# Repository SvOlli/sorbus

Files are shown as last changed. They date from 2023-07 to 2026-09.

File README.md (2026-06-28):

The Sorbus Computer
===================

The attempt to build a very simple 65C02 based computer by utilizing a
Raspberry Pi Pico clone for the rest of the functionality. More
documentation is available at
[https://sorbus.xayax.net/](https://sorbus.xayax.net/).

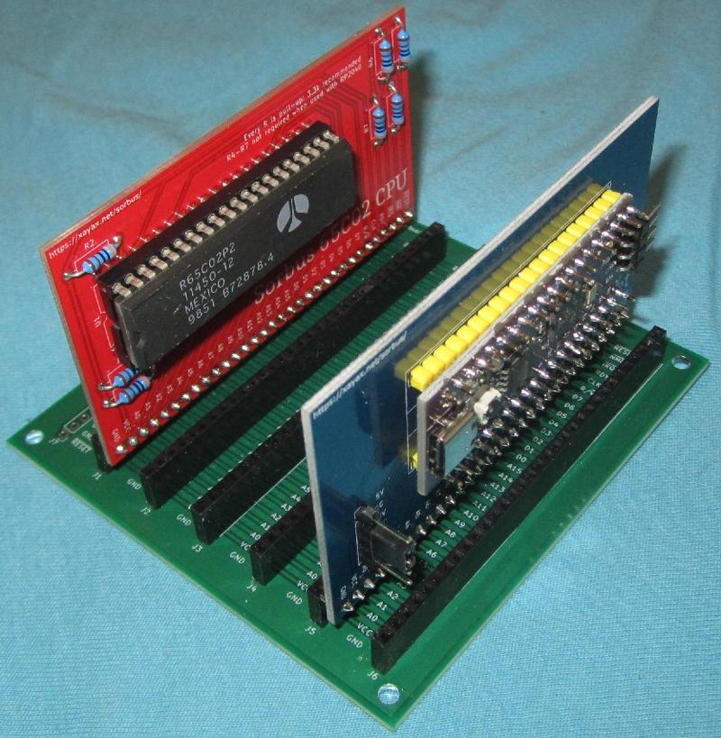
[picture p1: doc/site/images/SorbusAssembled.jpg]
Sorbus assembled

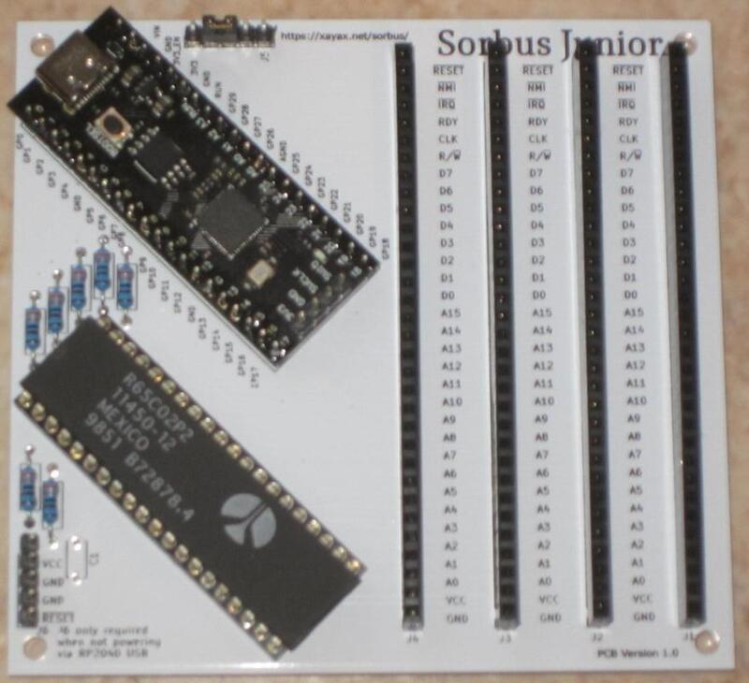
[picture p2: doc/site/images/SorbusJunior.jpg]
Sorbus Junior


The Project is capabile to run as an [Apple Computer 1](doc/site/apple1.md)
as well as an own monitor command prompt (mcp) to learn about the 65C02
processor and it siblings. However now the main focus is now on creating
a custom computer, using a code called "JAM" (Just Another Machine).

The project is fully open source, licensend under GPL v3:
  - the PCB design is in the folder pcb/
    - the Raspberry Pi Pico clone is found under the term "Purple PR2040"
      on AliExpress and other sites
    - the clone is used because all GPIOs of the RP2040 are required
  - the 65C02 source code to run on the target is at src/65c02/
    - compiling requires the [cc65](https://cc65.github.io/), which
      needs to be preinstalled.
  - the source code for the Raspberry Pi Pico clone is at `src/rp2040/`
    - compiling requires the
      [Pico-SDK](https://github.com/raspberrypi/pico-sdk) from the
      Raspberry Pi Foundation, which will be downloaded if not previously
      configured. However it's dependencies must also be preinstalled.
  - for generating the CP/M-65 filesystem
    [cpmtools](https://github.com/lipro-cpm4l/cpmtools) is also required

[An addtional page](https://xayax.net/sorbus/) has been setup to explain more
about the ideas of the system, as well as some usecases.

Also there is now an
[independent review](http://retro.hansotten.nl/the-sorbus-computer/)
available at the wonderful
[Retro Computing pages](http://retro.hansotten.nl/) of Hans Otten.

As part of creating a full featured computer, there are also two expansion
boards developed here: a sound card, called "Sorbus Sound" and a graphics
card, called "Sorbus VGA".

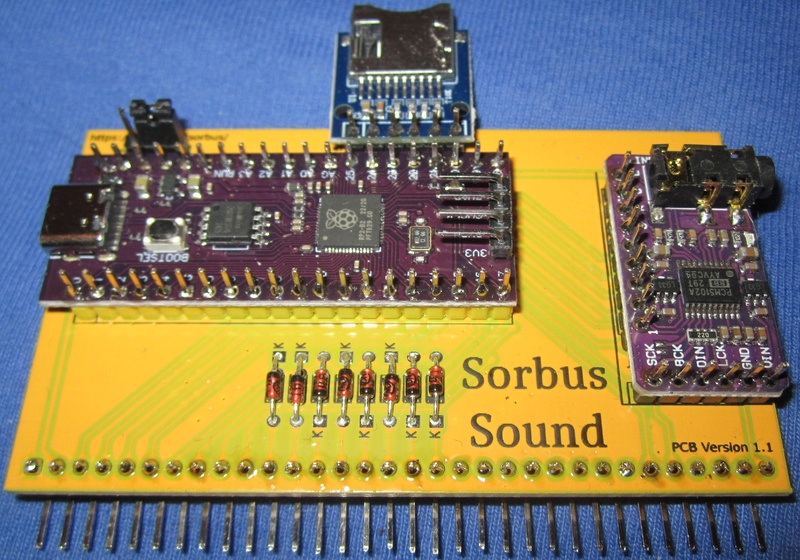
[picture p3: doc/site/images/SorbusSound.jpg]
Sorbus Sound

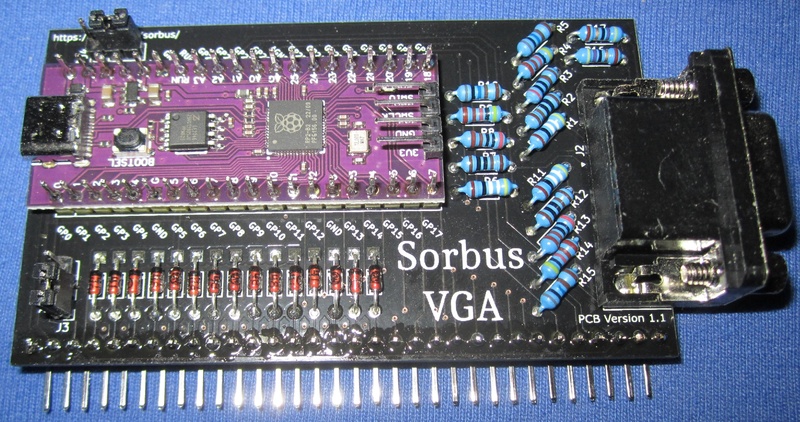
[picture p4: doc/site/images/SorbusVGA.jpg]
Sorbus VGA


To access the RP2040 without super user rights, make sure that your user is
in the groups "plugdev" and "dialout". You also need to add a udev rule. This
is available as part of picotool in the `udev` folder.

Build Targets
-------------

The toplevel `Makefile` is added as a convenience layer to build things more
easily. It wraps the call of `cmake` and `make` to configure the Raspberry Pi
Pico project, as well as some other useful things. The following make targets
are available:

  - make all
    - checks for availablilty of the Pico SDK and downloads it, if required
    - creates a new build directory
    - wraps the call to `cmake` and `make` to build the project
  - make log
    - almost same as "all"
    - more verbose compilation, e.g. compiler calls with parameters
    - creates a file `make.log`
  - make clean
    - runs a `make clean` on build directory
  - make distclean
    - removes build directory entirely to force restart from scratch
  - make setup-apt-build-only
    - installs packages on Debian required to build the project
    - used by git actions to prepare building of a release
  - make setup-apt-dev
    - runs "setup-apt-build-only", as well as doing modifications to
      make sure that terminal and all host dev packages are installed,
      so picotool is compiled with support for transferring software
  - make picotool
    - checks out and builds picotool
    - however there this has been superseded by
      src/tools/local-picotool.sh (and src/tools/local-nstow.sh)
  - make setup-external
    - sets up tools required to build external code, like
      - [CP/M 65](https://github.com/davidgiven/cpm65) (requires
        [llvm-mos-sdk](https://github.com/llvm-mos/llvm-mos-sdk))
      - [TaliForth2](https://github.com/SamCoVT/TaliForth2)
        (requires [64tass](https://tass64.sourceforge.net/))
  - make release
    - used by git action to build a release

There are also some build scripts available for special cases:

  - src/tools/upload.sh
    - script used to build and transfer software using picotool
      (needs rewrite)
    - defaults to uploading the JAM core
  - src/tools/external-taliforth2.sh
    - script to checkout, build and install the TaliForth2
      binary ready for building the filesystem image
    - only required for native core
  - src/tools/external-cpm65.sh
    - script to checkout, build and install the files required
      to include CP/M 65 into the filesystem image
    - only required for native core

It is also possible to build C programs using cc65 for this computer. This
is rather a proof of concept that a full featured implementation, but it
does work rather stable. More details are in it's own
[README](cc65-sdk/README.md).

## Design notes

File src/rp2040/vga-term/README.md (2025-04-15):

https://github.com/RC2014Z80/picoterm.git

todo
====

- remove pio_fatfs
- change uart -> $01

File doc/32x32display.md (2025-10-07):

Sorbus 32x32 LED Display
========================

The panels built so far use this order of LEDs.

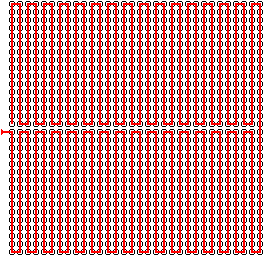
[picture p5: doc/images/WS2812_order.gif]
LED order


I/O Registers
-------------

I/O utilizes the page $D3xx. All registers are write only, as the hardware
only sniffes the bus and never actively drives it.

- $D300: DMA into framebuffer and flush (strobe register)
- $D301: DMA into framebuffer without flush (strobe register)
- $D302/3: start address of RAM source
- $D304/5: startpixel of framebuffer target (10 bit, absolute address)
- $D306/7: startpixel of framebuffer X/Y format (5 bit each)
- $D308: width of DMA in pixels-1 (5 bit, $00=one pixel, $1f sets a full line)
- $D309: height of DMA in pixels-1 (5 bit, $00=one line, $1f sets full height)
- $D30A: linestep of source in pixels-1 (8 bit)
- $D30B: transparency color
- $D30C: colormap
- $D30D: custom colormap id register (valid value: 1-3)

- $D310: red color for custom colormap
- $D311: green color for custom colormap
- $D312: blue color for custom colormap

(defaults are starting at $d302: $00,$cc,$00,$00,$00,$00,$1f,$1f,$1f,$00,$00)

If not all bits of a register are required, those will be masked out/ignored.

Value written do $D300/1 indicades mode (can be or'ed together):
- $00: plain copy
- $01: transparency: no copy when source color = transparent
- $02: transparency: no copy when destination color = transparent
- $04: transparency: only copy when destination color = transparent
- $06: do nothing

Color palettes:
- $00: Insane's RGBI2222
- $01: Custom 1
- $02: Custom 2
- $03: Custom 3
- $04: C64 like
- $05: C16 like
- $06: Atari 8-bit like
- $07: Atari 8-bit like, ordered differently
- $08: Veto's custom curated
- $09: Coder colors

Custom defined color palettes are always specified in RGB444. Writing
to $D30D resets internal index of $D310-$D312 to $00, when a colorvalue
is written, lower 4 bits will be taken as value for this index, and the
index will be incremented. Once $100 color values has been written,
that color slot does not take new color values. Adding $80 to the index
value will fill the palette in reverse order starting with $ff going
down. If a value other than $01-$03 and $81-$83 is written to $D30D,
then $D310-$D312 will not accept any data.

Also selecting the colormap by writing to $D30C copies the palette to the
"current palette", so only then the data is updated not during writing to
$D310-$D312.

Since the board just sniffes the bus, DMA from internal drive or swap
pages is not detected.

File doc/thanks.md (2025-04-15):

Thanks
======

This project is standing on the shoulder of giants. While it was started from
scratch, a lot of other code got integrated.

A lot of code was contributed from other sources, sometimes even without
the knowledge of the author(s).

This project uses software that was developed under non-free licenses.

65(C)02 Based Code
------------------

All of this code has been modified to some degree to fit this project, the
Sorbus Computer. The focus is always on make things work good on the hardware
and not on keeping code as original as possible.

### MOS TIM

* [src/65c02/jam/rom/tim.s](../src/65c02/jam/rom/tim.s)

This is the Terminal Interface Monitor (TIM) of the MOS 6530-004.
```
Copyright 1976 MOS Technology
```
License terms: unknown

### WozMon

* [src/65c02/jam/rom/woz.s](../src/65c02/jam/rom/woz.s)

This is WozMon of the Apple 1 Computer
```
Written by Steve Wozniak
Copyright 1976 Apple Computer Company
```
License terms: unknown

### Apple direct assembler/disassembler

* [src/65c02/jam/mon/assembler.s](../src/65c02/jam/mon/assembler.s)
* [src/65c02/jam/mon/disassembler.s](../src/65c02/jam/mon/disassembler.s)
* [src/65c02/jam/mon/table6502.s](../src/65c02/jam/mon/table6502.s)
* [src/65c02/jam/mon/table65sc02.s](../src/65c02/jam/mon/table65sc02.s)

```
Apple //c & Apple II
Monitor ROM Source

Copyright 1977-1983 by Apple Computer, Inc.
All Rights Reserved

S. Wozniak         1977
A. Baum            1977
John A         NOV 1978
R. Auricchio   SEP 1982
E. Beernink        1983
```
License terms: unknown

### Microsoft BASIC 1.0

* [src/65c02/jam/rom/osi_basic.s](../src/65c02/jam/rom/osi_basic.s)

```
This is OSI BASIC V1.0 REV 3.2
Written by Richard W. Weiland
Copyright 1977 Microsoft Co.
```
It has been used with computers manufactured by
[Ohio Scientific Inc.](https://en.wikipedia.org/wiki/Ohio_Scientific)

Reverse engineering was started by Michael Steil
Source code is based on version by Grant Searle for his simple 6502 computer.

License terms: unknown

### Instant Assembler

* [src/65c02/jam/sx4/inst-ass.s](../src/65c02/jam/sx4/inst-ass.s)

This is Instant 6502 Assembler for KIM-1
```
Written by Alan Cashin
```
License terms: released as public domain

RP2040 Code
-----------

### Dhara - NAND flash management layer

* [src/rp2040/3rdparty/dhara](../src/rp2040/3rdparty/dhara)

```
Dhara - NAND flash management layer
Copyright (C) 2013 Daniel Beer <dlbeer@gmail.com>
```
License terms: BSD-2-Clause

### Mod Player

* [src/rp2040/3rdparty/c-flod](../src/rp2040/3rdparty/c-flod)

```
Christian Corti
Neoart Costa Rica
```
License terms: Creative Commons Attribution-Noncommercial-Share Alike 3.0

### SID Emulation

* [src/rp2040/3rdparty/reSID16](../src/rp2040/3rdparty/reSID16)

```
Dag Lem: Designed and programmed complete emulation engine.
```
License terms: GPL 2.0

### FAT Filesystem

* [src/rp2040/3rdparty/fatfs](../src/rp2040/3rdparty/fatfs)

```
Copyright (c) 2020-2021, Elehobica
```
License terms: BSD-2-Clause

### PicoTerm

[src/rp2040/vga-term](../src/rp2040/vga-term)

```
Copyright 2023 by S.Dixon & D.Meurisse
```
License terms: BSD-3-Clause

### Raspberry Pi Pico Examples

On several occasions things were taken from Raspberry Pi Pico examples:
```
Copyright (c) 2020 Raspberry Pi (Trading) Ltd.
```
License terms: BSD-3-Clause

Special Thanks
--------------

- Benson of Tristar & Red Sector inc. for a lot of contributions
- David Given, author of CP/M for the 6502
  - provided an operating system for the Sorbus
  - helped on implementing the dhara wear leveling for the flash
- [Life with David](https://www.youtube.com/@LifewithDavid1)
  - Especially [PIO examples](https://github.com/LifeWithDavid/Raspberry-Pi-Pico-PIO)
- Hans Otten
  - [http://retro.hansotten.nl](http://retro.hansotten.nl) is one of the best
    resources on SBCs from the 1970s and 1980s.

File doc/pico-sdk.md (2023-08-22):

Linklist of most frequently visited Pico-SDK documentation pages
----------------------------------------------------------------

* [gpio](https://www.raspberrypi.com/documentation/pico-sdk/gpio_8h.html)
* [queue](https://www.raspberrypi.com/documentation/pico-sdk/queue_8h.html)
* [runtime](https://www.raspberrypi.com/documentation/pico-sdk/runtime.html)
* [cyw43 (wifi)](https://www.raspberrypi.com/documentation/pico-sdk/cyw43_8h.html)

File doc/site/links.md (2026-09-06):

# Links

## Beyond The Scope Of This Documentation

* [GitHub Repository](https://github.com/SvOlli/sorbus)
* [Self-Hosted Backup Repository](https://git.h8u.de/Sorbus/github)
* [Original Homepage](https://xayax.net/sorbus/)

## Videos

* [37C3 Lightning Talk (2023)](https://xayax.net/sorbus/lightning1.php)
* [Revision Seminar (2025)](https://youtu.be/5KmBh-jR7Vs)
* [1k LEDs Is No Limit (2025)](https://xayax.net/1k_leds_is_no_limit/),
  a demo running on the Sorbus Computer with a Sound Board and 32x32 WS2812
  LEDs expansion.

## Other People

* [Hans Otten's Series Of Pages](http://retro.hansotten.nl/the-sorbus-computer/)

## Helpful Sites

* [Compiler Explorer](https://godbolt.org/), select ARM GCC 12.2.1
  -mcpu=cortex-m0plus -mthumb -mfloat-abi=softfp -g -O3 -DNDEBUG
  -Wunused-variable -ffunction-sections -fdata-sections

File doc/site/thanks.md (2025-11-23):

# Thanks

This project is standing on the shoulder of giants. While it was started from
scratch, a lot of other code got integrated during the development.

A lot of code was contributed from other sources, sometimes even without
the knowledge of the author(s).

This project uses software that was developed under non-free licenses.

## 65(C)02 Based Code

All of this code has been modified to some degree to fit this project, the
Sorbus Computer. The focus is always on make things work good on the hardware
and not on keeping code as original as possible.

### MOS TIM

This is the Terminal Interface Monitor (TIM) of the MOS 6530-004.
```txt
Copyright 1976 MOS Technology
```
License terms: unknown

* src/65c02/jam/rom/tim.s

### WozMon

This is WozMon of the Apple 1 Computer
```txt
Written by Steve Wozniak
Copyright 1976 Apple Computer Company
```
License terms: unknown

* src/65c02/jam/rom/woz.s

### Apple Direct Assembler/Disassembler And Monitor

```txt
Apple //c & Apple II
Monitor ROM Source

Copyright 1977-1983 by Apple Computer, Inc.
All Rights Reserved

S. Wozniak         1977
A. Baum            1977
John A         NOV 1978
R. Auricchio   SEP 1982
E. Beernink        1983
```
License terms: unknown

* src/65c02/jam/mon/assembler.s
* src/65c02/jam/mon/disassembler.s
* src/65c02/jam/mon/table6502.s
* src/65c02/jam/mon/table65sc02.s
* src/65c02/jam/sx4/wozmon2c.s

### Microsoft BASIC 1.0

```txt
This is OSI BASIC V1.0 REV 3.2
Written by Richard W. Weiland
Copyright 1977 Microsoft Co.
```
It has been used with computers manufactured by
[Ohio Scientific Inc.](https://en.wikipedia.org/wiki/Ohio_Scientific)

Reverse engineering was started by Michael Steil
Source code is based on version by Grant Searle for his simple 6502 computer.

License terms: MIT (version 1.1 which also includes OSI)

* src/65c02/jam/rom/osi_basic.s

### Instant Assembler

This is Instant 6502 Assembler for KIM-1
```txt
Written by Alan Cashin
```
License terms: released as public domain

* src/65c02/jam/sx4/inst-ass.s

## RP2040 Code

### Dhara - NAND flash management layer

```txt
Dhara - NAND flash management layer
Copyright (C) 2013 Daniel Beer <dlbeer@gmail.com>
```
License terms: BSD-2-Clause

* src/rp2040/3rdparty/dhara

### mcurses lib

```txt
Copyright (c) 2011-2015 Frank Meyer - frank(at)uclock.de
```
License terms: GPL v2 or later

* src/rp2040/common/mcurses.c
* src/rp2040/common/mcurses.h
* src/rp2040/common/mcurses_hexedit.c

### XModem

```txt
Copyright 2006 Arastra, Inc.
Copyright 2001, 2002 Georges Menie (www.menie.org)
```
License terms: LGPL v2 or later

* src/rp2040/3rdparty/xmodem/xmodem.c
* src/rp2040/3rdparty/xmodem/xmodem.h
* src/rp2040/common/xmodem.c

### Mod Player

```txt
Christian Corti
Neoart Costa Rica
```
License terms: Creative Commons Attribution-Noncommercial-Share Alike 3.0

* src/rp2040/3rdparty/c-flod

### SID Emulation

```txt
Dag Lem: Designed and programmed complete emulation engine.
```
License terms: GPL 2.0

* src/rp2040/3rdparty/reSID16

### FAT Filesystem

```txt
Copyright (c) 2020-2021, Elehobica
```
License terms: BSD-2-Clause

* src/rp2040/3rdparty/fatfs

### PicoTerm

```txt
Copyright 2023 by S.Dixon & D.Meurisse
```
License terms: BSD-3-Clause

* src/rp2040/vga-term

### Raspberry Pi Pico Examples

On several occasions things were taken from Raspberry Pi Pico examples:
```txt
Copyright (c) 2020 Raspberry Pi (Trading) Ltd.
```
License terms: BSD-3-Clause

## Special Thanks

- Benson of [Tristar & Red Sector inc.](https://trsi.org/) for a lot of
  contributions
- David Given, author of [CP/M for the 6502](https://github.com/davidgiven/cpm65)
    - provided an operating system for the Sorbus
    - helped on implementing the dhara wear leveling for the flash
- [Life with David](https://www.youtube.com/@LifewithDavid1)
    - especially for his [PIO examples](https://github.com/LifeWithDavid/Raspberry-Pi-Pico-PIO)
- Hans Otten
    - [http://retro.hansotten.nl](http://retro.hansotten.nl) is one of the best
      resources on SBCs from the 1970s and 1980s.

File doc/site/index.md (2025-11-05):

# The Sorbus Computer

The Sorbus Computer is a small, cheap, and expandable computer based upon
the [6502](https://en.wikipedia.org/wiki/MOS_Technology_6502) or rather
the [65C02](https://en.wikipedia.org/wiki/WDC_65C02) CPU and an
[RP2040](https://en.wikipedia.org/wiki/RP2040) microcontroller from
Raspberry Pi. It is fully open source, the [source code is available
at GitHub](https://github.com/SvOlli/sorbus).

The means that even the hardware is for the most part software written
in C. The kernel for the 65C02 is written using the ca65 assembler from
the [cc65](https://github.com/cc65/cc65) cross-compiler suite.

While the original implementation of the machine was distributed among
three PCBs, the current iteration (called the Junior) has merged those
three boards into a single one.

Sorbus Junior

## What can it be used for?

It's good for a couple of things. Even more than I expected, when I
first built this machine. Here are a few suggestions:

### Understanding The 6502 Processor Family

There is a [course devided into a couple of sessions](mcp/lessons.md)
that takes a dive into understanding how the CPU works by looking at
what happens on the bus during each clock cycle. For this a tailored
firmware (core) called [MCP](mcp/index.md) has been written.

### Running The Replica Of An Apple 1 Computer

Ever wanted to know, how you would have worked with an Apple 1? Here
is how you can [try this out](apple1.md). It's more cumbersome that
you'd probably think.

### Implement Your Own Design Of An 8-Bit Computer

A lot of example code is already available. And this is more fun, than
you'd probably think. I know, because I did this

### Running The Sorbus JAM Core To Have A Capable 8-Bit Computer

The Sorbus JAM is the core designed especially for this hardware. It
includes a 4MB mass storage device utilizing the flash of the RP2040
board. Ir's capable of running
[CP/M 65](https://github.com/davidgiven/cpm65),
[TaliForth2](https://github.com/SamCoVT/TaliForth2),
[Microsoft BASIC 1.0](https://github.com/mist64/msbasic), several
machine language monitors, and a couple of other things.

It can also run [demos](https://en.wikipedia.org/wiki/Demoscene) as you
can see here: [1k LEDs Is No Limit](https://xayax.net/1k_leds_is_no_limit/).

## Why The Name "Sorbus"?

I liked following the tradition to name it after a fruit. Think about it:
it uses a Raspberry (Pi) and can run like an Apple (1). However most
fruits were already "taken". So, then I remembered the German
"Vogelbeeren" that were around in my childhood. My mother always told me:
"Do not eat those, they are poisonous!" She was a bit exaggerating there,
as the "only" make you sick in the stomach, and don't cause and serious
health issue you. However, I still played with them, throwing them around
and other things that kids do.

So, this is a very fitting name for this computer: it's something you play
with, but not for the "primary use" of a computer, like word processing.
I looked up for a good translation and found
[Sorbus](https://en.wikipedia.org/wiki/Sorbus). Also, here is an [image
provided by Sir Garbagetruck](images/SorbusPlant.jpg).

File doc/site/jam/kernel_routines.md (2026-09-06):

# Kernel Routines

(TODO before release: clean up here and add labels from jam_bios.inc)

## Jumptable

### CHRIN ($FF00): read char

```txt
; $FF00: read a character from UART in A, returns C=1 when queue is empty
CHRIN    := $FF00
```
Read a character from the UART.

returns:

- carry: clear = A contains valid data, set = no data available
- A: read char

### CHROUT ($FF03): write char

```txt
; $FF03: write a character from A to UART
CHROUT   := $FF03
```

Write the content of A to the UART.

returns:

- nothing

### PRINT ($FF06): print

```txt
; $FF06: print a string
; usage:
; jsr PRINT
; .byte "text", 0
; this routine saves all CPU registers, including P, so it can be used for
; debugging messages
PRINT    := $FF06
; PRIMM is a common used synonym for PRINT here
PRIMM    := PRINT
```

Writes a string followed by the JSR, terminated with a $00 byte to the
terminal. Usage is like this (code for ca65):

```asm65c02
   jsr $FF06
   .byte "hello world",10
   .byte 0
   ; continue code here
```

The best part about this routine is that _everything_ gets saved. Even
the processor status. This means that this routine can be used for
debugging prints.

## Software Interrupts

All interrupts are named, names defined in `src/65c02/jam/jam_bios.inc`.
This include also contains a wrapper `INT` which should be used instead
of the `BRK` opcode for kernel interrupts. Possible arguments are:

### MONITOR ($00)

#### jump to System Monitor

```txt
; jump into system monitor
; this is also configured as the default for INTUSER
.define MONITOR   $00
```

This stops the current program and jumps into the
[system monitor](sysmon.md)
The program can then be continued by entering the "G" command.

### CHRINUC ($01)

#### wait for key and return it uppercase

```txt
; wait for input from CHKIN and convert it to uppercase
; in:
; -
; out:
; A: character read
.define CHRINUC   $01
```

This is a convenience function intended for menus and alike. It will
wait for a key press, converts it to uppercase and returns it as A.

### CHRCFG ($02)

#### set UART configuration parameters

```txt
; configure CHRIN/CHROUT behaviour
; in:
; A: bits to set
; X: bits to clear (done first)
; out:
; A: previous state of config
.define CHRCFG    $02
```

### PRHEX8 ($03)
#### output accumulator as 2 digit hex value

```txt
; print out an 8 bit hex value
; in:
; A: value
; out:
; -
.define PRHEX8    $03
```

### PRHEX16 ($04)
#### output X and accumulator as 4 digit hex value

```txt
; print out an 8 bit hex value
; in:
; X: value hibyte
; A: value lobyte
; out:
; -
.define PRHEX16   $04
```

### CPMNAME ($05)
#### CP/M-fs set filename: convert filename (pointer in X/A), Y=userid

```txt
; used by CPM filesystem routines
.define CPM_FNAME $0300
.define CPM_SADDR CPM_FNAME+$0c
.define CPM_EADDR CPM_FNAME+$0e
; full memory block starts at $0300-$035a
; (more if a file is loaded that is larger than 64k)
; during save, the memory $0200-$02ff is used for available blocks map

; convert a filename from "NAME.EXT" to format required for load/save/delete
; in:
; A: pointer to filename lo
; X: pointer to filename hi
; Y: user partition ($00-$0f)
; out:
; -
; $0300-$030b: filename in format: St F0 F1 F2 F3 F4 F5 F6 F7 E0 E1 E2
.define CPMNAME   $05
```

Like on the commodore, the file handling is separated into a few routines.
This routine sets the file name. This is required for load save and delete.

### CPMLOAD ($06)
#### CP/M-fs load: load file to address in ($030c/d)

```txt
; load a file from internal drive CP/M filesystem
; in:
; -
; $0300-$030b: filename as prepared by CPMNAME
; $030c: load address lo
; $030d: load address hi
; out:
; C=1 on error
; NOTE: can only load full sectors (128 bytes)
.define CPMLOAD   $06
```

The load and save are done using DMA transfers. Those can only copy a
full sector of 128 bytes per DMA. So, if the last sector of a save is
only partially used, still the whole 128 bytes are written to storage,
even though the directory entry contains the correct size of the file.
The load routine does the same: it loads a full 128 bytes sector
overwriting memory with an usused part of the file. The end address of
the file in address ($030e/f) does state the correct end, but up to 127
bytes after that address might be corrupted!

### CPMSAVE ($07)
#### CP/M-fs save: save file from address in ($030c/d) to ($030e/f)

```txt
; save a file to internal drive CP/M filesystem
; in:
; -
; $0300-$030b: filename as prepared by CPMNAME
; $030c: start address lo
; $030d: start address hi
; $030e: end address + 1 lo
; $030f: end address + 1 hi
; out:
; C=1 on error
; NOTE: can only save full sectors (128 bytes)
.define CPMSAVE   $07
```

This works similar the CPMLOAD, except that the file is saved and not
loaded.

### CPMERASE ($08)
#### CP/M-fs erase: delete file

```txt
; erase a file on internal drive CP/M filesystem
; in:
; -
; $0300-$030b: filename as prepared by CPMNAME
.define CPMERASE  $08
```

This works similar the CPMLOAD, except that the file is erased and not
loaded.

### CPMDIR ($09)
#### CP/M-fs directory: load directory to address in ($030c/d) or console ($030d=$00)

```txt
; load or display internal drive CP/M filesystem directory
; in:
; Y: user partition ($00-$0f)
; $030c: load address lo
; $030d: load address hi
; if load address hi = $00 display on screen using CHROUT
.define CPMDIR    $09
```

The following rountine will print out the directory on the screen:

```asm65c02
   ldy #$0a    ; user number
   stz $030d
   brk #$09
```

When loading to memory data records are 16 bytes of size:

- $00: user number
- $01-$08: filename, padded with spaces
- $09-$0B: extension, padded with spaces
- $0c: $00
- $0d: number of bytes in final sector ($00 = full sector)
- $0e/$0f: number of sectors (lo/hi)

### VT100 ($0A)
#### VT100: several screen functions: Y=specify function (see below)

```txt
; render VT100 escape sequences
; Y: sequence id (see below)
.define VT100     $0A

.define VT100_CPOS_SET $00 ; set cursor pos (in: X=col, A=row, 1 based)
.define VT100_CPOS_GET $03 ; get cursor pos (out: X=col, A=row, 1 based)
.define VT100_CPOS_SAV $09 ; save cursor pos
.define VT100_CPOS_RST $0A ; restore cursor pos

.define VT100_SCRL_LIN $01 ; set scroll area in lines (in A=start, X=end)
.define VT100_SCRL_RES $06 ; reset scroll area
.define VT100_SCRL_DWN $07 ; scroll down
.define VT100_SCRL_UP  $08 ; scroll up

.define VT100_COLORS   $02 ; set text attributes (colors)
                           ; (30..37 bgcol, 40..47 fgcol, DECIMAL)
.define VT100_SCRN_CLR $04 ; clear screen
.define VT100_EOLN_CLR $05 ; clear to end of line

.define VT100_CPOS_SOL $FE ; combined functions CPOS_*: goto start of line
.define VT100_SCRN_SIZ $FF ; combined functions CPOS_*: get size of screen
.define VT100_SCRN_CL0 $FD ; combined functions SCRN_CLR: and going to top left
```

VT100 calls are identified by the function number passed via the Y
register. Some functions require / return parameters handed over via the
A and X registers.

- $00: set cursor pos (in: X=col, A=row, 1 based)
- $01: set scroll area (in: A=start, X=end)
- $02: set text attributes (colors) (30..37 bgcol, 40..47 fgcol, DECIMAL)
- $03: get cursor pos (out: X=col, A=row, 1 based)
- $04: clear screen
- $05: clear to end of line
- $06: reset scroll area
- $07: scroll down
- $08: scroll up
- $09: save cursor pos
- $0A: restore cursor pos
- $FD: combined functions: clear screen and go to top left
- $FE: combined functions: go to start of current line
- $FF: combined functions: get size of screen

### COPYBIOS ($0B)
#### copy BIOS ($FF00-$FFFF) from ROM to RAM

```txt
; copy the BIOS ($FF00-$FFFF) from ROM to RAM, so $E000-$FFFF can be banked
; to RAM without losing the functionality of the kernel
; also switches to RAM bank on return
.define COPYBIOS  $0B
```

### LINEINPUT ($0C)
#### input a text line from console (pointer in X/A, Y: size of input ($00-$7F), add $80 for only upper case)

```txt
; input text using a line
; A/X: vector to buffer, if first byte is not $00, edit the content
; Y bit 7=0: bits 0-6: maximum length of input
; Y bit 7=1: bits 0-6 get shifted to 1-7 and are ZP address of config block
; (config block not implemented yet)
; returns:
; Z=0: Ctrl-C, CRSR-up/down, etc.
; Z=1: Return
; Y: input length
; unused end of buffer will be padded with $00 bytes
.define LINEINPUT $0C
```

### GENSINE ($0D)
#### fill a page of RAM with sine data

```txt
; generate a sine table
; A=bits 0-4: size ($01-$10)
;   bit    5: write decimal parts to following page
;   bits 6-7: variant (offset in 90 degrees)
; X=page for table
.define GENSINE   $0D
```

input data:

- A: bits 7,6 offset, 5 fractions, 4-0 amplitude ($01-$10)
- X: page

Example:

```asm65c02
   lda #$10
   ldx #$cf
   int GENSINE
```

After that run the system monitor an examine the $CFxx page:

```txt
>mcf00 d000
 :CF00  FF FF FF FF FF FF FE FE  FD FD FC FB FB FA F9 F8  ................
 :CF10  F7 F6 F5 F4 F2 F1 F0 EE  ED EB EA E8 E6 E4 E2 E0  ................
 :CF20  DE DC DA D8 D6 D4 D1 CF  CC CA C7 C4 C2 BF BC B9  ................
 :CF30  B6 B3 B0 AD A9 A6 A3 9F  9C 98 95 91 8D 89 85 81  ................
 :CF40  7E 7A 76 72 6E 6A 67 63  60 5C 59 56 52 4F 4C 49  ~zvrnjgc`\YVROLI
 :CF50  46 43 40 3D 3B 38 35 33  30 2E 2B 29 27 25 23 21  FC@=;8530.+)'%#!
 :CF60  1F 1D 1B 19 17 15 14 12  11 0F 0E 0D 0B 0A 09 08  ................
 :CF70  07 06 05 04 04 03 02 02  01 01 00 00 00 00 00 00  ................
 :CF80  00 00 00 00 00 00 01 01  02 02 03 04 04 05 06 07  ................
 :CF90  08 09 0A 0B 0D 0E 0F 11  12 14 15 17 19 1B 1D 1F  ................
 :CFA0  21 23 25 27 29 2B 2E 30  33 35 38 3B 3D 40 43 46  !#%')+.0358;=@CF
 :CFB0  49 4C 4F 52 56 59 5C 60  63 67 6A 6E 72 76 7A 7E  ILORVY\`cgjnrvz~
 :CFC0  81 85 89 8D 91 95 98 9C  9F A3 A6 A9 AD B0 B3 B6  ................
 :CFD0  B9 BC BF C2 C4 C7 CA CC  CF D1 D4 D6 D8 DA DC DE  ................
 :CFE0  E0 E2 E4 E6 E8 EA EB ED  EE F0 F1 F2 F4 F5 F6 F7  ................
 :CFF0  F8 F9 FA FB FB FC FD FD  FE FE FF FF FF FF FF FF  ................
```

See, there now is a nice cosine. The offset moves it by $40 bytes. The
amplitude can be made smaller, so the value spectrum is not $00-$FF
anymore.

### ASCEND256 ($0E)
#### fill page with an ascending order of bytes

```txt
; fill a page with an ascending number of 256 values
; in:
; X=page for table
; out:
; -
.define ASCEND256 $0E
```

so low byte matches data byte (X: page)

This allows for some interesting tricks:

```asm65c02
   ldx #$cf
   int ASCEND256
   ; ... some more code ...
   and $cf00,x ; this now performs an AND with the value of the X register
```
Of course, this can be done with all other operations like add, or, eor,
etc. It makes the CPU a bit more versatile, and just costs a page of RAM
and 4(!) bytes of code.

### FB32X32 ($0F)
#### setup FB32x32 LED Matrix (framebuffer start: X/A. Y=$01 clear)

```txt
; set 32x32 pixels framebuffer registers
; Y=$00 reset LED registers to framebuffer @ X/A
; Y=$01 as $00, but also clear framebuffer with $00
.define FB32X32   $0F
```

### SWEET16 ($10)
#### enter SWEET16 interpreter

```txt
; execute SWEET16 code following the BRK
; registers are stored at $E0-$FF
; no parameters modified
.define SWEET16   $10
```

Typically [SWEET16](sweet16.md) is entered using a `JSR`. Here it's
interrupt $10 = 16, so `BRK #16`.

### PRDEC8 ($11)
#### output accumulator as 3 digit decimal value with leading zeros

```txt
; print out an 8 bit decimal value with leading 0s
; in:
; A: value
; out:
; -
.define PRDEC8    $11
```

This behaves roughly like PRHEX8 ($03), except that the value is now
printed as a decimal number. However, it will be always printed as three
digits with leading zeros, so a "7" will always be a "007".

### PRDEC16 ($12)
#### output X and accumulator as 5 digit decimal value with leading zeros

```txt
; print out a 16 bit decimal value with leading 0s
; in:
; X: value hibyte
; A: value lobyte
; out:
; -
.define PRDEC16   $12
```

This behaves roughly like PRHEX16 ($04), except that the value is now
printed as a decimal number. However, it will be always printed as five
digits with leading zeros, so a "7" will always be a "00007".

### USER-INT ($80)
#### jmp ($DF78)

```txt
; will jump using vector UVBRK ($DF78/$DF79)
; will also be triggered by any undefined BRK
; (for own extensions, interrupts >=$80 are reserved)
; default configuration is system monitor
; in/out: depends on user implementation
.define INTUSER   $80
```

For an own interrupt handler invoked via $DF78/9, it is recommended to
use interrupt arguments starting with $80, as those won't be used by the
kernel. Still, _every_ interrupt not handled by the kernel will be
passed on.

Also note that registers are not stored on the stack, but in memory.
So, running an interrupt within an interrupt will corrupt registers.
(It might work with saving $DF2C-$DF2F, but this was not tested yet.)

The default setup for the $DF78 vector is entering the system monitor.

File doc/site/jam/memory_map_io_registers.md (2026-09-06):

# Memory map & I/O Registers

(TODO before release: clean up here and add labels from jam.inc)

## Memory map

- $0000-$0001: graphics port (not implemented yet)
- $0002-$0003: reserved for later use
- $0004-$0007: zeropage RAM reserved for kernel
    - $04/5: temporary vector used for PRINT and CP/M fs
    - $06: save processor status for PRINT
    - $07: save accumulator for PRINT
- $0008-$00FF: zeropage RAM for generic use
    - $0008-$000F: zeropage RAM used by WozMon
    - $00E3-$00FF: zeropage RAM used by TIM
    - $00F6-$00FF: zeropage RAM used by System Monitor
- $0100-$01FF: processor stack
- $0200-$03FF: RAM reserved for kernel (e.g. CP/M fs, VT100)
- $0400-$CFFF: RAM for generic use
- $D000-$DDFF: I/O which can be provided by external boards
- $D000-$D3FF: scratch RAM that can by exchanged with $0000-$03FF
    by writing to $DF03 (not accessable directly from 65C02)
- $DE00-$DEFF: I/O space reserved for future use provided by main RP2040 board
- $DF00-$DFFF: I/O provided by main RP2040 board
- $E000-$FFFF: bank 0 (RAM, used to load CP/M 65)
- $E000-$FFFF: bank 1 (ROM, kernal, custom firmware)
- $E000-$FFFF: bank 2 (ROM, tools e.g. filebrowser)
- $E000-$FFFF: bank 3 (ROM, OSI BASIC)
- $FF00-$FFFF: bankswitching code, BRK handler, I/O routines (BIOS)
    - same on all ROM banks
    - can be copied to RAM using code at $0100 after loading a bootblock
    - is copied to RAM before running SX4 file
    - can also copied to RAM by using BRK #$0B (see below)

## I/O Registers

### Overview

- $0000-$0001: VGA
- $0002-$0003: (reserved)
- $D000-$D2FF: (undefined)
- $D300-$D3FF: 32x32 LED Framebuffer (suggested)
- $D400-$D4FF: Sound: SID clone(s), mod player (suggested)
- $D500-$DDFF: (undefined)
- $DE00-$DEFF: (reserved)
- $DF00-$DF7F: (internal: see below)
- $DF80-$DFFF: (scratch RAM for internal drive access)

### Miscellaneous ($DF00-$DF0F)

- $DF00: (R/W) bank select register for $E000-$FFFF ROM starts at
   bank 1 (default), bank 0 is RAM; more banks can be added, if
   bank set > max_bank, bank is set to default
- $DF01: (R) Sorbus JAM ID -> contains version information, read
   until $00 starts with ASCII id "SBC23", followed by a $01 and a
   revision
- $DF01: (S) trap: stop CPU and jump into debugging console
- $DF02: (R) random value
- $DF03: (W) swap out pages $00-$03: lower four bits contain banks,
    bits 4,5 define mode:
    - $10 --> store
    - $20 --> read
    - $30 --> swap
    bit 7 (R): action ongoing
- $DF04: (R) CPU capabilities using bit set indicate CPU features:
    - $01: NMOS
    - $02: CMOS
    - $04: BIT (RE)SET
    - $08: Z reg
    - $10: 16 bit
    - This means for known CPUs:
    - $01: 6502
    - $06: 65C02
    - $12: 65816
    - $0e: 65CE02
    - $02: 65SC02
- $DF05-$DF0A: reserved for future use
- $DF0B: UART config:
    - bit 0: enable crlf conversion
    - bit 1: enable flow control (removed due to rework)
    - bit 2-3: select auto UTF-8 conversion
        - 00: off
        - 01: standard Sorbus conversion (not fully defined yet)
        - 10: reserved
        - 11: reserved
    - bit 6: overflow in output uart fifo occurred (will be cleared on read)
    - bit 7: overflow in input uart fifo occurred (will be cleared on read)
- $DF0C: (R) UART in queue read
- $DF0D: (R) serial in queue size (up to 250, 255: error)
- $DF0E: (W) serial out queue write
- $DF0F: (R) serial out queue size (up to 127, >127: error)

### Timers ($DF10-$DF1F)

- 8 different 16 bit timers are available allowing for an own timer for
  every combination, see table below
- writing to lowbyte also stops timer
- writing to highbyte also starts timer
- reading from either low- or highbyte shows if timer triggered interrupt
  ($80) and also acknoledges interrupt

| Address | Repeating | Interrupt | Time Source |
| --- | --- | --- | --- |
| $DF10/1 | repeat | IRQ | cycles |
| $DF12/3 | oneshot | IRQ | cycles |
| $DF14/5 | repeat | NMI | cycles |
| $DF16/7 | oneshot | NMI | cycles |
| $DF18/9 | repeat | IRQ | 10ths of ms |
| $DF1A/B | oneshot | IRQ | 10ths of ms |
| $DF1C/D | repeat | NMI | 10ths of ms |
| $DF1E/F | oneshot | NMI | 10ths of ms |

Note: when entering [meta mode](meta_mode.md), the ms based timers will
be cancelled. The will be restarted from their initial value when meta
mode is exited.

### Watchdog ($DF20-$DF23)

Watchdog will be triggered after the specified number of cycles.
However, there is no easy way to reset the watchdog counter. It needs
to be set again to full value for next "loop".

- counter is 24 bit
- base address: $DF20
- write to base address + 0: turn off
- write to base address + 1: set low counter
- write to base address + 2: set mid counter
- write to base address + 3: set high counter, starts watchdog
- read on $DF20 shows watchdog active (bit7: watchdog running)
- read on $DF20-$DF23 also re-arms the watchdog
- triggered watchdog is handled similar to trap ($DF01)

### Cyclecount ($DF24-$DF27)

- read only 32 bit register
- writing to any address of the range copies the cycle counter to RAM
- intended to be used for measuring speed of code
- address still subject to change

### Variables Used By Kernel ($DF2C-$DF2F)

- $DF2C: bank
- $DF2D: accumulator
- $DF2E: X index register
- $DF2F: Y index register
- $DF76: Z index register (65CE02 userland only, this might change)

This are just variables used during handling an interrupt service call.

### Variables Used By System Monitor ($DF30-$DF3F)

This area of I/O is just used as conventional RAM to store data away from
the area used by conventional programs.

- $DF30: saved PC lo
- $DF31: saved PC hi
- $DF32: bank
- $DF33: accumulator
- $DF34: X index register
- $DF35: Y index register
- $DF36: stack pointer
- $DF37: processor status

### Internal Drive ($DF70-$DF77)

System provides 36864 blocks of 128 bytes = 4.5MB Data stored in flash @
0x10400000 (12MB, ~<6MB payload with wear leveling)

- base address: $DF70
- base address + $0: LBA low
- base address + $1: LBA high
- base address + $2: DMA memory address low
- base address + $3: DMA memory address high
- base address + $4: (S) read sector (strobe, adjusts DMA memory and LBA)
- base address + $5: (S) write sector (strobe, also adjusts)
- base address + $6: (unused, see variables used by kernel)
- base address + $7: (S) flash discard

Valid values are:

- DMA memory start address:
    - $0004-$CF80
    - $DF80-$FF80 (will always use RAM under ROM)
- LBA:
    - $0000-$7FFF (used by CP/M-fs)
    - $8000-$8FFF (reserved for future use, e.g. ROM-able Forth)

Each transfer stops CPU until transfer is completed. Reading from strobe
registers return result of last access. (Bit 7 set indicates error.)
Memory address will be increased by $0080, LBA by $0001 after successful
read or write to prepare for next sector transfer.

### RAM Vectors ($DF78-$DF7F)

These vectors are RAM to support installing own handlers for interrupts

- $DF78/$DF79 user BRK routine (if BRK operand is $00 or out of scope)
- $DF7A/$DF7B NMI ($FFFA/B point to jmp ($DF7A))
- $DF7C/$DF7D user IRQ routine (for handling non-BRK)
- $DF7E/$DF7F IRQ ($FFFE/F point to jmp ($DF7E))

Note: TIM overwrites vectors for own debugging purposes, WozMon doesn't.

#### Interrupt Handling

- $FFFE/F is triggered by IRQ-line or BRK
- jmp ($DF7E) -> default setup to handler in $FF00 area
- handler checks if trigger was IRQ or BRK
- if IRQ -> jmp ($DF7C)
- if BRK get operand after BRK
- if operand is known, perform kernel action
- if operand is out of scope -> jmp ($DF78) (default: System Monitor)

Note: as this handling is rather complex it takes about 100 cycles to
run a software interrupt to call a function. This is the trade-in for
convenience. Also, all registers get saved/restored during a software
interrupt.

### Scratchpad RAM ($DF80-$DFFF)

128 bytes of RAM intended to be used to store a sector from internal
drive, e.g. directory data.

Unused addresses in $DF00-$DF7F behave like RAM, except that they can't
be used with internal drive DMA.

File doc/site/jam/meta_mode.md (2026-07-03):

# Meta-Mode

Pressing `Ctrl+]` (or the backtick `` ` ``) will get you in a "meta-mode"
where the CPU stops. This mode can also be invoked by writing to address
`$DF01` or programming the watchdog timer (see
[Memory Map & I/O Registers](memory_map_io_registers.md#watchdog-df20-df23)
addresses `$DF20-$DF23`). In any case the same meta menu is shown which
provides some information mostly intended for developers. A few entries
there also relate to "monitor commands".

Using terminal escape sequences, the current screen is requested to be
stored and restored when leaving the meta-mode. However, this is relying
on a terminal feature, so if your terminal does not support it, the
output will not be restored.

(Also take note that the firmware is in active developement, so the
screenshots used here might not outdated as compared to the code.)

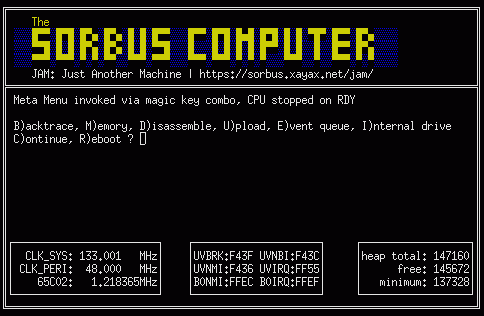
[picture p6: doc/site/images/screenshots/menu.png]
menu


The bottom boxes show some information about the system:

* left: clock frequencies and also the CPU variant detected
* middle: interrupt vectors, "B0" referencing bank 0, which is RAM
* right: memory usage of the RP2040 code

Some information (mostly intended for system developers) is shown as
pop-ups.

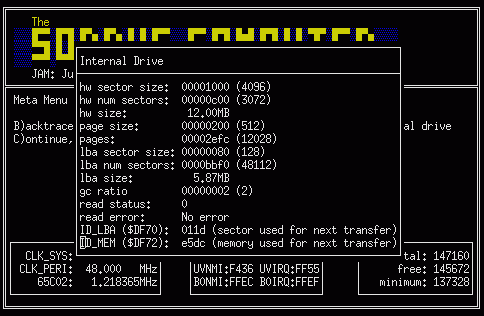
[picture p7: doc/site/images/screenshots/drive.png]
drive


---

## Backtrace

Pressing `B` will show the last 1024 accesses to the bus (aka
CPU cycles). This option will also provide some disassembly. However,
not every line is valid, as an instruction takes several cycles to
execute (up to 8), and the hardware indicating an instruction fetch
(the SYNC pin) could not be utilized. To compensate, a heuristic is
implemented which tries to accomplish the same by analysing the
recorded trace. Still, this is not always 100% accurate.

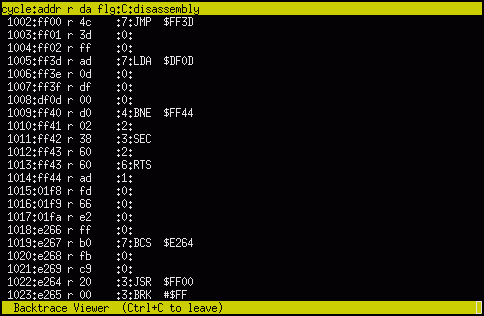
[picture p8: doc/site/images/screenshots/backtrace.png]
backtrace


### Backtrace Columns

| Name | Function |
| --- | --- |
| cycle | artifical number of cpu cycle (aka "linenumber") |
| addr | address being accessed |
| r | indicate if access was read (`r`) or write (`w`) |
| da | data byte being read or written |
| flg | indicate if reset (`R`), IRQ (`I`), NMI (`N`) lines are pulled low  |
| C | confidence of algorithm, that the current line is an instruction |
| disassembly | disassmbled address, if algorithm is confident enough |

### Backtrace Keys

| Key | Function |
| --- | --- |
| UP | move cursor one line up |
| DOWN | move cursor one line down |
| PAGE UP | move cursor one page up |
| PAGE DOWN | move cursor one page down |
| HOME | go to start backtrace |
| END | go to end backtrace |
| S | disassemble from top screen line to buffer end |
| SHIFT+S | disassemble single top screen line |
| Ctrl+L | redraw everything |
| Ctrl+C | leave disassembler |

---

## Disassembler

Pressing `D` will enter the disassembler. This does not show the code
by analysing the last clockcycles executed, but by looking at the memory,
like the disassembler implemented on the 65C02 itself. You can scroll
back and forth through memory. Scrolling back might produce incorrect
output, since the is no 100% bullet proof way to implement this.

Press `Ctrl+C` or `Q` to quit and return to meta menu.

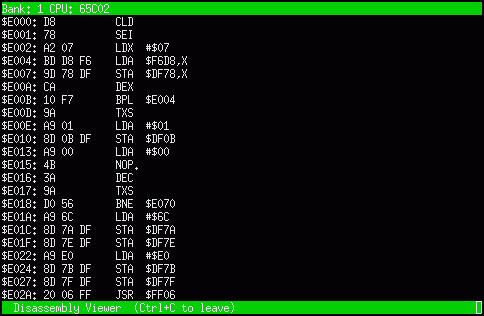
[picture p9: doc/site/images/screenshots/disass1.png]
disass1


Pressing `V`, the disassembler can be switched into a mode where every
byte is shown on it's own line, also adding an ASCII representation. It's
intended to make things easier deciding if you're looking at code or data.
especially when looking at inline text after `JSR $FF06`.

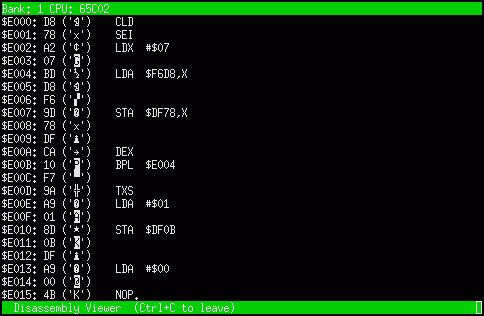
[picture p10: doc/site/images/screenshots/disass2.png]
disass2


When switched to 65816, the keys `M` and `X` switch the different word
sizes of accumulator and index registers, like shown below for the index
registers. (It doesn't make sense in the case of the example code,
though...)

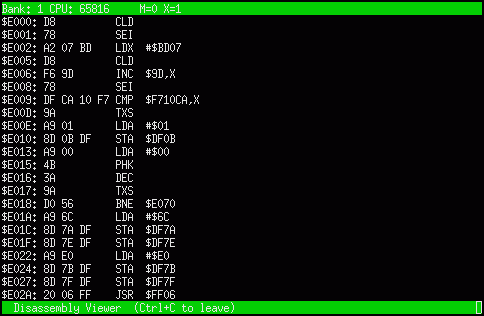
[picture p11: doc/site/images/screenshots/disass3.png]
disass3


### Disassembler Keys

| Key | Function |
| --- | --- |
| UP | move cursor one line up |
| DOWN | move cursor one line down |
| PAGE UP | move cursor one page up |
| PAGE DOWN | move cursor one page down |
| M | switch 65816 "M" flag for disassembly |
| X | switch 65816 "X" flag for disassembly |
| (Ctrl+)P  | switch processor for disassembly |
| (Ctrl+)B  | switch to next bank |
| (Ctrl+)V  | switch view (one byte / instruction per line) |
| (Ctrl+)G  | go to specified address |
| Ctrl+L | redraw everything |
| Ctrl+C | leave disassembler |

---

## Memory Editor

Pressing `M` will enter the memory hex editor. You can move around
freely and change anything you like. Keep in mind that the areas
$0000-$0003 and $D000-$DEFF are I/O address space and cannot be
accessed by the 65C02 directly. The area of $DF00-$DFFF are internal
I/O which uses the underlying memory as cache. Changing values there
will not trigger the I/O functionality, but only chang the cache.

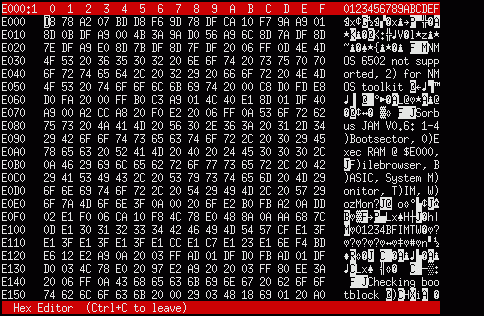
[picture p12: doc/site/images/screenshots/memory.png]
memory


### Memory Editor Keys

| Key | Function |
| --- | --- |
| UP | move cursor one line up |
| DOWN | move cursor one line down |
| PAGE UP | move cursor one page (=256 bytes) up |
| PAGE DOWN | move cursor one page (=256 bytes) down |
| LEFT | move cursor one character / hex value left |
| RIGHT | move cursor one character / hex value right |
| HOME | go to start of line |
| END | go to end of line |
| TAB | switch between hex and ASCII |
| Ctrl+B | switch to next bank |
| Ctrl+G | go to specified address |
| Ctrl+C | leave memory editor |

---

## Upload

Pressing `U` allows to upload a file to memory using the
[XModem](https://en.wikipedia.org/wiki/XMODEM) protocol, after entering
the memory address the contents should be uploaded to.

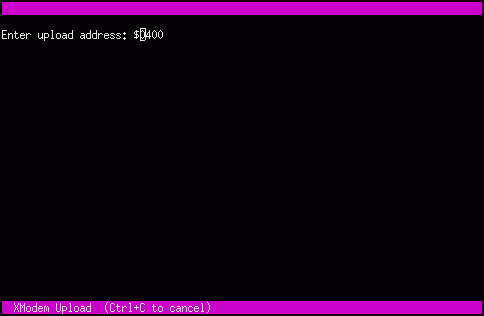
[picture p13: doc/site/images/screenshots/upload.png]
upload


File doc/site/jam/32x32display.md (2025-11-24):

# Sorbus 32x32 LED Display

The panels built so far use this order of LEDs.

## Hardware Setup

The LED hardware is a single string of 1024 WS2812 LEDs created by
concatinating four 16x16 WS2812 panels, which are available on AliExpress
or eBay. The order in the hardcoded translation matrix within the software
looks like this:

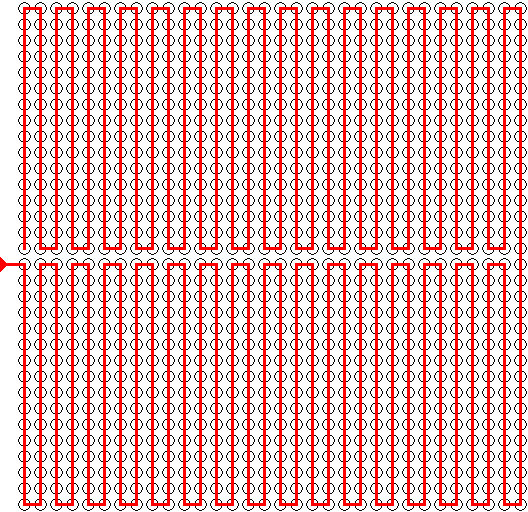
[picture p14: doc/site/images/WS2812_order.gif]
LED order


Note the first LED is roughly at the middle on the left side. If the order
of the LEDs is different in your setup, you need to create a new translation
matrix. An example on how to create one is available as part of the source
code: `src/tools/translation_matrix.c`.

## I/O Registers

I/O utilizes the page $D3xx. All registers are write only, as the hardware
only sniffes the bus and never actively drives it.

- $D300: DMA into framebuffer and flush (strobe register)
- $D301: DMA into framebuffer without flush (strobe register)
- $D302/3: start address of RAM source
- $D304/5: startpixel of framebuffer target (10 bit, absolute address)
- $D306/7: startpixel of framebuffer X/Y format (5 bit each)
- $D308: width of DMA in pixels-1 (5 bit, $00=one pixel, $1f sets a full line)
- $D309: height of DMA in pixels-1 (5 bit, $00=one line, $1f sets full height)
- $D30A: linestep of source in pixels-1 (8 bit)
- $D30B: transparency color
- $D30C: colormap
- $D30D: custom colormap id register (valid value: 1-3)

- $D310: red color for custom colormap
- $D311: green color for custom colormap
- $D312: blue color for custom colormap

(defaults are starting at $d302: $00,$cc,$00,$00,$00,$00,$1f,$1f,$1f,$00,$00)

If not all bits of a register are required, those will be masked out/ignored.

All addresses have been named nicely in `fb32x32_regs.inc`. For convenience,
you can just `.include 'fb32x32.inc'` which will include everything useful
for writing effects: BIOS call, I/O addresses and `fb32x32_regs.inc`.

## Copy Mode

Value written do $D300/1 indicades mode (can be or'ed together):

- $00: plain copy
- $01: transparency: no copy when source color = transparent
- $02: transparency: no copy when destination color = transparent
- $04: transparency: only copy when destination color = transparent
- $06: do nothing

## Color Palettes

| Color | Description | Example |
| :---: | :--- | :--- |
|  $00  | Insane's RGBI2222 | example |
|  $01  | Custom 1 | |
|  $02  | Custom 2 | |
|  $03  | Custom 3 | |
|  $04  | C64 like | example |
|  $05  | C16 like | example |
|  $06  | Atari 8-bit like | example |
|  $07  | Atari 8-bit like, ordered differently | example |
|  $08  | Veto's custom curated | example |
|  $09  | Coder colors (C128 VDC like) | example |

Note that the example colormaps do not reflect the correct brightness of
the colorvalues. Those are just the same values converted to RGB.

Custom defined color palettes are always specified in RGB444. Writing
to $D30D resets internal index of $D310-$D312 to $00, when a colorvalue
is written, lower 4 bits will be taken as value for this index, and the
index will be incremented. Once $100 color values has been written,
that color slot does not take new color values. Adding $80 to the index
value will fill the palette in reverse order starting with $ff going
down. If a value other than $01-$03 and $81-$83 is written to $D30D,
then $D310-$D312 will not accept any data.

Also selecting the colormap by writing to $D30C copies the palette to the
"current palette", so only then the data is updated not during writing to
$D310-$D312.

Since the board just sniffes the bus, DMA from internal drive or swap
pages is not detected.

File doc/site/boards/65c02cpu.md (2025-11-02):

# Sorbus 65C02 CPU

The 65C02 CPU board is just an adapter of the 30 most important pins
of the 65C02 CPU to the Sorbus Backplane bus. Plus a few pull-up
resistors to make sure the CPU doesn't get disturbed by floating
signals.

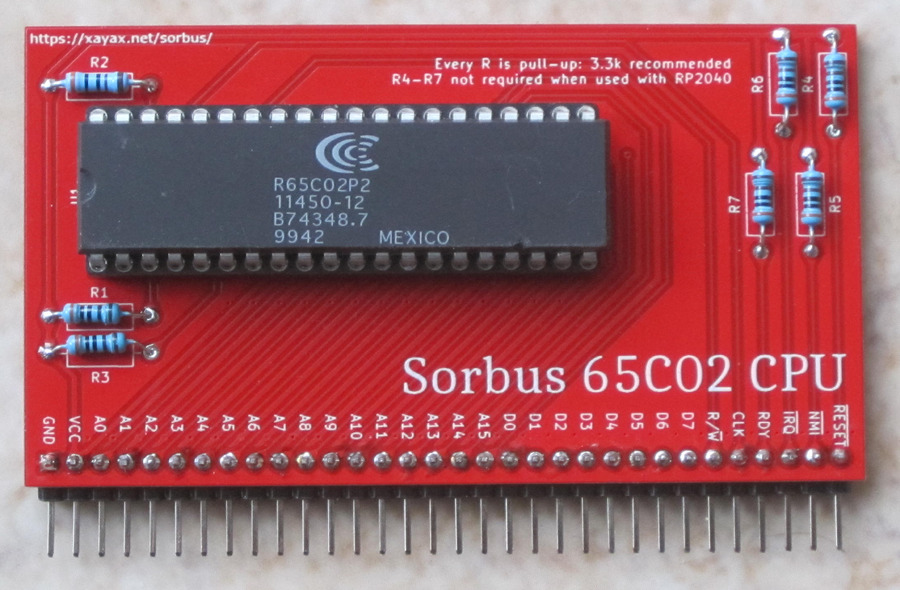
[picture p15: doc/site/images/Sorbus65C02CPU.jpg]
65C02 CPU


- [circuit diagram](Sorbus-65C02.pdf)

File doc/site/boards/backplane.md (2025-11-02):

# Sorbus Backplane

The backplane is the board where everything is plugged in. Just
connecting all pin 1 with each other, same with pin 2 and so on.
Nothing much to it.

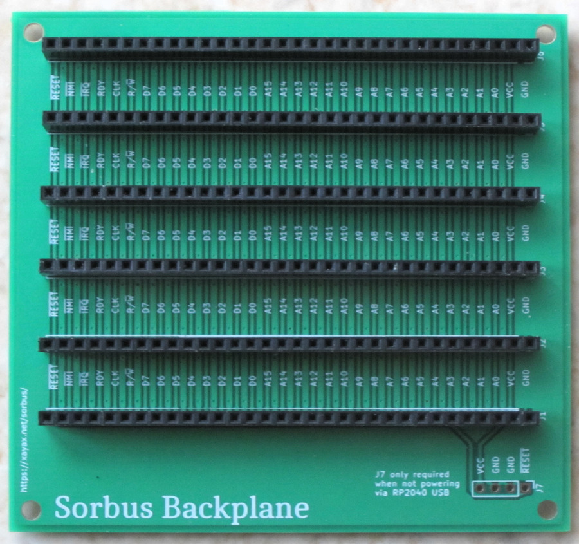
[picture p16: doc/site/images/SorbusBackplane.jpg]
Backplane


- [circuit diagram](Sorbus-backplane.pdf)

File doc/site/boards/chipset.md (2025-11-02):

# Sorbus Chipset

The Chipset CPU board is just an adapter for all 30 GPIO of the "RP2040
Purple Board" to be connected to all pins on the bus, so it can drive
the 65C02 on the [65C02 CPU](65c02cpu.md) board.

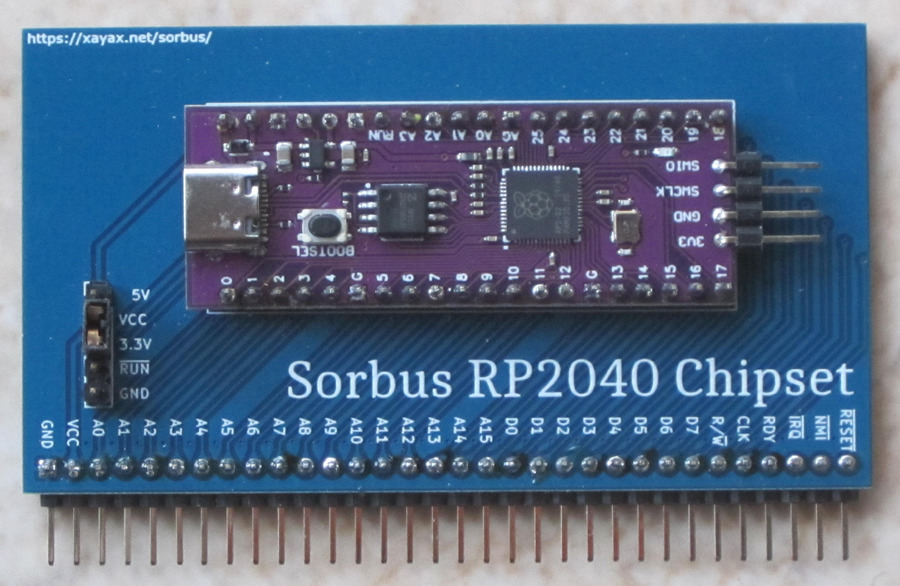
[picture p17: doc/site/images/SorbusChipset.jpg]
Chipset


The Chipset board can also to be hacked to be used as a controller for
a [32x32 WS2812 LED Matrix](../jam/32x32display.md) display. The demo
[1k LEDs Is No Limit](https://xayax.net/1k_leds_is_no_limit/) has been
implemented this way.

- [circuit diagram](Sorbus-Chipset-PurplePico.pdf)

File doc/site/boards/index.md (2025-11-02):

# The Sorbus Computer Boards

All boards are designed using [KiCAD](https://www.kicad.org/). Both the
generated data like schematics, gerber files and the projects themselves
are checked in as part of the source code, so you can fully recreate and
modify the project to your liking.

[Backplane](backplane.md), [65C02 CPU](65c02cpu.md) and
[Chipset](chipset.md) form a complete system, as can be seen below.

The Sorbus Computer

The [Junior](junior.md) is those three boards rolled into one, reducing
cost and solder work to create a base system.

[Sound](sound.md) and [VGA](vga.md) are optional cards to provide audio
and video capabilities. The [Chipset](chipset.md) has also been repurposed
to drive a [32x32 WS2812 LED Matrix](../jam/32x32display.md).

All Sorbus boards created so far:

- [Backplane](backplane.md)
- [65C02 CPU](65c02cpu.md)
- [Chipset](chipset.md)
- [Junior](junior.md)
- [Sound](sound.md)
- [VGA](vga.md)

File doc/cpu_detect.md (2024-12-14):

CPU Detection Routine
=====================

The Sorbus Computer can run any kind of 6502 variant that shares the
same pinout. The small test and learn environment "Monitor Command
Prompt" or MCP for short
([pun](https://en.wikipedia.org/wiki/List_of_Tron_characters#Master_Control_Program)
very intended) can be used to learn all the details about each CPU up
to a certain degree. (Not all pins are connected due to a limited amount
of 30 GPIO pins on the RP2040.)

However, it is interesting to know which CPU the system is running on.
The "JAM Core" is the one with the most features, but does use
opcodes and features that are not available or buggy on an (old) NMOS
6502. This means that a 65C02 or any other CMOS variant is required.
So, it should be a good idea to detect the NMOS 6502 and print an error
message that the system won't work, when running on an NMOS 6502,
instead of randomly crashing. (It even drops you to WozMon after
acknowledging the error message, so that some very basic things can be
done.)

Also, there is another point where a CPU detection is very handy. If you
search for cheap 65C02 processors, you typically find offerings on ebay
or AliExpress for WDC W65C02S processors. However, none of those are
original ones, but all of those are pulled out of machines, and then get
relabeled. (At least the ones I've seen so far.) For this project using
those would not be that bad, if they would not throw in NMOS 6502s in the
mix as well. Those, as explained above, don't fit the requirements.

Finally, there is also another reason to try this: for the challenge.
After all, this is something where there isn't a solution available on
the internet in several variants.

And the solution presented here is also not one without side effects, as
it relys on special features of the runtime environment. This exact code
would only work partially on an Apple II series machine for example.

Partial Detection
-----------------

A very easy way to tell apart an NMOS 6502 CPU from it's CMOS
successors it done like this in the Sorbus JAM kernel.

```
;  65C02       ; NMOS 6502
   LDA   #$00  ; LDA   #$00
   DEC         ; .byte $3a  ; "illegal" NOP
   BNE   CMOS  ; BNE   CMOS ; NMOS will not take the branch
```

In the above case `DEC` will be assembled to $3A which is an undocumented
(also called "illegal") `NOP` opcode. So, while the `LDA #$00` sets the
zero-flag, it will be cleared by the `DEC` opcode, but not by the "illegal"
`NOP` opcode. This also works the same with the `INC` ($1A) Opcode as well.
So, this is a short and efficiant way to tell NMOS and CMOS variants apart,
as all CMOS variants share the same INC/DEC instructions. This is the
detection the "JAM Core" kernel uses for locking out the NMOS 6502.

On the internet, I found a solution on how to detect the three major CPUs:
NMOS 6502, CMOS 65C02 and the 65816, the variant with 16 bit extensions.
This was most probably used to tell apart an Apple IIgs (using a 65816)
from an Apple IIc/IIe enhanced (using a 65C02) and the original Apple
II/II+/IIe (using an NMOS 6502).

```
;  65816       ; 65C02            ; 6502
   LDA   #$01  ; LDA   #$01       ; LDA   #$01
   XBA         ; .byte $EB ; NOP  ; .byte $EB, $EA ; "illegal" SBC #$EA
   NOP         ; NOP              ;
   LDA   #$EA  ; LDA   #$EA       ; LDA   #$EA
   XBA         ; .byte $EB ; NOP  ; .byte $EB, $EA ; "illegal" SBC #$EA
   NOP         ; NOP              ;
;  A=$01       ; A=$EA            ; A=$00

;  ALL
   BEQ   is6502   ; needs to be first
   BPL   is65816
   BMI   is65c02  ; is obsolete if 65c02 specific code continues here
```

As you can see, just detecting three CPUs make things significantly more
complex. Still, this routine is also quite clever with utilizing the CPU
flags for easy branching to the CPU specific routines.

However, the opcode $EB on a 65CE02 is totally incompatible as it is
a read-modify-write opcode that even operates on two bytes (`ROW`).
This renders this routine useless when a 65CE02 is encountered.

Now there are two ways. Either to check for the 65CE02 in advance or
start from scratch.

The Goal
--------

The goal is to could tell 6502 variants apart by their instruction
sets. There are five different instruction sets have been seen in chips
with a pin layout similar to the original NMOS 6502 and the CMOS 65C02:

- NMOS 6502 (Rev.D)
  - however, there is the NMOS 6502 Rev.A, the first 6502 that was still
    missing the ROR opcodes
- 65C02, the base CMOS variant, as compared to the NMOS version,
  a couple of bugs were fixed, and new instructions were introduced
- 65SC02, a 65C02 with the bit-related opcodes removed ($x7 and $xF are
  just 1 byte, 1 cycle NOPs), STP and WAI are missing as well
- 65816, a 16 bit capable variant of the 65SC02, with all 256 opcodes
  defined now
- 65CE02, a CMOS reimplementation of the 65C02 by Commodore with also
  256 opcodes defined, but totally different compared to the 65816

The pin layout is not 100% the same on all chips, but still enough to
run all CPUs with the Sorbus Computer, while omitting some of their
features provided by pins on the chip. Variants like the
[HuC6280](https://en.wikipedia.org/wiki/Hudson_Soft_HuC6280) are not part
of conciderations, as those chips have totally different pin layouts.

Side note: the NMOS 6502 has 3510 transistors, the Rev.A should have a
few less. The 65C02 and 65SC02 are told to have around 4000 transistors.
The 65CE02 doubles that amount with about 8000, while the 65816 has
whopping 22000 transistors. (If you can, please provide more exact
numbers and also references.)

The Runtime Environment
-----------------------

To make things easier, a runtime environment was defined with the sole
purpose to detect the CPU. This is the advantage of this software
defined computer: you can use a special environment for detection and
then switch over to a generic one.

The "runtime environment" is - as all other runtime environments like
the previous mentioned MCP and JAM Cores - written in C. It provides
everything up to the memory and clock signal. The running code to detect
the CPU should write an identifier to the last byte of memory. If this
value changes from the default one, the processing will be stopped.

Since the code will be rather simple, the environment provided should
also be rather simple. Except from the "return value" no I/O is
required. Memory used can also be kept very low: 32 bytes have been
proven to be enough, if the memory is "wrapped around" by not fully
decoding the address. The code size is just 30 bytes, but the amount of
memory provided needs to be a power of 2, as implementing this
differently does not make sense.

The "result-byte" written to the end of memory will then be evaluated.
If it is in the defined range, the processor type id will be returned
by the runtime environment, otherwise a zero indicates a failure.

The "runtime environment" also comes with another feature. Since it's
well encapsulated, it can be used just as a subroutine in differenct
cores. As of now, it is used within the MCP and the JAM Core.

Every Byte Is Sacred
--------------------

One of the fun things about coding for a 6502 processor is trying to
reach a maximum of efficiency. This typically means: either to use a
minimum amount of CPU clock cycles or a minimum amount of bytes of code.
This code focuses on the latter.

The basic idea for supplying the return code is a slide of `INX`
opcodes, which then writes the result to the exit code address ($FF).
But for this to work, X has to be initialized to $00.

So the code would pratically look something like this:
```
   LDX   #$00 ; clear out X
   ; run test code
   ; [...]
   ; more return codes before those three
is65816:      ; exit for 16 bit 65816 (3)
   INX
is65C02:      ; exit for CMOS 65C02 (2)
   INX
is6502:       ; exit for NMOS 6502 (1)
   INX
   STX   $FF  ; stops runtime environment
```
This way, if a specific CPU was detected, jumping to the matching
label will then return the proper code.

The last six bytes in memory are vectors for NMI, reset and IRQ (in this
order). However, as we are not using neither the NMI nor the IRQ, those
memory addresses can be used for code as well. So our code starts at
the IRQ vector, and then wraps around as described above to address
$0020.

The Detection Routine
---------------------

Because reading the [sourcecode](../src/65c02/cpudetect.s) is very
hard, as you can't write code for different variants at the same time,
let's use a simple flow chart on how the detection is implemented.
Red bubbles show a successful detection of a CPU variant.

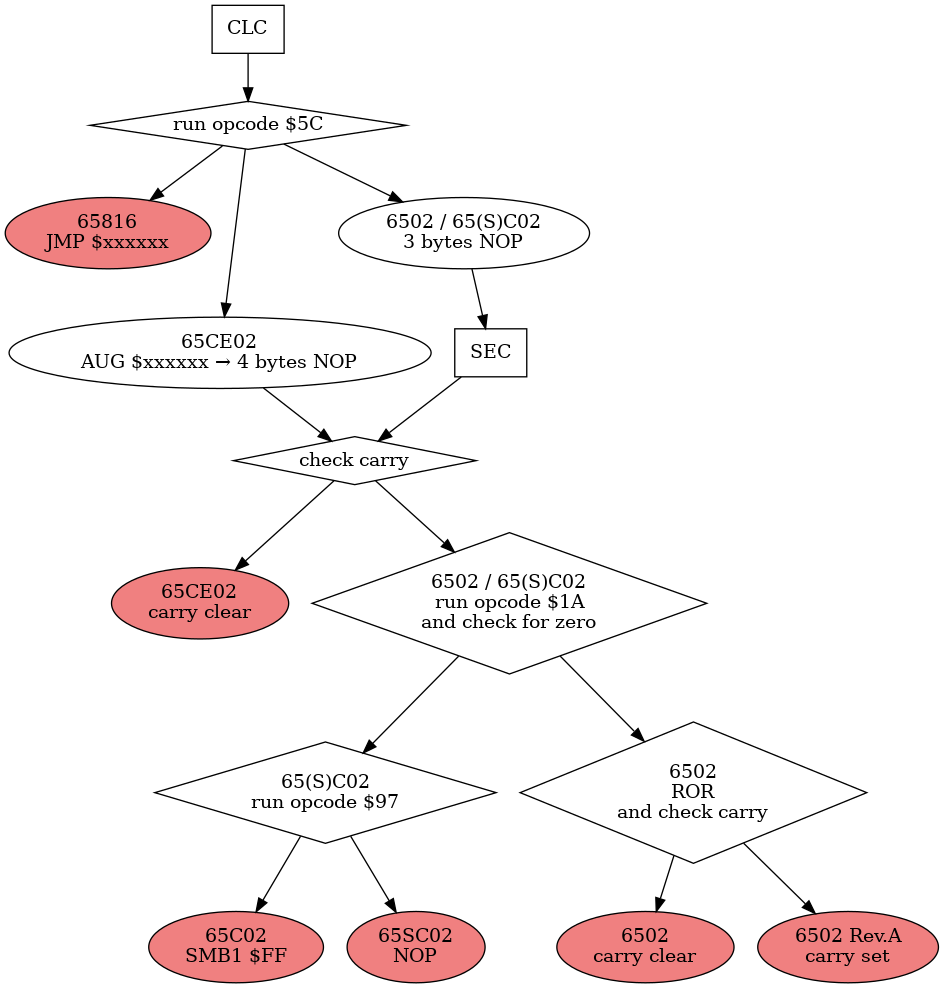
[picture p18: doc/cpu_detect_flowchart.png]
flowchart


Detection Routine As Processed By The Different CPUs
====================================================

Now, we can also take a look at the traces collected from running all
those CPUs.

Hexdump
-------

This is the initial memory configuration when starting the detection
environment.
```
0000: 18 5c 15 00 38 90 0d 8a 1a d0 05 6a b0 05 90 07  .\..8......j....
0010: 97 ff e8 e8 e8 e8 e8 e8 86 ff ea 4c 1e 00 a2 00  ...........L....
```

Let's start by taking a look at the last six bytes, the vectors described
above. The reset vector points to the last two bytes of memory ($001E),
which holds the first instruction. The two bytes before the NMI vector
($0018) hold the `STX $FF` instruction that will stop the runtime
environment.  Even though the bytes for the NMI vector ($001a) shouldn't
be processed, they contain same sane data, a NOP opcode and the opcode for
JMP, this way using the reset vector as an address, this way restarting
the code. This ensures that when something does go wrong, the system does
not drift into undefined behaviour.

Before we dive into the disassemblies, first let's explain the format
using the first executed instruction as our example.
```
 10:001e r a2    :LDX  #$00
```
The `10` is just a line number that starts when the interrupt register
is pulled high, so the CPU leaves reset state.

This is followed by an overview of the bus state at that time. `001e` is
the address bus, `r` shows that the CPU is reading, and `a2` is the data
bus, showing what was read (or written). If lines like Reset, NMI or IRQ
are triggered by pulling to GND, that would be also shown by a
corresponding letter.

`LDX  #$00` is the disassembly of the instruction starting at this
memory address. (In this case "LoaD the X register with the value of
$00".) A dot behind the opcode (like: `NOP.`) indicates that the opcode
is a reserved (CMOS) or undocumented (NMOS) one.

Every trace should end with a `00ff w XX`, which indicates the writing
of the CPU id at the "end of memory". This also stops the runtime
environment.

The disassemblies were created with the command `cold debug` of the MCP
core. They have been slightly modified for a better readability. (As of
writing this document, the disassembler can't always tell apart if the
byte read is an opcode or a parameter.)

Disassembly as seen on a 6502
-----------------------------
```
  1:8aff r 00    :
  2:0089 r d0    :
  3:d0ff r 00    :
  4:d0ff r 00    :
  5:0100 r 18    :
  6:01ff r 00    :
  7:01fe r a2    :
  8:fffc r 1e    :
  9:fffd r 00    :
 10:001e r a2    :LDX  #$00
 11:001f r 00    :
 12:0020 r 18    :CLC
 13:0021 r 5c    :
 14:0021 r 5c    :NOP. $0015,X
 15:0022 r 15    :
 16:0023 r 00    :
 17:0015 r e8    :
 18:0024 r 38    :SEC
 19:0025 r 90    :
 20:0025 r 90    :BCC  $0034
 21:0026 r 0d    :
 22:0027 r 8a    :TXA
 23:0028 r 1a    :
 24:0028 r 1a    :NOP.
 25:0029 r d0    :
 26:0029 r d0    :BNE  $0030
 27:002a r 05    :
 28:002b r 6a    :ROR
 29:002c r b0    :
 30:002c r b0    :BCS  $0033
 31:002d r 05    :
 32:002e r 90    :BCC  $0037
 33:002f r 07    :
 34:0030 r 97    :
 35:0037 r e8    :INX
 36:0038 r 86    :
 37:0038 r 86    :STX  $FF
 38:0039 r ff    :
 39:00ff w 01    :
```
This is the exact CPU variant used in most machines in the late 1970s
and early 1980s. The $5c used in line 14 to detect the 65816 and 65CE02
is skipped and the `INC`-test in line 24 for any CMOS variant does also
not succeed. The third and final test in line 28 for a working `ROR`
instruction does succeed, though.

Disassembly as seen on a 6502 Rev.A
-----------------------------------

This is just estimated, as such a processor is hard to find for a decent
price.
```
  1:8aff r 00    :
  2:0089 r d0    :
  3:d0ff r 00    :
  4:d0ff r 00    :
  5:0100 r 18    :
  6:01ff r 00    :
  7:01fe r a2    :
  8:fffc r 1e    :
  9:fffd r 00    :
 10:001e r a2    :LDX  #$00
 11:001f r 00    :
 12:0020 r 18    :CLC
 13:0021 r 5c    :
 14:0021 r 5c    :NOP. $0015,X
 15:0022 r 15    :
 16:0023 r 00    :
 17:0015 r e8    :
 18:0024 r 38    :SEC
 19:0025 r 90    :
 20:0025 r 90    :BCC  $0034
 21:0026 r 0d    :
 22:0027 r 8a    :TXA
 23:0028 r 1a    :
 24:0028 r 1a    :NOP.
 25:0029 r d0    :
 26:0029 r d0    :BNE  $0030
 27:002a r 05    :
 28:002b r 6a    :ROR
 29:002c r b0    :
 30:002c r b0    :BCS  $0033
 31:002d r 05    :
 32:002e r 90    :
 33:0033 r e8    :INX
 34:0034 r e8    :
 35:0034 r e8    :INX
 36:0035 r e8    :
 37:0035 r e8    :INX
 38:0036 r e8    :
 39:0036 r e8    :INX
 40:0037 r e8    :
 41:0037 r e8    :INX
 42:0038 r 86    :
 43:0038 r 86    :STX  $FF
 44:0039 r ff    :
 45:00ff w 05    :
```
This is almost the same as before (6502), except that the `ROR`
instruction in line 28 does not modify the carry flag, like it
was supposed to. So this has to be one of those early and rare
6502s with the `ROR`-instruction missing.

For more details on this topic, I recommend watching the video
["The 6502 Rotate Right Myth"](https://youtu.be/Uk_QC1eU0Fg) by
Eric Schlaepfer, who also built the
[MOnSter 6502](https://monster6502.com/).

Disassembly as seen on a 65C02
------------------------------
```
  1:0032 r e8    :
  2:0032 r e8    :
  3:ffff r 00    :
  4:0033 r e8    :
  5:01f7 r e8    :
  6:01f6 r e8    :
  7:01f5 r e8    :
  8:fffc r 1e    :
  9:fffd r 00    :
 10:001e r a2    :LDX  #$00
 11:001f r 00    :
 12:0020 r 18    :CLC
 13:0021 r 5c    :
 14:0021 r 5c    :NOP. #$0015
 15:0022 r 15    :
 16:0023 r 00    :
 17:ff15 r e8    :
 18:ffff r 00    :
 19:ffff r 00    :
 20:ffff r 00    :
 21:ffff r 00    :
 22:0024 r 38    :SEC
 23:0025 r 90    :
 24:0025 r 90    :BCC  $0034
 25:0026 r 0d    :
 26:0027 r 8a    :TXA
 27:0028 r 1a    :
 28:0028 r 1a    :INC
 29:0029 r d0    :
 30:0029 r d0    :BNE  $0030
 31:002a r 05    :
 32:002b r 6a    :
 33:0030 r 97    :SMB1 $FF
 34:0031 r ff    :
 35:00ff r 00    :
 36:00ff r 00    :
 37:00ff w 02    :
```
The way the $5c opcode at line 14 is processed here looks a bit strange.
For a couple of cycles (lines 17-21), the CPU seems to have stopped
working, like when an NMOS 6502 executes a `KIL` (illegal) opcode.
However at some point the CPU just continues working at line 22. So this
behaviour is very different from the way the NMOS 6502 processes this
opcode. The result is the same, though: a three-byte NOP.

But when testing for an implemented `INC` instruction at line 28, it
succeeds this time. Then one of the bit manipulation instructions in line
33, which is not present on the 65SC02, sets the bit 1 of the return
value, at line 37 making this the only time, the `INX`-slide is not used
for the return value.

Disassembly as seen on a 65SC02
-------------------------------
```
  1:0001 r 5c    :
  2:0001 r 5c    :
  3:0001 r 5c    :
  4:0100 w 00    :
  5:01ff w 01    :
  6:01fe w 62    :
  7:fffc r 1e    :
  8:fffd r 00    :
  9:001e r a2    :LDX  #$00
 10:001f r 00    :
 11:0020 r 18    :CLC
 12:0021 r 5c    :
 13:0021 r 5c    :NOP. #$0015
 14:0022 r 15    :
 15:0023 r 00    :
 16:ff15 r e8    :
 17:ffff r 00    :
 18:ffff r 00    :
 19:ffff r 00    :
 20:ffff r 00    :
 21:0024 r 38    :SEC
 22:0025 r 90    :
 23:0025 r 90    :BCC  $0034
 24:0026 r 0d    :
 25:0027 r 8a    :TXA
 26:0028 r 1a    :
 27:0028 r 1a    :INC
 28:0029 r d0    :
 29:0029 r d0    :BNE  $0030
 30:002a r 05    :
 31:002b r 6a    :
 32:0030 r 97    :NOP.
 33:0031 r ff    :NOP.
 34:0032 r e8    :INX
 35:0033 r e8    :
 36:0033 r e8    :INX
 37:0034 r e8    :
 38:0034 r e8    :INX
 39:0035 r e8    :
 40:0035 r e8    :INX
 41:0036 r e8    :
 42:0036 r e8    :INX
 43:0037 r e8    :
 44:0037 r e8    :INX
 45:0038 r 86    :
 46:0038 r 86    :STX  $FF
 47:0039 r ff    :
 48:00ff w 06    :
```
This the same as before (65C02), except that the bit set instruction is
interpreted as a reserved `NOP.` opcode in lines 32. It's the same with
the address of that instruction at line 33. So execution continues with
the `INX`-slide.

Disassembly as seen on a 65816
------------------------------
```
  1:001b r 4c    :
  2:001b r 4c    :
  3:001b r 4c    :
  4:01ee r 90    :
  5:01ed r 05    :
  6:01ec r b0    :
  7:fffc r 1e    :
  8:fffd r 00    :
  9:001e r a2    :LDX  #$00
 10:001f r 00    :
 11:0020 r 18    :CLC
 12:0021 r 5c    :
 13:0021 r 5c    :JMP  $380015
 14:0022 r 15    :
 15:0023 r 00    :
 16:0024 r 38    :
 17:0015 r e8    :INX
 18:0016 r e8    :
 19:0016 r e8    :INX
 20:0017 r e8    :
 21:0017 r e8    :INX
 22:0018 r 86    :
 23:0018 r 86    :STX  $FF
 24:0019 r ff    :
 25:00ff w 03    :
```
This is a straight forward one. The 65816 interprets the $5c opcode in
line 13 as a JMP to a 24 bit address. Since we're wrapping around most
of the address does not matter much, only the least significant byte is
required here.

Disassembly as seen on a 65CE02
-------------------------------
```
  1:01f8 r 86    :
  2:01f8 r 86    :
  3:01f8 r 86    :
  4:01f7 r e8    :
  5:01f6 r e8    :
  6:fffc r 1e    :
  7:fffd r 00    :
  8:001e r a2    :LDX  #$00
  9:001f r 00    :
 10:0020 r 18    :CLC
 11:0021 r 5c    :AUG  $380015
 12:0022 r 15    :
 13:0023 r 00    :
 14:0024 r 38    :
 15:0025 r 90    :BCC  $0034
 16:0026 r 0d    :
 17:0034 r e8    :INX
 18:0035 r e8    :INX
 19:0036 r e8    :INX
 20:0037 r e8    :INX
 21:0038 r 86    :STX  $FF
 22:0039 r ff    :
 23:00ff w 04    :
```
This CPU is very interesting. Notice how the `INX` opcodes in lines
17-20 are all processed within a single clock cycle. No other 6502
variant can do this, they all require two clock cycles.

The rest of the detection is rather plain. The $5c opcode in line 11 is
evaluated as a 4 bytes instruction. The only 4 byte opcode this CPU has.
Only the 65816 also has 4 byte opcodes.

This opcode however, even though it is called `AUG`, behaves like a
4 byte `NOP`. So, in this case the `SEC`, that's evaluated by all other
CPUs (except for the 65816), is skipped, and the `BCC`-branch is taken
by this CPU only. (The 4510 chip uses the $5c opcode, now called `MAP`
and shrunken down to 1 byte, to set up memory mapping. Also note that
branching requires only two clock cycles, not three like with all other
6502 variants.)

The Mysterious Problem
======================

Since the start of a CPU detection within the Sorbus Computer, sometimes
a CPU could not be detected, but when running the test a couple of
times, it then magically worked.

What has happend? Typically when processing the reset, the CPU does some
dummy reads from the stack. However, take a look at lines 4-6 from the
65SC02 disassembly. On some CPUs, these dummy reads are actually dummy
writes. This destroys three subsequent bytes in memory. The start must
be concidered random at start, as the stackpointer is not reset yet. But
after that the stackpointer seems to just stay where it was, moving by
three bytes each reset. So during the retries, the stackpointer gets
moved to a position, where the writes go to a part of memory that was
not used during the test.

Interestingly, this is described as an enhancement to the original NMOS
6502 CPU according to the
[CMD G65SC02 datasheet](https://www.alldatasheet.com/datasheet-pdf/view/57031/CALMIRCO/G65SC02.html).
However, even later CPUs do not have this "feature". It is also not
possible to cleanly "return" from a reset, since the program counter
might not be pointing to an instruction. This is not the case with
interrupts.

How was it fixed? The writes happen in a very early stage, even before
the reset vector is being read to determine where in memory to start
executing code. So, writes are now discared, if they were done before
reading the reset vector. Or one can say: before the reset vector is
read the memory is read-only. Problem solved with an elegant solution.

There Is Always Someone Better
==============================

After finishing the CPU detection from the Sorbus, I found this:
[getspu.s](https://github.com/cc65/cc65/blob/master/libsrc/common/getcpu.s)
of the [cc65](https://cc65.github.io/) compiler suite. It can tell
apart nine different 6502 based CPUs.

While there are more than the six CPUs being detected with the method
described here, it does not make sense to add any of those CPUs to this
routine for a simple reason: they don't fit in a 40 pins socket compatible
with the 65C02. The table has a slightly more detailed description:

| CPU | Description | Supported in Sorbus |
| --- | --- | --- |
| NMOS 6502 | original 6502 | yes |
| 65C02 | "current" 6502 still being sold | yes |
| 65816 | 16-bit variant still being sold | yes |
| 65SC02 | 65C02 without bit manipultion opcodes | yes |
| 65CE02 | Commodore CMOS, used in Amiga A2232 | yes |
| 4510 | 65CE02 based microcontroller with MMU | no, different package |
| 45GS65 | MEGA65, huge expansion of 4510 | no, FPGA |
| HuC6280 | PC Engine, CMOS, adds MMU and sound | no, different package |
| 2a03/2a07 | NES/Famicom, NMOS, adds sound, no BCD | no, different pinout  |

So, there is no other CPU to be detected.

However, getcpu.s does not support the 6502 without the ROR opcode.
As the output of the C compiler relies on this opcode, it does not make
sense to add this detection to a library function. The code will most
probably crash before running this function.

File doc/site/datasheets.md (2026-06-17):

# Datasheets

This an assorted list of links to datasheets. It's just a list of links.
This is intended to grow over time. There also is a script in the `src/tools`
directory that can be used to download these documents (PDFs only).

## 6502 Related Hardware Components

### CPUs / MCUs

* [WDC W65C02S CPU](https://www.westerndesigncenter.com/wdc/documentation/w65c02s.pdf)
* [WDC W65C816S CPU](https://www.westerndesigncenter.com/wdc/documentation/w65c816s.pdf)
* [WDC W65C134S MCU](https://www.westerndesigncenter.com/wdc/documentation/w65c134s.pdf)
* [WDC W65C265S MCU](https://www.westerndesigncenter.com/wdc/documentation/w65c265s.pdf)
* [R6501Q One Chip Microprozessor Rockwell datasheet](http://retro.hansotten.nl/uploads/rockwellforth/R6501Q%20One%20Chip%20Microprozessor%20Rockwell.pdf)
* [R6501 R6511 datasheet 1987](http://retro.hansotten.nl/uploads/rockwellforth/r6501%20R6511datasheet%201987.pdf)
* [R65F11 1987 datasheet](http://retro.hansotten.nl/uploads/rockwellforth/R65F11%201987%20datasheet%20.pdf)
* [MOS 6502 User's Manual](https://archive.org/download/6502um/6502UsersManual.pdf)
* [MOS 6500 Preliminary](http://www.6502.org/documents/datasheets/mos/mos_6500_mpu_preliminary_may_1976.pdf)
* [MOS 65CE02 Preliminary](http://www.6502.org/documents/datasheets/mos/mos_65ce02_mpu.pdf)
* [CSG 4510 of the C65 which uses a 65CE02 core](https://github.com/MEGA65/c65-specifications/blob/master/c65manualupdated.txt)
* [CMD G65SC02](https://www.datasheetcafe.com/wp-content/uploads/pdf/G65SC02.pdf)

### I/O Chips

* [WDC W65C21 PIA](https://www.westerndesigncenter.com/wdc/documentation/w65c21.pdf)
* [WDC W65C22 VIA](https://www.westerndesigncenter.com/wdc/documentation/w65c22.pdf)
* [MOS 6526 CIA](https://archive.org/download/mos_6526_cia_recreated/mos_6526_cia_recreated.pdf)
* [MOS 6530 RRIOT preliminary](http://www.6502.org/documents/datasheets/mos/mos_6530_rriot_preliminary_aug_1975.pdf)
* [MOS 6530 RRIOT](http://www.6502.org/documents/datasheets/mos/mos_6530_rriot.pdf)
* [MOS 6532 RIOT preliminary](http://www.6502.org/documents/datasheets/mos/mos_6532_riot_preliminary_feb_1977.pdf)
* [MOS 6532 RIOT](http://www.6502.org/documents/datasheets/mos/mos_6532_riot.pdf)
* [Rockwell R6532 RIOT](https://z3d9b7u8.stackpathcdn.com/pdf-down/R/6/5/R6532_Rockwell.pdf)
* [MOS 6530-004 RRIOT TIM](http://retro.hansotten.nl/uploads/6502files/mostim1976.pdf)
* [Rockwell R6551 ACIA](https://z3d9b7u8.stackpathcdn.com/pdf-down/R/6/5/R6551_Rockwell.pdf)
* [Rockwell R65C51 ACIA](https://z3d9b7u8.stackpathcdn.com/pdf-down/R/6/5/R65C51_ETC.pdf)
* [WDC W65C51N ACIA](https://www.westerndesigncenter.com/wdc/documentation/w65c51n.pdf)

### Machines / SBCs

* [Mensch Microcomputer](http://www.westerndesigncenter.com/wdc/documentation/W65C265QBX.pdf)
* [TIM MOS folder](http://retro.hansotten.nl/uploads/6502files/tim%20mos%20folder.pdf)
* [WDC W65C02SXB](http://www.westerndesigncenter.com/wdc/documentation/W65C02SXB.pdf)
* [WDC W65C816SXB](http://www.westerndesigncenter.com/wdc/documentation/W65C816SXB.pdf)
* [WDC W65C134SXB](http://www.westerndesigncenter.com/wdc/documentation/W65C134SXB.pdf)
* [WDC W65C265SXB](http://www.westerndesigncenter.com/wdc/documentation/W65C265SXB.pdf)
* [WDC W65C265QBX](http://www.westerndesigncenter.com/wdc/documentation/W65C265QBX.pdf)

## Glue Logic

* [Atmel ATF22V10](http://www.atmel.com/Images/doc0735.pdf)

## Firmware

* [W65C134 Monitor ROM Reference Manual](https://www.westerndesigncenter.com/wdc/documentation/134monrom.pdf)
* [W65C134 Monitor ROM Code Listing](https://www.westerndesigncenter.com/wdc/documentation/134iromlist.pdf)
* [W65C265 Monitor ROM Reference Manual](https://www.westerndesigncenter.com/wdc/documentation/265monrom.pdf)
* [W65C265 Monitor ROM Code Listing](https://www.westerndesigncenter.com/wdc/documentation/265iromlist.pdf)
* [OSI 8K BASIC Manual](https://osiweb.org/manuals/OSI_8K_Basic_in_ROM.pdf)
* [Book on OSI BASIC](https://osiweb.org/books/OSI_Basic_In_Rom.PDF)
* [Apple Disassembler in Dr Dobb's Journal](http://6502.org/documents/publications/dr_dobbs_journal/selected_articles/6502_disassembler_from_apple.pdf)
* [SWEET16: Byte Magazine Volume 02 Number 11 (1977)](https://archive.org/download/BYTE_Vol_02-11_1977-11_Sweet_16/BYTE_Vol_02-11_1977-11_Sweet_16.pdf)

## Host Based Hardware

* [C/C++ SDK](https://datasheets.raspberrypi.com/pico/raspberry-pi-pico-c-sdk.pdf)
* [Hardware design with RP2040](https://datasheets.raspberrypi.com/rp2040/hardware-design-with-rp2040.pdf)
* [Hardware design with RP2350](https://datasheets.raspberrypi.com/rp2350/hardware-design-with-rp2350.pdf)
* [PGA2350 pinout](https://cdn.shopify.com/s/files/1/0174/1800/files/pga2350_pinout_diagram.png)
* [Raspberry Pi RP2040 MCU](https://datasheets.raspberrypi.com/rp2040/rp2040-datasheet.pdf)
* [Raspberry Pi RP2350 MCU](https://datasheets.raspberrypi.com/rp2350/rp2350-datasheet.pdf)

## Documentation Of Old Hardware And Software

* [Apple 1 Basic](https://archive.org/download/apple1_basic_manual/apple1_basic_manual_text.pdf)
* [Apple 1 KRUSADER](https://raw.githubusercontent.com/st3fan/krusader/master/krusader13.pdf)
* [CF/IDE Interface on 8-Bit](https://www.waveguide.se/?article=8-bit-compact-flash-interface)
* [OSI 6502 8K BASIC Ver 1.0 Users Manual](https://archive.org/download/osi-6502-8-k-basic-ver-1.0-users-manual/OSI%206502%208K%20BASIC%20Ver%201.0%20Users%20Manual.pdf)
* [OSI 6502 8K BASIC Ver 1.0 Users Manual (Text Only)](https://archive.org/download/osi-6502-8-k-basic-ver-1.0-users-manual/OSI%206502%208K%20BASIC%20Ver%201.0%20Users%20Manual_text.pdf)

## Terminal Related Stuff

* [VonaUtils VT100](https://www2.ccs.neu.edu/research/gpc/VonaUtils/vona/terminal/vtansi.htm)
* [VT100-Examples](https://github.com/0x5c/VT100-Examples/raw/master/vt_seq.md)
* [ANSI Escape Sequences](https://gist.github.com/ConnerWill/d4b6c776b509add763e17f9f113fd25b)
* [German manual of MCURSES](https://www.mikrocontroller.net/articles/MCURSES)
* [Arduino implementation of MCURSES](https://github.com/ChrisMicro/mcurses)
* [Unicode Range 0000–007F: C0 Controls and Basic Latin](https://www.unicode.org/charts/PDF/U0000.pdf)
* [Unicode Range 0080–00FF: C1 Controls and Latin-1 Supplement](https://www.unicode.org/charts/PDF/U0080.pdf)
* [Unicode Range 0100–017F: Latin Extended-A](https://www.unicode.org/charts/PDF/U0100.pdf)
* [Unicode Range 0180–024F: Latin Extended-B](https://www.unicode.org/charts/PDF/U0180.pdf)
* [Unicode Range 2070–209F: Superscripts and Subscripts](https://www.unicode.org/charts/PDF/U2070.pdf)
* [Unicode Range 2100–214F: Letterlike Symbols](https://www.unicode.org/charts/PDF/U2100.pdf)
* [Unicode Range 2190–21FF: Arrows](https://www.unicode.org/charts/PDF/U2190.pdf)
* [Unicode Range 2500–257F: Box Drawing](https://www.unicode.org/charts/PDF/U2500.pdf)
* [Unicode Range 2580–259F: Block Elements](https://www.unicode.org/charts/PDF/U2580.pdf)
* [Unicode Range 25A0–25FF: Geometric Shapes](https://www.unicode.org/charts/PDF/U25A0.pdf)
* [Unicode Range 2600–26FF: Miscellaneous Symbols](https://www.unicode.org/charts/PDF/U2600.pdf)
* [Unicode Range 1FB00–1FBFF: Symbols for Legacy Computing](https://www.unicode.org/charts/PDF/U1FB00.pdf)

## Opcode Tables

* [Oxyron 6502 Opcode Table](https://www.oxyron.de/html/opcodes02.html)
* [Oxyron 65C02/65SC02 Opcode Table](https://www.oxyron.de/html/opcodesc02.html)
* [Oxyron 65CE02 Opcode Table](https://www.oxyron.de/html/opcodesce02.html)
* [Oxyron 65816 Opcode Table](https://www.oxyron.de/html/opcodes816.html)
* [Pastraiser's 65CE02](http://www.pastraiser.com/cpu/65CE02/65CE02_opcodes.html)

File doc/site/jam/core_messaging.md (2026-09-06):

Core Messaging
==============

(TODO before release: clean up here)

The Sorbus Computer with it's JAM core is intended to be an
implementation that a single person can understand with all it's
facettes.

However, the way the two micro controller cores in the RP2040 of the
mainboard communicate with each other has become a little complex. This
is due to a couple of reasons. One is performance: the communication has
to be efficient to provide a 6502 clock speed of more than 1MHz. Another
one is stabiliy of the clock. But to achive these goals, there have been
a couple of changes and rewrites of the code. To allow for an easier
entry into this code, this page was created.

This diagram looks like this:

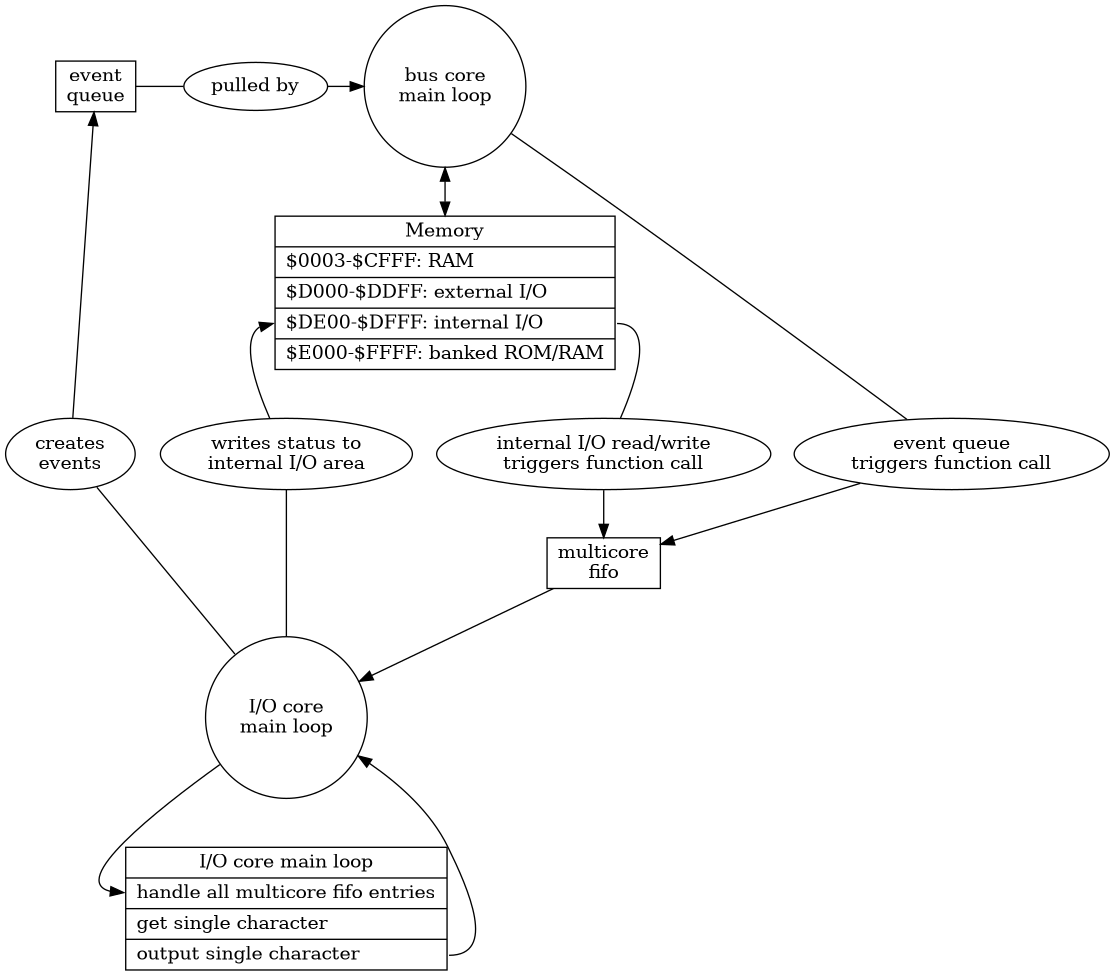
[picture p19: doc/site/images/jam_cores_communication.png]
cores_communication


Now, let's take a look at all the components shown here.

Memory
------

This part is an inside view of the core-to-core communication between the
`bus-core` and `io-core`.

Main source of communication is the memory. The internal I/O area is first
of all treated like normal memory. When it's written to, the data is kept
in the "I/O RAM". But even more, the data read from I/O space is read from
"I/O RAM". This mean that the I/O data needs to be prepared in advance.

Also, when an address is shared in a way that read and write have totally
different functions, then the write handler must ensure that the written
data will be replaced with the one required by the next read.

The Multicore Fifo
------------------

The `bus-core` send messages to the `io-core` on what needs further
attention. The message is packed into an `uint32`. This is unidirectional
and "fire and forget".

The format of the `uint32` is derived from the trace information and
looks like this `0xCCDDAAAA`, where the parts are:

- CC: command, so what to do
- Note: CC is the only significant part, the rest is defined by that
  command, what's noted here is just common practice
- DD: data, the data bus, also just an 8-bit argument
- AAAA: address, the address bus, also just an 16-bit argument

Here's an overview of the command byte:

| Value | Function | Note |
| ----- | --- | --- |
| 0x01  | Reset | handle reset line as well as reset of internal I/O |
| 0x02  | Notify about internal I/O write  | parameter are false, uint8 data, and uint16 address |
| 0x03  | Notify about internal I/O read | parameter are true and uint16 address |
| 0x04  | Meta | leave regular execution, stop system, enter meta mode |
| 0x05  | CPU frequency tester | every 1M clock cycles, the time spent is measured |
| 0x06  | Timer | used by cycle based timers |
| 0x07  | Flash | flush the dhara flash layer |

Others are undefined. Also the range supported internally only is 0x00-0x0F.

The I/O functions (0x02 and 0x03) are handled slightly differently.

### Message 0x02: Notify about internal I/O write

- DD: data bus of 6502
- AAAA: address bus of 6502
- also note that the lowest bit of the command matches the r/!w line
  (this is intended by design)

### Message 0x03: Notify about internal I/O read

- DD: data bus of 6502
- AAAA: address bus of 6502
- also note that the lowest bit of the command matches the r/!w line
  (this is intended by design)

User Input
----------

Things would be so much easier without the user input. However, the
`io-core` besides checking for messages from the multicore fifo also
needs to check for user input via and output by the program do be sent
over the USB UART.

The I/O core does each of these things in a loop: check for a fifo
message, check for user input and check for output. If an action is
required for one of these tasks.

For storing the data for input and output the queues from the Pico SDK
are used. No need to reimplement the wheel.

The Event Queue
---------------

For interrupts and other events that can happen, there is a tick based
event queue inplemented. You can also create an event that will happen
in, for example 20000 cycles, to flush the cache of the wear levelling
flash storage. If another write takes place in between, you can cancel
the previous event and set up a new one.

The way of communication here is that the `io-core` sets up an event,
and then the `bus-core` runs that loop to send the event back to the
`io-core`. The intention here is to have a tight coupling of both cores.

The CPU pins
------------

| Signal | 65C02 | bus-core | io-core |
| --- | ----- | --- | --- |
| A0-A15 | o | i | |
| D0-D7  | x | x | |
| R/!W | o | i | |
| CLK | i | o | |
| RDY | i | i | o |
| IRQ | i | | o |
| NMI | i | | o |
| RESET  | i | i | x |

- x: used for input and output
- i: input only
- o: output only

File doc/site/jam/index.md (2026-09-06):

# Sorbus JAM

The Sorbus JAM (short for Just Another Machine) is an implementation of a
complete system that does not resemble any already created computer. It
is intended to grow into a well defined platform capable of running
demos. (See
[Wikipedia's entry on the Demoscene](https://en.wikipedia.org/wiki/Demoscene).)

The flash of the RP2040 contains the Kernel ROM and the flash filesystem
image in RAW flash. Those can (and have to) be loaded independently from
the core in flash, using the following commands:

-  picotool load -o 0x103FA000 -t bin <kernel>
-  picotool load -o 0x10400000 -t bin <filesystem>

(This is a subject to change, because it's now possible to create a UF2
file with everything firmware, but this seems not to be fully supported.)

NOTE: This documentation describes the current state of development, which
currently takes place in development the branch `bios_65816_native`. It
will be merged when it is capable to run
[1k LEDs Is No Limit (2025)](https://xayax.net/1k_leds_is_no_limit/)
without any graphic glitches.

---

## Supported CPU Variants

While the hardware supports all pin compatible 6502 CPUs, the Sorbus JAM
has some limitations. Here there are in detail:

### 65C02 and 65SC02

These CPUs are the focus when something is implemented for the Sorbus JAM.
So everything should work as expected.

### 65CE02

This CPU, which was only available on the Amiga A2232 serial port card, is
fully supported, as long as the extra Z register is not used, and left to
the default value of $00.

Code modifing the Z register needs to store this, and clear it before using
the BRK interrupts to jump into the kernel. And of course restore it
afterwards.

This can be accompished using the `int` macro provided in
`src/65c02/jam/jam_bios.inc`, when the CPU is set to "4510", which is
a superset of the 65CE02. The only difference is that the 65CE02 lacks
the `MAP` opcode.

Also, the kernel is implemented under the assumption that the stack is
located at $0100-$01ff. So, when moving the stack using TYS and/or using
the CLE opcode for a 16-bit stack, make sure that the stack will be in
the area of $0100-$01ff when calling the kernel.

### 65816

Starting with kernel 0.7, this CPU is supported by the Sorbus JAM in both
legacy and native mode. Before kernel 0.7, only legacy mode was supported.
However, all vectors that are not available on a 6502 are set to a stub
implementation, just triggering [meta mode](meta_mode.md) before resetting.

These can be overloaded when switching bank $00 (RAM). Copying BIOS to RAM
before making these modification using interrupt $0B (COPYBIOS) is advised.
This works as the bank is only reset to kernel when a hardware reset (e.g.
from meta menu) is triggered. Note that for calling kernel routines via
JSR, the M and X flags need to be set to 8-bit mode. However, calling
kernel routines provided via BRK _should_ work, but has not been tested
very much. It will not work, if stack pointer is not pointing to page $01.

Also keep in mind that the support only has been expanded for the kernel
driving the 65C02/65816. The development the backtrace in meta mode only
has started with 0.7 and is expected to mature during the incremential
commits following.

Support can never be fully implemented, as some important pins of the
65816 are not connected to the RP2040 (e.g. VDA, VPA, VPB, E, MX and
ABORTB). Also, the muxing of the D0-D7 pins used for A16-A23 during the
"high" phase of the clockcycle are not intended to be implemented, so
addressing will be always mapped to the base 64k space.

Also, the kernel is implemented under the assumption that the stack is
located at $0100-$01ff. So, when switching to native mode make sure that
the stack will be in the area of $0100-$01ff when calling the kernel.

Furthermore, the backtrace for 65816 cannot read the MX signals from the
CPU. So, a heuristic has been implemented to trace the M, X, and E flags
from the sampled data. This might not work all of the time.

### NMOS 6502

This CPU is not supported by the Sorbus JAM. However, if such a CPU is
detected a message is printed out. After that, the only thing available
will be the [NMOS 6502 Toolkit](#nmos-6502-toolkit). See chapter
"[Using an NMOS 6502](#using-an-nmos-6502)" below.

---

## Available Boot Options

When you connect to the Sorbus Computer via USB UART, you typicall see
nothing, because the output of the reset message was faster than your
connect. Press space (or any other unused key) to get the message again.
It looks something like this:

```txt
Sorbus JAM V0.6: 1-4)Bootsector, 0)Exec RAM @ $E000,
F)ilebrowser, B)ASIC, System M)onitor, T)IM, W)ozMon?
```

### System Monitor

This is a native implementation of a monitor as known from the Commodore
machines. It has got its own documentation file [sysmon.md](sysmon.md).

### WozMon & TIM (MOS 6530-004)

Those are ports of the original software which for example make use of
the additional opcodes of the 65C02. Those are described more in detail
in [monitors.md](monitors.md).

### OSI BASIC V1.0 REV 3.2

This is a port of the Microsoft BASIC 1.0 as used on the [Ohio Scientific Model
600](https://www.oldcomputers.net/osi-600.html).
It has been heavily modified. For details see also [ms_basic.md](ms_basic.md).

### Filebrowser

This is a simple file loader. It loads files with the extension “.SX4”
and others (see "Executable Formats" below) from the user-partition 10
or others.

### CP/M 65

This can be loaded from bootblock 1. It is a reimplementation of the
original 8080 operating system for the 6502.

There are still three other bootblocks available for other use.
Bootblocks are always 8k in size, they will be loaded at $E000 at the
RAM bank 0 “under” the kernel area. The first three bytes should include
a JMP instruction followed by the sequence of the ASCII characters
"SBC23" (without the quotes). Upon startup, a routine will be installed
at $0100, that copies the last page of memory ($FF00-$FFFF) from kernel
to RAM. This will enable the loaded code to utilize the software
interrupt handler and other features of the kernel. This part is called
the BIOS.

The second bootblock will be loaded when an NMOS 6502 is detected.

### NMOS 6502 Toolkit

This is a stripped down version of the System Monitor and will be loaded
from bootblock 2. It is also loaded when an NMOS 6502 CPU is detected
during startup (see next section).

---

## Using an NMOS 6502

The kernel of this core does not support an NMOS 6502, and shows an
appropriate message upon startup. Then the kernel attempts to load
bootblock 2 (see above). If this fails it drops into WozMon. Both can be
used for some rudimentary work. However, the NMOS 6502 Toolkit should be
preferred, as it is way more capable than WozMon.

The NMOS 6502 toolkit is implemented without the `ROR` instruction, so it
will also run on a Rev.A variant of the 6502, making this on of the most
versatile systems to use with an NMOS 6502 Rev.A.

---

## CP/M 65 Usage

Upon startup, ``CCP.SYS``, the command interpreter, is loaded. It knows
the built-in commands ``DIR``, ``ERA``, ``REN``, ``TYPE``, ``USER`` and
``FREE``.

[Repository of CP/M 65](https://github.com/davidgiven/cpm65)

---

## OSI BASIC V1.0 REV 3.2 Usage

This port has some significant changes compared to the original OSI
BASIC.

- The zeropage starts at $10, not $00, so everything is moved there.
- USR() jumpcode is still at $0a
- NULL command removed, token replaced with SYS that behaves similar
  to Commodore BASIC
- $0d (13), $0e (14), $0f (15) are used as A,X,Y when calling SYS
- As the full code has been disassembled, modified and reassembled,
  all addresses of the ROM functions are not correct.
- The monitor has been replaced with routines for LOAD, SAVE, DIR and
  the BIOS. LOAD and SAVE take a filename for a parameter. “.BAS” is
  appended automatically. Those files utilize the user-partition 11.
  SAVE erases a previous file with the same name before writing.
- BASIC starts at $0400, as the area $0200-$03ff is used by the Sorbus
  kernel for accessing the internal drive. ($0200-$02ff is only used
  for saving, and also "swapped out", so data is restored after SAVE.)
- The LOAD and SAVE work totally different as stated in the manuals.
- LOAD"$" is added to display the directory on screen.
- No need to enter size of memory size (compiled in)
- terminal width and auto-newline has totally been removed and should
  be now handled by the terminal software used
- Token order is kept the same, so most original OSI BASIC code should
  work on the Sorbus variant as well
- code for RND(0) has been changed, so sequence will not be the same,
  actually being random

---

## Executeable Formats

Executeable file formats can be loaded using the file browser and are
only distinguished by their extension. The filebrowser does whatever is
required to set up the system to run those files.

### SX4

SX4 stands for Sorbus eXecutable at $0400, so it's just a binary blob
loaded to $0400 at memory and started at the load address, after the
bank has been switched to $00 (RAM at $E000) with the BIOS copied to RAM.
This is done by the File Browser. When an SX4 is loaded otherwise, e.g.
via UART the bank configuration will be left untouched.

### SX6

SX6 stands for Sorbus eXecutable at $0600, however it differs significantly
from SX4. SX6 is a file format intended to be running executeables
written for the runtime environment of 6502asm.com a now defunct online
"fantasy system", It was an assembler combined with a runtime environment
to run executeable at $0600 with a 32x32 pixels framebuffer located at
$0200, using a C64 color map.

This implementation is using the IRQ to update the framebuffer to the
FB32X32 hardware expansion. The IRQ and NMI were never implemented in
6502asm.com, so this is fitting. However there are some changes.

Compatibility issues:

-  no other start address than $0600 can be used
-  the framebuffer is updated with constant 20 frame per second
-  $FE (random number generator) is updated only once per IRQ. If more
   random numbers per frame are required, $FF needs to be changed to
   $DF02
-  $FF (key press) is also updated only once per IRQ, use of JSR $FF00
   for getting a key instead is suggested
-  RAM at $00-$03 cannot be used, since the Sorbus has this reserved
   for I/O
-  RAM at $04-$07 should not be used as it is reserved for kernel
   functions. However when no kernel functions are used, this can be
   used.
-  RAM can be only used up to $CFFF, as $D000-$FFFF contain I/O and ROM.
-  $FC/$FD contain a 16 bit frame counter, this is actually an
   improvement
-  SEI/CLI are now implemented, turn off/on screen updates
-  all other I/O registers from the Sorbus JAM are available

The frame counter can be utilized to calculate effects according to their
frame number. Also syncing with the next frame can be implemented rather
easy:

```asm6502
   lda   $fc
loop:
   cmp   $fc
   beq   loop
```

So, this is intended with the balance of rather easy porting existing
6502asm.com software as well having some nice features to write new short
demos for the Sorbus JAM.

---

## Notes On Implementation in RP2040

### Multicore Architecture

Core 0 runs the console and handles user interaction. Core 1 drives the
bus for the CPU implementing the system. To have a rather efficient
(fast as in ~1MHz) system, core 1 really has to come up with some
tricks. So, every “event” aspect, such as timers, watchdog and other
things will be run by an event queue. This means on every clock cycle
there is a check if something was scheduled for this specific clock
cycle. Again due to performance, only one event will happen during that
clock cycle. If two events are scheduled for the same clock cycle, the
second one scheduled will be delay by one clock cycle (and again until
there is a free slot). The size of the queue is 32 event. This should be
sufficiant, as there are not much things that could add to the event
queue, and in most cases, a new event from the same source replaces the
old one.

However: again due to performance the queue is not thread safe! So only
the core handling the bus is allowed to interact with it.

The core handling the console on the other hand is allowed to do two
things on the hardware side:

-  pull the RDY line low (to stop the CPU) and back high (to let the CPU
   continue)
-  pull the RESET line to low (but not back to high again), this may be
   only done if the RDY line is high, or immediately pulled high after
   the reset line was pulled low (immediately = in the next code line!)

If core running the bus should want to use the RDY line for some reason,
this should be implemented using “queue_uart_write” with characters > 0xFF.
For performance/latency reasons it also does pull RDY low itself as well.

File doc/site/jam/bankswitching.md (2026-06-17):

# Bankswitching

The sorbus computer only provides a ROM area of $E000-$FFFF, so
bankswitching is required to provide more than 8kB. OSI BASIC alone
requires >7.5kB. So bankswitching is required to access more than just
the 8kB of ROM banked into memory.

The bankswitching is implemented in the same fashion as on the first
bankswitching cartridges for the Atari 2600 VCS: the whole memory block
is switched (on the Sorbus by writing a value to a specific register,
see below).

## The BIOS Region

The last page of memory ($FF00-$FFFF) has a special function: this is
identical in every bank (or at least similar in specific cases like the
NMOS 6502 monitor). There also is a function (BRK based) provided to
copy the data from ROM to RAM, so kernel functionality can be executed
even from RAM.

## Bankswitching Register

Bankswitching is implemented using a simple register @ $DF00, with the
following values:

- $00: switch area to RAM (required for CP/M, helpful for other things)
- $01: main kernel bank with BRK handler, etc.
- every valid bank >$02: helper function, BASIC, etc.
- invalid banks will switch to bank $01

## Overview

| Method | From Bank | To Bank | Note |
| --- | --- | --- | --- |
| BRK | any + RAM | kernel($01) | RAM only works when BIOS is copied to RAM |
| bankstart | kernel($01) | any | starts payload at $E000, e.g. BASIC |
| bankjsr | kernel($01) | tools($02)  | very transparent design, expandable to other banks |
| bankjmp | any | any | very quirky in usage, cannot be used for $E000 |
| bootblock | kernel($01) | RAM | used for CP/M and other bootblocks |

So, every method has been taylored to a specific usecase. `bankjsr` and
`bankjmp` require a jumptable at the beginning of the destination bank,
because it's not possible to hand labels between kernel banks.

### Bankswitching Variant 1: BRK Software Interrupts

The kernel uses the software interrupt BRK with an operand to trigger
kernel functions. The code that handles that is non-trivial but allows
for more freedom within the development of the kernel, as things can
be moved around with less implications.

Using the function to wait for a keypress and return it converted to
uppercase runs like this:

```asm65c02
   brk   #$01           ; typically written as "int  CHRINUC" in source

   ; read IRQ vector jumping to
   jmp   (UVIRQ)        ; User Vector for IRQ ($DF78) normally to IRQCHECK

IRQCHECK:
   sta   BRK_SA         ; let's figure out the source of the IRQ
   pla                  ; get processor status from stack
   pha                  ; and put it back
   and   #$10           ; check for BRK bit
   bne   _isbrk
   lda   BRK_SA         ; restore saved accumulator
   jmp   (UVNBI)        ; user vector for non-BRK IRQ ($DF7C)
_isbrk:
   lda   BANK           ; get current bank
   sta   BRK_SB         ; save it
   stx   BRK_SX
   sty   BRK_SY
   tsx
   lda   $0103,x        ; offset of current stack pointer is 1+2
   sta   TMP16+1        ; at offset 0 is processor status (got called via BRK)
   lda   $0102,x        ; get the return address from stack
   sta   TMP16+0        ; and write it to temp vector

   bne   :+
   dec   TMP16+1
:
   dec   TMP16+0
   lda   (TMP16)        ; finally get BRK operand!
                        ; needs to be read without bank change
   sta   ASAVE          ; misuse asave to store BRK operand for user handler
   ldx   #$01           ; will be restored by brkjump
   stx   BANK           ; switch to first ROM bank
   jsr   brkjump        ; to call the subroutine selector

brkjump:
   cmp   #jumptablesize
   bcc   @okay          ; sanity check: if BRK operand out of scope
   lda   #$00           ; reset, user BRK can lda (TMP16) to get BRK operand
@okay:
   asl                  ; BRK >=$80 will always be =$00
   tax
   lda   @jumptable+1,x ; get address from jump table
   pha
   lda   @jumptable+0,x
   pha
   tsx
   lda   $0105,x        ; get processor state from stack
   pha                  ; and save it for rti below
   ldx   BRK_SX         ; get stored X
   lda   BRK_SA         ; get stored A
   rti                  ; jump to handling subroutine

   ; here's the routine to be called
chrinuc:
   ; wait for character from UART and make it uppercase
   jsr   CHRIN
   bcs   chrinuc
   jsr   uppercase
   sta   BRK_SA         ; when called via BRK, this is required
   rts

   ; now return from brkjump
   php
   ldy   BRK_SY         ; get stored Y
   pla
   sta   BRK_SY         ; use stored Y now for storing P
   ldx   BRK_SX         ; get stored X
   lda   BRK_SB         ; get stored BANK
   sta   BANK           ; restore saved bank
   pla                  ; drop old P from stack
   lda   BRK_SY         ; get P from store
   pha                  ; put it on the stack, so flags can be returned
   lda   BRK_SA         ; get stored accumulator
   rti                  ; return to calling code
```
As an interrupt is intended to be handled without changing the registers,
this is here the case as well (except for processor status). If an
interrupt want to "return" a value, this has be written specifically
into the memory addresses where those values are stored: BRK_SA, BRK_SX
and BRK_SY.

This also shows that BRKs cannot be nested. However they are used in
other banks than the kernel to call functions within the kernel bank.
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

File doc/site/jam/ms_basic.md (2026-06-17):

# Microsoft OSI BASIC 1.0 Rev 3.2

The BASIC provided is based upon Microsoft BASIC for the [OSI Computer
Ohio Scientific, Inc.](https://www.oldcomputers.net/osi-600.html).

The source code is based upon the single file version created by
[Grant Searle in 2013](https://land-boards.com/blwiki/index.php?title=SIMPLE-6502),
which in itself is based by the [source code reverse engineered by Michael
Steil](https://github.com/mist64/msbasic).

The original configuration is like this:

| Name | Release | MS Version  | ROM | 9digit | INPUTBUFFER | extensions | .define |
| --- | --- | --- | --- | --- | --- | --- | --- |
| OSI BASIC | 1977 | 1.0 REV 3.2 |  Y  | N | ZP | - | CONFIG_10A |

Also, the original source code of the slightly newer version 1.1 has been
officially released by [Microsoft on GitHub](https://github.com/microsoft/BASIC-M6502).
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

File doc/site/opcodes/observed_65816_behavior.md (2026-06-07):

# Observed 65816 Behavior

The 65816 can run in five different modes:

- Emulation
- Native: M=1, X=1
- Native: M=0, X=1
- Native: M=1, X=0
- Native: M=0, X=0

This can be a cause for a lot of cases of slightly different behavior.

Following are some random things that were observed.
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

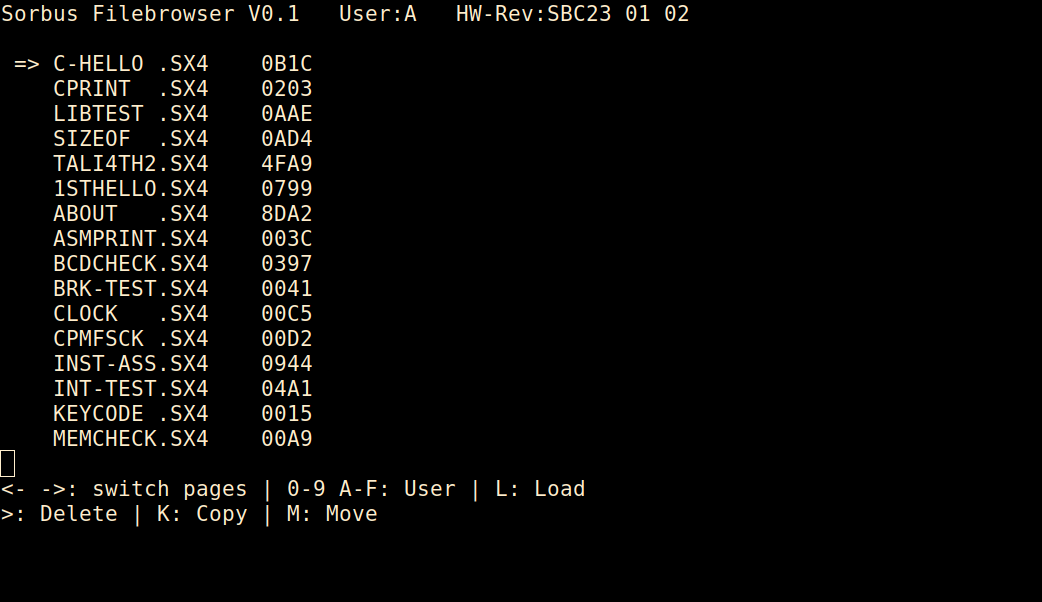
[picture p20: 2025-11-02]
doc/site/images/Filebrowser.png

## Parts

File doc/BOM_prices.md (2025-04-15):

BOM & Prices
============

At one point the prices when buying supplies got written down, indended to be
updated when buying the next batch.

All prices are in Euros.

A Note About Getting 65C02s
---------------------------

When the project was started in mid 2023, 65C02 or 65SC02 were easy to obtain
for ~2,50 Euro per chip when buying 10. However since end of 2024 these chips
are getting harder to get. The official price at Mouser is ~8.30/chip when
buying 10 or more. So, if prices of refurbished and new old stock rise even
more, it makes more sense to buy new chips.
[(WDC W65C02TPG-14 @ Mouser)](https://eu.mouser.com/ProductDetail/Western-Design-Center-WDC/W65C02S6TPG-14?qs=opBjA1TV903lvWo9AEKH5w%3D%3D)

Sorbus Junior
-------------

| Count | Part | Price Per Batch | When Buying | Supplier Used | Comment |
| ----: | --- | ---: | ---: | --- | --- |
| 1 | PCB | 1.00 | 10 | Elecrow | |
| 1 | RP2040 Purple Board 16MB | 2.50 | 10 | AliExpress | |
| 1 | 65C02 or 65SC02 | 2.50 - 10.21 | 10 | eBay, AliExpress | Complicated |
| 4 | 32 pin socket | 1.00 | 50 | eBay | |
| 7 | 3.3k pull up resistors | | | | only 3 required  |
| 1 | capacitor | | | | optional |
| 2 | 5 pin connector | | | | |
| 1 | jumper | | | eBay | |

Sorbus Sound
------------

| Count | Part | Price Per Batch | When Buying | Supplier Used | Comment |
| ----: | --- | ---: | ---: | --- | --- |
| 1 | PCB | 1.00 | 10 | Elecrow | |
| 1 | RP2040 Purple Board 16MB | 2.50 | 10 | AliExpress | |
| 1 | 32 pin connector, angled | | | AliExpress | 40 pin connector |
| 1 | PCM5102 I2S sound module | 2.00 | 10 | AliExpress | |
| 1 | uSD socket | 0.70 | 10 | AliExpress | |
| 8 | diode | | | Mouser | |
| 1 | 3 pin connector | | | | |
| 1 | jumper | | | eBay | |

Sorbus VGA
----------

| Count | Part | Price Per Batch | When Buying | Supplier Used | Comment |
| ----: | --- | ---: | ---: | --- | --- |
| 1 | PCB | 1.00 | 10 | Elecrow | |
| 1 | RP2040 Purple Board 16MB | 2.50 | 10 | AliExpress | |
| 1 | 32 pin connector, angled | 0.25 | 50 | eBay | 40 pin connector |
| 1 | VGA Socket | 1.40 | 10 | eBay | |
| 3 | resistor 499 | | | Mouser | |
| 3 | resistor 1K | | | Mouser | |
| 3 | resistor 2K | | | Mouser | |
| 3 | resistor 4.02K | | | Mouser | |
| 3 | resistor 8.02K | | | Mouser | |
| 2 | resistor (sync) 47 | | | Mouser | |
| 15 | diode | | | Mouser | |
| 2 | 3 pin connector | | | | |
| 2 | jumper | | | eBay | |

Chipset / GPIO
--------------

| Count | Part | Price Per Batch | When Buying | Supplier Used | Comment |
| ----: | --- | ---: | ---: | --- | --- |
| 1 | PCB | 1.00 | 10 | Elecrow | |
| 1 | RP2040 Purple Board 16MB | 2.50 | 10 | AliExpress | |
| 1 | 28 pin connector, angled | 0.25 | 50 | eBay | 40 pin connector |
| 1 | 4 pin connector | | | | |
| 2 | 5 pin connector | | | | |
| 1 | jumper | | | eBay | |

32x32 LED Matrix
----------------

| Count | Part | Price Per Batch | When Buying | Supplier Used | Comment |
| ----: | --- | ---: | ---: | --- | --- |
| 4 | 16x16 WS2812 panel | 28.00 | 4 | AliExpress | |
| 1 | PSU 5V 90W | 21.50 | 1 | Berrybase | |
| 1 | woodwork done by father  | priceless | | Daddy | |

Links
-----

- [W65C02S6TPG-14](https://www.mouser.de/ProductDetail/Western-Design-Center-WDC/W65C816S6PG-14?qs=opBjA1TV900oFHK2UUDZKA%3D%3D)
- [RP2040 Purple Board 16MB]()
- [32 pin socket]()
- [PCM5102 I2S sound module]()
- [uSD socket]()
- [16x16 WS2812 panel]()

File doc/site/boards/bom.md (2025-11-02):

# BOM & Prices

At one point the prices when buying supplies got written down, indended to be
updated when buying the next batch.

All prices are in Euros.

## A Note About Getting 65C02s

When the project was started in mid 2023, 65C02 or 65SC02 were easy to obtain
for ~2,50 Euro per chip when buying 10. However since end of 2024 these chips
are getting harder to get. This results in two things: for one prices rise,
but more importantly there are more fakes around. Two out of three tries to
obtain reasonable priced refurbished 65C02s leads to discovering them being
fakes. This is one of the reasons why the Sorbus is good at detecting the
variant of the 6502 at hand.

The official price at Mouser is ~8.30/chip when buying 10 or more. So, if
prices of refurbished and new old stock rise even more, it makes more
sense to buy new chips.
[(WDC W65C02TPG-14 @ Mouser)](https://eu.mouser.com/ProductDetail/Western-Design-Center-WDC/W65C02S6TPG-14?qs=opBjA1TV903lvWo9AEKH5w%3D%3D)

## Sorbus Junior

| Count | Part | Price Per Batch | When Buying | Supplier Used | Comment |
| ----: | --- | ---: | ---: | --- | --- |
| 1 | PCB | 1.00 | 10 | Elecrow | |
| 1 | RP2040 Purple Board 16MB | 2.50 | 10 | AliExpress | |
| 1 | 65C02 or 65SC02 | 2.50 - 10.21 | 10 | eBay, AliExpress | Complicated |
| 4 | 32 pin socket | 1.00 | 50 | eBay | |
| 7 | 3.3k pull up resistors | | | | only 3 required  |
| 1 | capacitor | | | | optional |
| 2 | 5 pin connector | | | | |
| 1 | jumper | | | eBay | |

## Sorbus Sound

| Count | Part | Price Per Batch | When Buying | Supplier Used | Comment |
| ----: | --- | ---: | ---: | --- | --- |
| 1 | PCB | 1.00 | 10 | Elecrow | |
| 1 | RP2040 Purple Board 16MB | 2.50 | 10 | AliExpress | |
| 1 | 32 pin connector, angled | | | eBay | 40 pin connector |
| 1 | PCM5102 I2S sound module | 2.00 | 10 | AliExpress | |
| 1 | uSD socket | 0.70 | 10 | AliExpress | |
| 8 | diode | | | Mouser | |
| 1 | 3 pin connector | | | | |
| 1 | jumper | | | eBay | |

## Sorbus VGA

| Count | Part | Price Per Batch | When Buying | Supplier Used | Comment |
| ----: | --- | ---: | ---: | --- | --- |
| 1 | PCB | 1.00 | 10 | Elecrow | |
| 1 | RP2040 Purple Board 16MB | 2.50 | 10 | AliExpress | |
| 1 | 32 pin connector, angled | 0.25 | 50 | eBay | 40 pin connector |
| 1 | VGA Socket | 1.40 | 10 | eBay | |
| 3 | resistor 499 | | | Mouser | |
| 3 | resistor 1K | | | Mouser | |
| 3 | resistor 2K | | | Mouser | |
| 3 | resistor 4.02K | | | Mouser | |
| 3 | resistor 8.02K | | | Mouser | |
| 2 | resistor (sync) 47 | | | Mouser | |
| 15 | diode | | | Mouser | |
| 2 | 3 pin connector | | | | |
| 2 | jumper | | | eBay | |

## Chipset / GPIO

| Count | Part | Price Per Batch | When Buying | Supplier Used | Comment |
| ----: | --- | ---: | ---: | --- | --- |
| 1 | PCB | 1.00 | 10 | Elecrow | |
| 1 | RP2040 Purple Board 16MB | 2.50 | 10 | AliExpress | |
| 1 | 28 pin connector, angled | 0.25 | 50 | eBay | 40 pin connector |
| 1 | 4 pin connector | | | | |
| 2 | 5 pin connector | | | | |
| 1 | jumper | | | eBay | |

## 32x32 LED Matrix

| Count | Part | Price Per Batch | When Buying | Supplier Used | Comment |
| ----: | --- | ---: | ---: | --- | --- |
| 4 | 16x16 WS2812 panel | 28.00 | 4 | AliExpress | |
| 1 | PSU 5V 90W | 21.50 | 1 | Berrybase | |
| 1 | woodwork done by father  | priceless | | Daddy | |

## Links

Note that these links are just an example. It is very likely that you can save
more than 20% if you look for a similar item.

- [W65C02S6TPG-14](https://www.mouser.de/ProductDetail/Western-Design-Center-WDC/W65C816S6PG-14?qs=opBjA1TV900oFHK2UUDZKA%3D%3D)
- [RP2040 Purple Board 16MB](https://www.aliexpress.com/item/1005009735509158.html)
  (make sure that you get the 16MB variant, there also is a 4MB variant around which
  is not sufficiant)
- [32 pin socket](https://www.ebay.de/itm/334682289902)
- [PCM5102 I2S sound module](https://www.aliexpress.com/item/1005009800576806.html)
- [uSD socket](https://www.aliexpress.com/item/1005005591145849.html)
- [16x16 WS2812 panel](https://www.ebay.de/itm/315667763935) (You find them
  cheaper at AliExpress)

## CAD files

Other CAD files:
pcb/Sorbus-Sound/KiCad-RP-Pico-main/SketchUp Model/Pico.skp
pcb/Sorbus-VGA/KiCad-RP-Pico-main/SketchUp Model/Pico.skp

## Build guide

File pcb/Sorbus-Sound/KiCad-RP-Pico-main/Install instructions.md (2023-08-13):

# Install instructions

## 1. Copy the files locally

Copy the `RP-Pico Libraries` folder wherever you like on your computer.

## 2. Install the Raspberry Pi Pico board schema symbol

Use the `KiCad | Preferences | Manage Symbol Libraries...` command to manage the symbol library:



then select the global tab and click on the folder button:



navigate to the `RP-Pico Libraries` folder, select the `MCU_RaspberryPi_and_Boards.kicad_sym` file and open it:



et voilà, the first step is completed:



You can now close the symbol libraries manager window.

## 3. Install the Raspberry Pi Pico board footprint

You can use a similar approach to add the footprint to the footprint libraries manager, but I've found some issues that I've solved using the footprint editor, so here are the steps I suggest you to follow:

Open the footprint editor



wait for the footprints to load... then use the `File | Add Library` command:



confirm the `Global` choice:



and select the `MCU_RaspberriPi_and_Boards.pretty` folder (yes, the folder represent a footprint library on KiCad):



Now the library is installed on KiCad with the Raspberry Pi Pico footprint (double click on it to see it on the editor pane):



Don't close the windows as the next step start from here.

## 4. Install the Raspberry Pi Pico board footprint 3D visual

If not already open, open the the footprint editor

symbol library manager

double click on the `RPi_Pico_SMD_TH` footprint from the `MCU_RaspberriPi_and_Boards` library and then click on the `Footprint properties` icon:



In the footprint properties window, first select the `3D Settings` tab. Please note that the preview shows only the PCB board with the footprint added on step 3, without any 3D representation of the Raspberry Pi Pico board. Now click on the folder icon to add the 3D model:



Navigate to the `RP-Pico Libraries` folder, select the `Pico.wrl` file and wait until the model is shown in the right panel, then confirm with OK:



The model is already scaled and translated to match the footprint:



now close the `Footprint Properties` window, and the `Footprint Editor`, obviously saving the changes.

## Conclusion

Now that you've installed the schema and footprint and added the 3D model to the footprint, you can use the Raspberry Pi Pico board on your KiCad projects.

I've also added a test KiCad Project on the `Test` folder, that you can use to see an example of it.

Have fun!

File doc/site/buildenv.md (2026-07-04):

# Setting Up A Build Environment

## Installing The Bases

`make setup-apt-dev` will setup the development system with everything
required to build, transfer the firmware and run it.

This will run the following commands. Everything is prefixed with `sudo`.

```bash
apt update
apt install gdb-multiarch cmake gcc-arm-none-eabi libnewlib-arm-none-eabi \
    libstdc++-arm-none-eabi-newlib cc65 p7zip-full cpmtools build-essential \
    pkg-config libgd-dev mkdocs pkgconf libusb-1.0-0-dev microcom
gpasswd -a $USER dialout
gpasswd -a $USER plugdev
```

The $USER is added to the groups `dialout` and `plugdev`, so that it's
possible to use the terminal without sudo.

## Stow: An Elegant Way To Install Local Packages

Some software might not work very well in current versions, or it's not
available in apt based distros at all. For installing self-compile code
system-wide, there is a tool called stow. There are at least two
implementations available `gnu-stow` implemented in PERL, `nstow`
implemented in C. `gnu-stow` is available in Debian and Ubuntu. If you
want to use `nstow` instead, you can use the script provided.

To make easier use of this, there are a couple of shell scripts
implemented to help with setting this up.

Every script at start greets you with something like this (using
nstow-1.0 as an example):
```
This script downloads, compiles (when required) and installs
nstow-1.0

Download and compilation will be done in
/home/svolli/src/sorbus/local

Installation will be done into
/usr/local/stow/nstow-1.0
installation requires sudo

Links will be created in
/usr/local
need sudo to create links

Continue? 
```

It explains everything is going to. It names the package it's going to
install, which part of the filesystem it will use to download and compile,
where it will be installing the binaries, where it will be setting up
the links and for what steps it will be requiring sudo. And it will wait
for a confirmation there.

Also: please don't run those scripts as root, they will sudo when they
require to.

Uninstallation is easy (again using nstow-1.0 as an example):
```bash
cd /usr/local/stow
sudo stow -Dv nstow-1.0
sudo rm -rf nstow-1.0
```
That's it. You can use stow also to add your own packages. Instead of
installing to `/usr/local`, you install to
`/usr/local/stow/<your_package_name>`, and run
```bash
cd /usr/local/stow
sudo stow -v nstow-1.0
```

I've also seen a couple of tutorials on how to manage your ".dotfiles"
within git or alike and then have them symlinked to the correct places.

### src/tools/local-nstow.sh

This script downloads `nstow` from
[https://www.gnusto.com/](https://www.gnusto.com/), make small
adjustments, compiles it and installs it at `/usr/local/stow/nstow-1.0`.
From there it is then used to bootstrap itself.

Alternatively, you can use run `apt install stow` to install GNU stow,
which is written in perl. I perfer the C port, so that's why it's in
there. Also, to bootstrap, you'd need to run
`nstow-1.0/bin/stow nstow-1.0` since the executable is not in the $PATH.
The scripts takes care of this for you.

### src/tools/local-arm-none-eabi-toolchain.sh

Some change has been made to the toolchain so that code compiled on
Debian 13 (Trixie) runs significantly slower than the same code compiled
on Debian 12 (Bookworm). To compensate for that, the "best" precompiled
version is downloaded from the [ARM website](https://developer.arm.com/)
and installed.

### src/tools/local-picotool.sh

This gets a bit tough on the implementation. To figure out the version
number for displaying where to install to, it requires to check out the
picotool repository. So even before showing you the text what it's about
to do, it already downloads picotool via git.

And to build the picotool, it will also download the pico-sdk, unless
it's downloaded already. Also, for USB transfer, this requires the
usb-dev package to be installed, which is done by `make setup-apt-dev`.

### src/tools/local-exomizer.sh

exomizer is a tool for good 8-bit compression. The idea is to use the
powerful host machine for compression so that it can be decompressed good
on the target system.

However, distribution of this software package is a bit odd. Instead of
using the git repo of bitbucket, the source code is hosted as a zip
archive within a wiki set up using bitbucket.

The script tries to adjust for that as good as possible. Also this tool
is only needed if data needs to be compressed again due to changes. For
building the compressed data is checked in.

## Other Scripts Used For Development

There are also some other scripts I hacked together for making some
things a bit easier. Those I typically run from top level directory,
but they can be run from anywhere.

### src/tools/upload.sh

This it the script that I use to compile and upload. The default
configuration is to upload new firmware and the kernel ROM. To also
upload the internal drive image, you can use
`src/tools/upload.sh build/rp2040/jam_alpha_picotool.uf2`

### src/tools/mkdocs.sh

This is a wrapper for the [mkdocs](https://www.mkdocs.org/) suite that
is used to generate [this documentation](https://sorbus.xayax.net/). It
mostly makes sure that generated parts are not outdated and provides an
addition parameter for uploading.

### src/tools/testbuild.sh

This script checks out the current code into `../testbuild` and compiles
it there running `make all`, to make sure that what will be pushed is at
least buildable.

### src/tools/external-1kLEDsIsNoLimit.sh

This is a script that downloads my demo
[1k Is No Limit](https://xayax.net/1k_leds_is_no_limit/), assembles it,
and copies the binary file for deployment.

The binary is also checked in, so running this is usually not necessary.

### src/tools/external-cpm65.sh

This tries do download and compile the CP/M-65 operating system.

The binaries are also checked in, so running this is usually not necessary.

### src/tools/external-llvm-mos-sdk.sh

This tries to install the llvm-mos toolchain, required to build CP/M-65.
As CP/M-65 is also checked in, running this is usually not necessary.

### src/tools/external-taliforth2.sh

This downloads the latest version of
[TaliForth2](https://github.com/SamCoVT/TaliForth2). However this has
become a bit of a hit and miss, as some versions of Tali Forth 2 just
don't work on the Sorbus.

The binary is also checked in, so running this is usually not necessary.

## tl;dr

For setting up development on a new system, I typically run these
commands in the following order (no sudo required, as they run sudo
themselves):
```bash
make setup-apt-dev
src/tools/local-nstow.sh
src/tools/local-arm-none-eabi-toolchain.sh
src/tools/local-picotool.sh
```

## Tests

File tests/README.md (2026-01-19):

# Sorbus Testing Framework

A testing framework that runs the RP2040 chipset code using https://github.com/c1570/rp2040js/ and wires it up with a 65C02 CPU card emulation based on https://github.com/floooh/chips .

## Running

`run_tests.sh`

## Architecture

The framework consists of:

1. **CPU Card Emulation (C code)**: `cpu_card_wrapper.c` - Wraps the m65c02 emulator to provide a simple tick() interface
2. **FFI Bridge**: Node.js module using `koffi` library to call C functions from JavaScript
3. **Test Runner**: `test_runner.ts` - Main emulator that:
   - Loads RP2040 firmware
   - Initializes RP2040 via rp2040js
   - Connects RP2040 GPIO pins to the 65C02 CPU card
   - Runs the emulation loop

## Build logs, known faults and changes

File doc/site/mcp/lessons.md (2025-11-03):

# MCP Examples

Here are some examples how you can see what the CPU does during every
single clock cycle. Please note, that writing to that stack will happen
at different addresses within the $0100-$01ff area, as the stackpointer
is not initialized.

## Commands used:
- `s <cycles>`
    - let the CPU run for &lt;cycles&gt; cycles / steps
    - the parameter is decimal
- `f <start> <end> <value>`
    - fill the memory from &lt;start&gt; to &lt;end&gt; with the value
      &lt;value&gt;
    - all parameter are hexadecimal
- `reset <cycles>`
    - pull the reset line to low for &lt;cycles&gt; cycles
    - the parameter is decimal
- `: <start> <value> (<value> ...)`
    - write value(s) to memory beginning at start
    - &lt;start&gt; and the colon (`:`) may be swapped
    - all parameter are hexadecimal

Commands are case sensitive, hexadecimal numbers are not.

### Output:

Let's use a fictional example to explain the output:
```txt
100:fffc r 00 R  >
```

From left to right:

- `100:`
    - number of cycles left to run: if number > 999 then 999 will be displayed.
- `fffc`
    - current state of address-bus → address being accessed.
- `r`
    - data is being read. (Only other value here would be "w" for write.)
- `00`
    - current state of data-bus → value being read or written.
- `R`
    - other CPU lines being triggered by pulling low: R=reset (triggered in
    this case), others are (not triggered here): N=nmi, I=irq.
- `>`
    - the monitor command prompt, you can type while the CPU is running.

## Lesson 1: reset and NOP

This lesson will run on 6502, 65C02 and 65816.

### Commands to enter:

```txt
f 0000 ffff ea
reset 5
s 17
```

### Output:
```txt
 16:eaeb r ea R  >
 15:eaec r ea R  >
 14:eaec r ea R  >
 13:eaec r ea R  >
 12:eaec r ea R  >
 11:eaec r ea    >
 10:eaec r ea    >
  9:eaec r ea    >
  8:01f7 r ea    >
  7:01f6 r ea    >
  6:01f5 r ea    >
  5:fffc r ea    >
  4:fffd r ea    >
  3:eaea r ea    >
  2:eaeb r ea    >
  1:eaeb r ea    >
  0:eaec r ea    >
```

<div class='explain_wrap' markdown>
### Explanation:

(hover to show)
<div class='explain_main' markdown>
- During cycles 16-12 the CPU does nothing, since reset is triggered.
- During cycles 11-9 the CPU starts running internally.
- During cycles 8-6 stack access is happening, because reset is implemented
  similar to an interrupt. The behavour until here might differ from chip to chip!
- During cycles 5-4 the reset vector is read, low byte first.
- During cycles 3-2 a NOP OpCode are processed. Since the OpCode takes two
  cycles to execute, the CPU triggers a dummy read on the following address.
  Just in case, there is a parameter for an instruction to fetch.
- During cycles 1-0 the next NOP OpCode is processed.
</div></div>

## Lesson 2: another kind of NOP

This only run on 65C02 and 65SC02. The OpCode used has no equivalent on
6502, 65CE02 and 65816.

### Commands to enter:

```txt
f 0000 ffff 33
reset 5
s 17
```

### Output:
```txt
[...skipping unimportant lines...]
  5:fffc r 33    >
  4:fffd r 33    >
  3:3333 r 33    >
  2:3334 r 33    >
  1:3335 r 33    >
  0:3336 r 33    >
```

<div class='explain_wrap' markdown>
### Explanation:

(hover to show)
<div class='explain_main' markdown>
- During cycles 5-4 the reset vector is read, low byte first.
- During cycles 3-0 undocumented OpCodes are processed. This is handles
  differently on each variant:
    - (6502: the CPU executes two different instructions at once: ROL and AND.)
    - (65816: since each OpCode is defined, there is no example on how undefined
      OpCodes work.)
    - 65C02 and 65SC02: each undocumented OpCode is executing a "NOP", but the
      parameter can differ from OpCode to OpCode. This is a very interresting
      one: no dummy reads are executed, this instruction only requires a single
      clock cycle. This is not possible on the 6502 or 65816.
    - (65CE02 will execute a long range BMI; however, the NOP only takes a
      single cycle there)
</div></div>

## Lesson 3: a simple program

If you ran lessons 1 and/or 2, power cycle the Sorbus Computer. This ensures
that the program executed will be in memory. This lesson will run on 6502,
65C02 and 65816. Also take a good look at the output of the memory dump. Does
that look familiar to you?

### Commands to enter:

```txt
f 1000 1100 00
: fffc 00 04
reset 5
freq 1000
s 345
freq 5
m 1000
```

### Output:
```txt
[...skipping a lot of output...]
  5:0421 r b0    >
  4:0422 r fe    >
  3:0423 r e8    >
  2:0421 r b0    >
  1:0422 r fe    >
  0:0423 r e8    >m 1000
: 1000  00 01 01 02 03 05 08 0d  15 22 37 59 90 e9 00 00
  0:0423 r e8    >
```

<div class='explain_wrap' markdown>
### Explanation:

(hover to show)
<div class='explain_main' markdown>
The rest of the output show that the program running is in an endless loop
once calculation is done. The output is of course the start of the
[Fibonacci sequence](https://en.wikipedia.org/wiki/Fibonacci_sequence)
as far as it can be calculated in 8 bits. The code is stopping when the
add overflows.

Source code: (excluding first JMP instruction)
```asm6502
   clc
   cld
   ldx   #$01
   stx   BUFFER+1
   dex
   stx   BUFFER

@loop:
   lda   BUFFER,x
   inx
   adc   BUFFER,x
   bcs   *
   inx
   sta   BUFFER,x
   dex
   bne   @loop
```
</div></div>

## Lesson 4: subroutine

This runs on all CPUs: 65C02, 6502 and 65816. No need to powercycle.

### Commands to enter:

```txt
: fffc 03 04
reset 5
s 35
```

### Output:
```txt
 23:fffc r 03    >
 22:fffd r 04    >
 21:0403 r 4c    >
 20:0404 r 2a    >
 19:0405 r 04    >
 18:042a r 20    >
 17:042b r 57    >
 16:01dc r ea    >
 15:01dc w 04    >
 14:01db w 2c    >
 13:042c r 04    >
 12:0457 r ea    >
 11:0458 r ea    >
 10:0458 r ea    >
  9:0459 r 60    >
  8:0459 r 60    >
  7:045a r 00    >
  6:01da r ea    >
  5:01db r 2c    >
  4:01dc r 04    >
  3:042c r 04    >
  2:042d r 4c    >
  1:042e r 2d    >
  0:042f r 04    >
```

<div class='explain_wrap' markdown>
### Explanation:

(hover to show)
<div class='explain_main' markdown>
- After the reset, the first instruction is a JuMP, so I can easily modify
  the code without the need to change the start address.
- During the cycles 18-13 the CPU executes a Jump to SubRoutine:
    - 18: fetch the JSR OpCode
    - 17: fetch low byte of jump target address
    - 16: dummy read of stack
    - 15: write high byte of return address minus 1 to stack
    - 14: write low byte of return address minus 1 to stack
    - 13: fetch high byte of jump target address and perform jump
- The ReTurn from Subroutine starts at cycle 8 (cycle 9 is the dummy read
  from the NOP OpCode at 10):
    - 8: fetch the RTS OpCode
    - 7: dummy read non-existant parameter
    - 6: dummy read from stack
    - 5: fetch low byte of return address minus 1 from stack
    - 4: fetch high byte of return address minus 1 from stack
    - 3: dummy read from memory to adjust program counter to correct return
      address and jump back
    - 2-0: endless loop
- Interesting how the return address minus one gets written to stack and
  how it is compensated by the return call. This seems to be caused by the
  split of reading the low and high bytes of the target address.

Source code: (excluding first JMP instruction)
```asm6502
   jsr   jsrtest
   jmp   *

jsrtest:
   nop
   nop
   rts
   brk
```
</div></div>

## Lesson 5: data on stack

This runs on all CPUs: 65C02, 6502 and 65816. No need to powercycle.

### Commands to enter:

```txt
: FFFC 06 04
reset 5
s 30
```

### Output:
```txt
 18:fffc r 06    >
 17:fffd r 04    >
 16:0406 r 4c    >
 15:0407 r 30    >
 14:0408 r 04    >
 13:0430 r a9    >
 12:0431 r 42    >
 11:0432 r 48    >
 10:0433 r 68    >
  9:01f1 w 42    >
  8:0433 r 68    >
  7:0434 r 4c    >
  6:01f0 r ea    >
  5:01f1 r 42    >
  4:0434 r 4c    >
  3:0435 r 34    >
  2:0436 r 04    >
  1:0434 r 4c    >
  0:0435 r 34    >
```

<div class='explain_wrap' markdown>
### Explanation:

(hover to show)
<div class='explain_main' markdown>
- After the reset, the first instruction is a JuMP, so I can easily modify
  the code without the need to change the start address.
- Next the accumulator is loaded with a recognizable value ($42).
- Push the value on the stack
    - 11: fetch the PHA OpCode
    - 10: dummy argument read
    - 9: push value to the stack
- Pull the value from the stack
    - 8: fetch the PLA OpCode
    - 7: dummy argument read
    - 6: dummy read from stack to adjust stack pointer
    - 5: pull value from the stack
- End program
    - 4-0: endless loop

Source code: (excluding first JMP instruction)
```asm6502
   lda   #$42
   pha
   pla
   jmp   *
```
</div></div>

## Lesson 6: interrupt via IRQ line

This runs on all CPUs: 65C02, 6502 and 65816. No need to powercycle.

### Commands to enter:

```txt
: FFFC 09 04
reset 5
s 30
irq 8
s 36
```

### Output:
```txt
 13:0437 r a9    >
 12:0438 r 5d    >
 11:0439 r 8d    >
 10:043a r fe    >
  9:043b r ff    >
  8:fffe w 5d    >
  7:043c r a9    >
  6:043d r 04    >
  5:043e r 8d    >
  4:043f r ff    >
  3:0440 r ff    >
  2:ffff w 04    >
  1:0441 r ea    >
  0:0442 r ea    >irq 8
 35:0442 r ea   I>
 34:0443 r ea   I>
 33:0443 r ea   I>
 32:0444 r 58   I>
 31:0444 r 58   I>
 30:0445 r 4c   I>
 29:0445 r 4c   I>
 28:0446 r 45   I>
 27:0447 r 04    >
 26:0445 r 4c    >
 25:0445 r 4c    >
 24:01eb w 04    >
 23:01ea w 45    >
 22:01e9 w 21    >
 21:fffe r 5d    >
 20:ffff r 04    >
 19:045d r 48    >
 18:045e r ea    >
 17:01e8 w 04    >
 16:045e r ea    >
 15:045f r ea    >
 14:045f r ea    >
 13:0460 r 68    >
 12:0460 r 68    >
 11:0461 r 40    >
 10:01e7 r ea    >
  9:01e8 r 04    >
  8:0461 r 40    >
  7:0462 r 00    >
  6:01e8 r 04    >
  5:01e9 r 21    >
  4:01ea r 45    >
  3:01eb r 04    >
  2:0445 r 4c    >
  1:0446 r 45    >
  0:0447 r 04    >
```

<div class='explain_wrap' markdown>
### Explanation:

(hover to show)
<div class='explain_main' markdown>
- after the reset, the first instruction is a JuMP, so I can easily modify
  the code without the need to change the start address.
- after that the IRQ vector gets set up, until "IRQ 9" is entered.
- main program waits for interrupts
    - 35-30: processing OpCodes NOP, NOP, and CLI (CLear Interrupt disable)
    - 29-27: processing endless loop JuMP, and wait for interrupt to trigger
- *interrupt is triggered*
    - 26-25: two dummy reads: interrupt is triggered while fetching OpCode
    - 24-23: write high byte and low byte of return address to the stack
    - 22: write processor status to stack
    - 21-20: read interrupt vector
    - 19-9: write to and read from stack (like previous example)
- returning from interrupts
    - 8: fetch RTI (ReTurn from Interrupt) OpCode
    - 7: dummy argument read
    - 6: dummy to adjust stack pointer
    - 5: read processor status from stack
    - 4-3: read low byte and high byte of return address from stack
- returned to main program
    - 2-0: process endless loop interrupt at 28-26
- it is noteworthy, that return address is not "minus one" as in the JSR

Source code: (excluding first JMP instruction)
```asm6502
   lda   #<irqtest
   sta   $fffe
   lda   #>irqtest
   sta   $ffff
   nop
   nop
   nop
   cli
   jmp   *

irqtest:
   pha
   nop
   nop
   pla
   rti
   brk
```
</div></div>

## Lesson 7: interrput via BRK OpCode

This runs on all CPUs: 65C02, 6502 and 65816. No need to powercycle.

### Commands to enter:

```txt
: FFFC 0C 04
reset 5
s 54
```

### Output:
```txt
 37:0448 r a9    >
 36:0449 r 5d    >
 35:044a r 8d    >
 34:044b r fe    >
 33:044c r ff    >
 32:fffe w 5d    >
 31:044d r a9    >
 30:044e r 04    >
 29:044f r 8d    >
 28:0450 r ff    >
 27:0451 r ff    >
 26:ffff w 04    >
 25:0452 r 00    >
 24:0453 r ea    >
 23:01ee w 04    >
 22:01ed w 54    >
 21:01ec w 35    >
 20:fffe r 5d    >
 19:ffff r 04    >
 18:045d r 48    >
 17:045e r ea    >
 16:01eb w 04    >
 15:045e r ea    >
 14:045f r ea    >
 13:045f r ea    >
 12:0460 r 68    >
 11:0460 r 68    >
 10:0461 r 40    >
  9:01ea r ea    >
  8:01eb r 04    >
  7:0461 r 40    >
  6:0462 r 00    >
  5:01eb r 04    >
  4:01ec r 35    >
  3:01ed r 54    >
  2:01ee r 04    >
  1:0436 r ea    >
  0:0437 r ea    >
```

<div class='explain_wrap' markdown>
### Explanation:

(hover to show)
<div class='explain_main' markdown>
- after the reset, the first instruction is a JuMP, so I can easily modify
  the code without the need to change the start address
- After that the IRQ vector gets set up, and the BRK OpCode is processed
    - 37-26: set up IRQ vector which is also used for the software interrupt
      using BRK (BReaK)
    - 25: process BRK Opcode
    - 24: dummy argument read
- process BRK interrupt
    - 23-22: write high byte and low byte of return address to the stack
      &nbsp; <u class="underlined">NOTE:</u> the return address is the one after the dummy
      read, the documentation states that the BRK OpCode uses two bytes
    - 21: write processor status to stack
    - 20-19: read interrupt vector
    - 18-8: write to and read from stack (like previous example)
- return from interrupt
    - 7: fetch RTI (ReTurn from Interrupt) OpCode
    - 6: dummy argument read
    - 5: dummy to adjust stack pointer
    - 4: read processor status from stack
    - 3-2: read low byte and high byte of return address from stack
- returned from interrupt
    - 1-0: process the following NOP OpCode

Source code: (excluding first JMP instruction)
```asm6502
   lda   #<irqtest
   sta   $fffe
   lda   #>irqtest
   sta   $ffff
   brk
   nop
   nop
   nop
   jmp   *

irqtest:
   pha
   nop
   nop
   pla
   rti
   brk
```
</div></div>

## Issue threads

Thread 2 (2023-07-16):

Update CPU board with optional solder access points

SvOlli, 2023-07-16:
Nice to have additions for the CPU board:

- open solder points for sync, vector pull, set overflow and other pins
- open solder points for adding leds to sync, vector pull, reset, irq, nmi and other pins

SvOlli, 2025-05-08:
Partly done with the Junior. All suggested pins not done due to space constrains on the board. Also a new version with RP2350B makes more sense now.

Closed 2025-05-08.

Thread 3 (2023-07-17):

Implement CPU tester core

SvOlli, 2023-07-17:
This is a nice platform to implement testing of a 6502 CPU regardless of the variant.
- For this the CPU detection should be expanded to detect also 65SC02 and 65CE02.
- If there are other pin compatible variants in a DIP package available as well.
- What would most probably not work: running at high frequencies way more than 1MHz

SvOlli, 2025-05-08:
All known CPUs with the same pinout are supported now by CPU detection core which is run automatically during startup of MCP and JAM cores.

Closed 2025-05-08.

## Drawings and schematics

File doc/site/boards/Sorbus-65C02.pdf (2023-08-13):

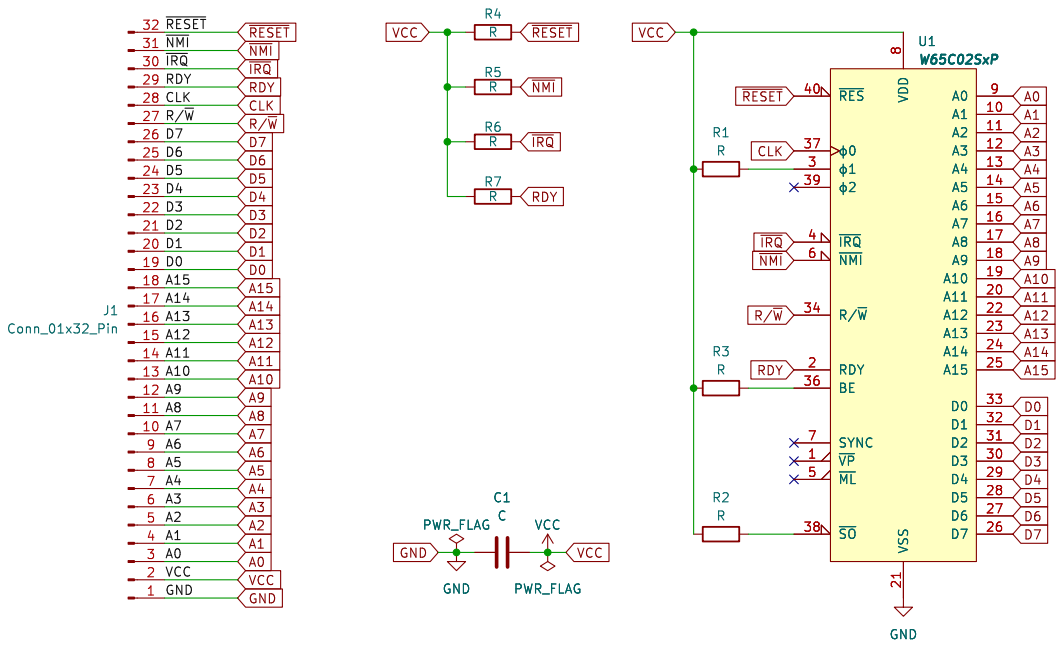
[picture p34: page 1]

File: Sorbus-65C02.kicad_sch Sheet: / GND

Id: 1/1 Title: Sorbus Computer 65C02

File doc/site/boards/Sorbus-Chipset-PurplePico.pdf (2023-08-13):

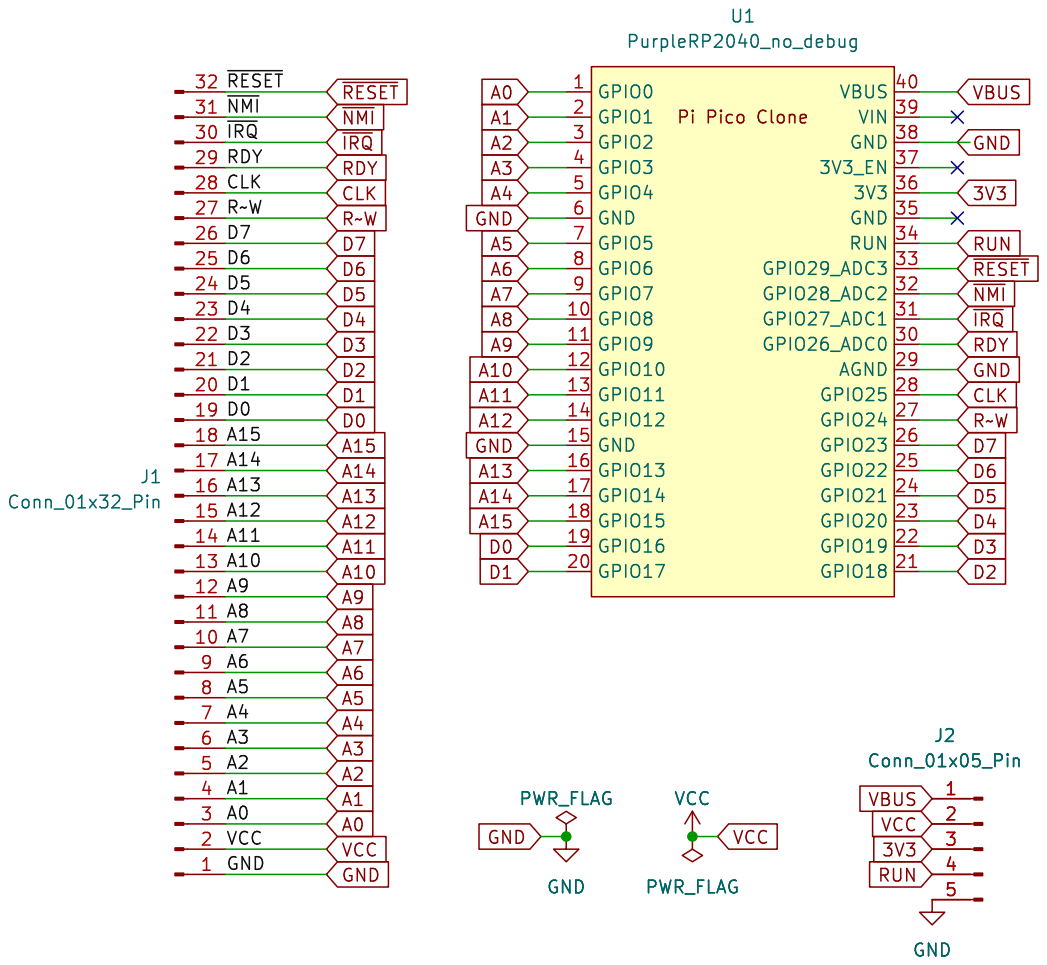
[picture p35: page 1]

File: Sorbus-Chipset-PurplePico.kicad_sch Sheet: /
Id: 1/1 Title: Sorbus Computer RP2040 Purple

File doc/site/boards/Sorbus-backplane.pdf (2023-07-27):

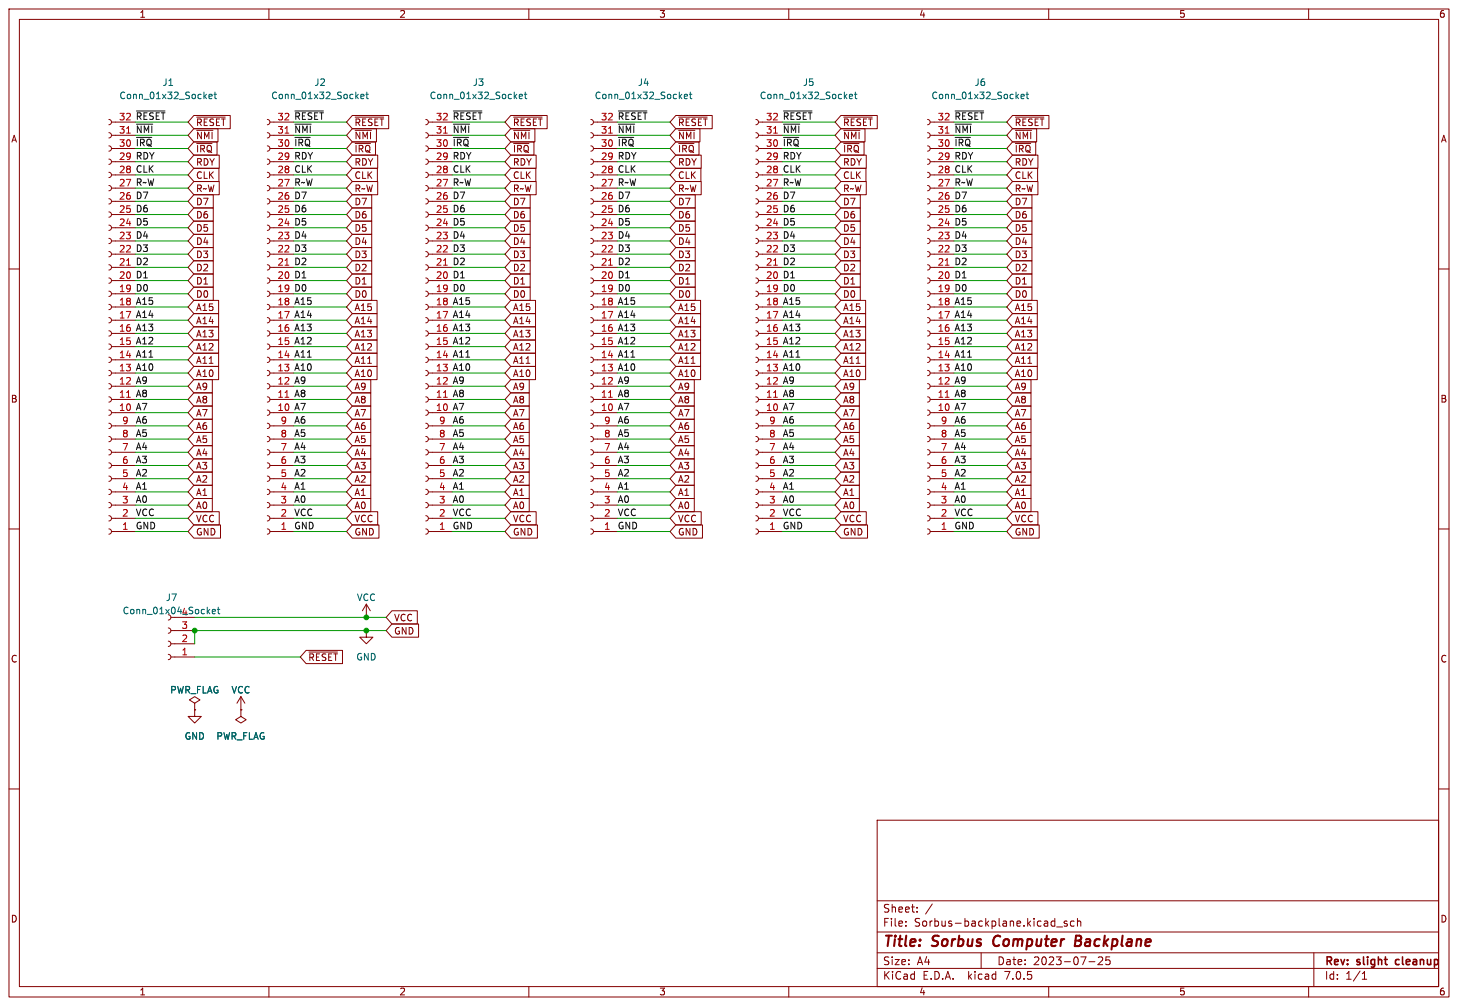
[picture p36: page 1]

File: Sorbus-backplane.kicad_sch Sheet: /
Id: 1/1 Title: Sorbus Computer Backplane

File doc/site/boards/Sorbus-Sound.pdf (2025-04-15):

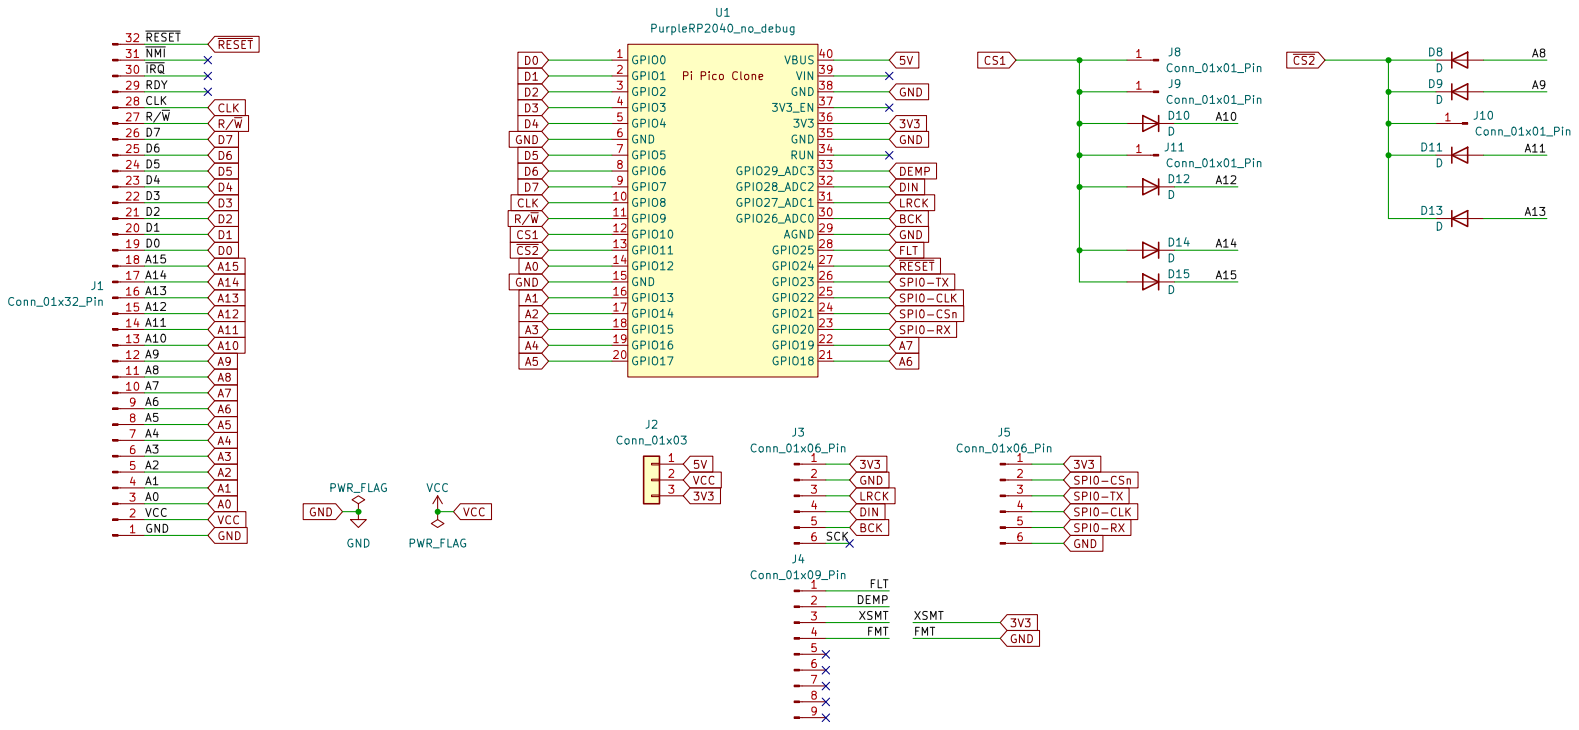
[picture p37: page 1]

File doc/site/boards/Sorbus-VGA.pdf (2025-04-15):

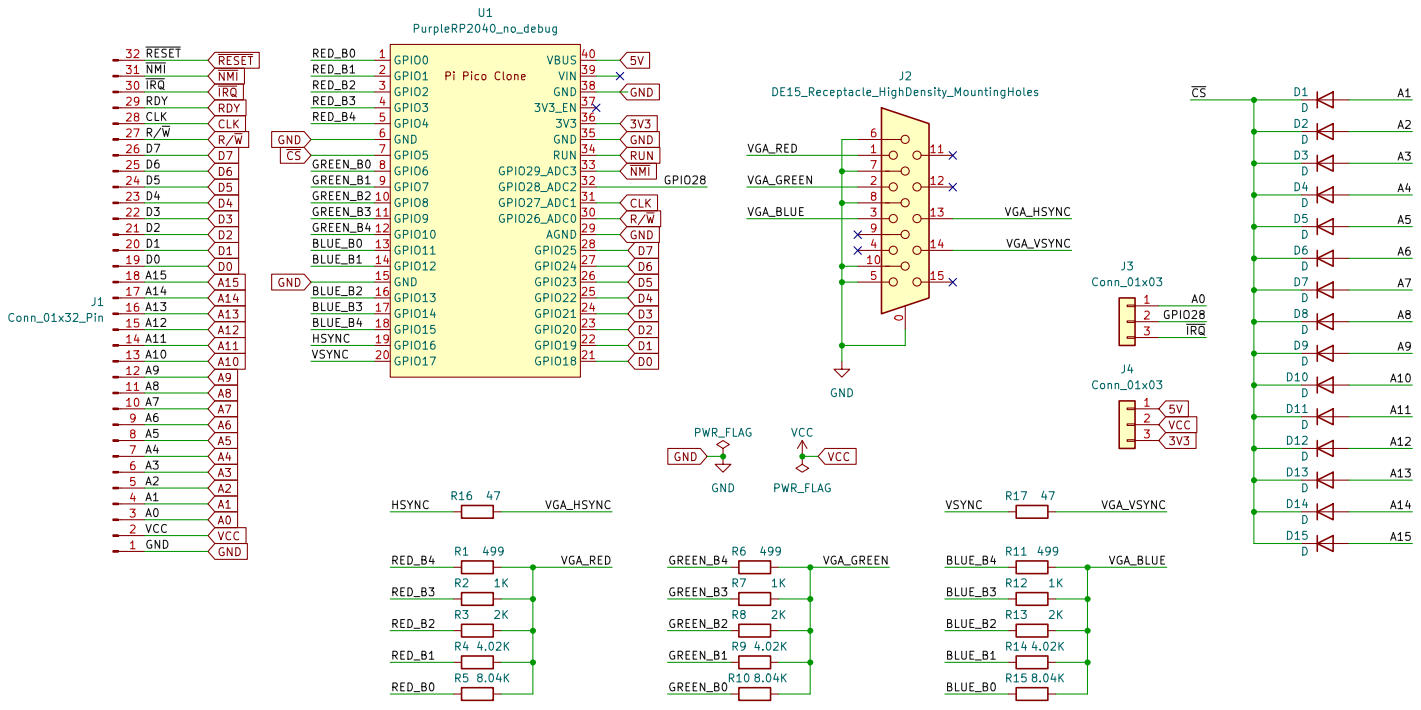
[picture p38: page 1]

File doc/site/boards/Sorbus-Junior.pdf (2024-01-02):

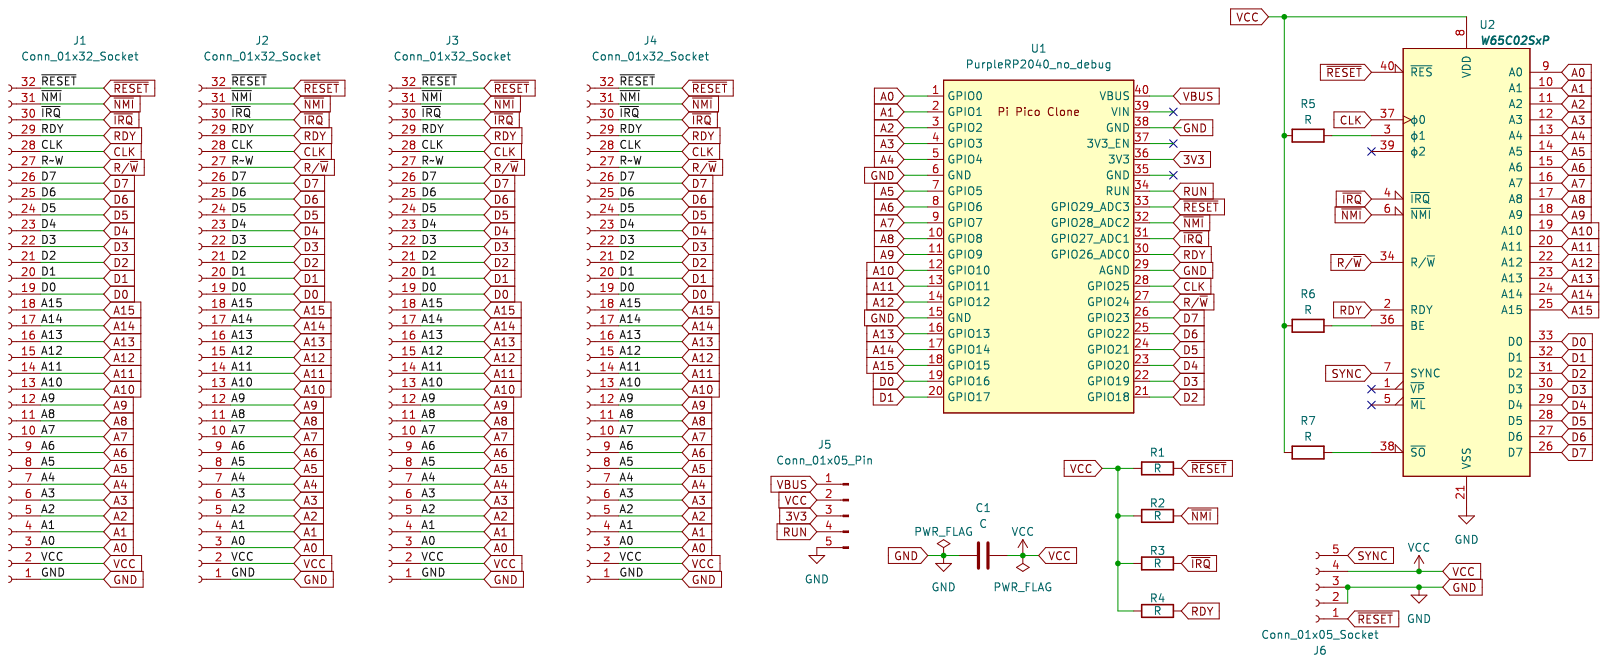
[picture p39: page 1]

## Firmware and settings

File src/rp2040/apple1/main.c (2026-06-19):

/**
 * Copyright (c) 2023 Sven Oliver "SvOlli" Moll
 *
 * SPDX-License-Identifier: GPL-3.0-or-later
 *
 * This program implements Apple Computer I emulation
 * for the Sorbus Computer
 */

#include <time.h>
#include <stdio.h>
#include <ctype.h>
#include <string.h>

#include "rp2040_purple.h"
#include <pico/stdlib.h>
#include <pico/util/queue.h>
#include <pico/multicore.h>
#include <pico/platform.h>
#include <pico/binary_info.h>

bi_decl(bi_program_name("Sorbus Computer Apple 1 Core"))
bi_decl(bi_program_description("make the Sorbus Computer an Apple 1 clone"))
bi_decl(bi_program_url("https://sorbus.xayax.net/"))

#include "bus.h"
#include "cpudetect_apple1.h"
#include "a1hello.h"
#include "krusader.h"

// set this to 1 to run for 5 million cycles while keeping time
#define SPEED_TEST 0
// the delay between characters printed, the Apple 1 can only add
// a single characters per frame displayed at 60Hz
#define WRITE_DELAY_US 16666
// this is where the write protected area starts
// for Krusader you can change this to 0xE000
#define ROM_START (0xFF00)

uint32_t write_delay_us = WRITE_DELAY_US;

queue_t keyboard_queue;
queue_t display_queue;

uint8_t memory[0x10000]; // 64k of RAM/ROM
uint32_t state;
uint32_t address;

volatile bool enable_print = false;

volatile uint32_t cycles_left_reset = 5;
volatile uint32_t cycles_left_nmi   = 0;
volatile uint32_t cycles_left_irq   = 0;


// sequence to clear screen
// generated by shell: "clear | hd"
const uint8_t clear_screen_sequence[] =
{
   0x1b,0x5b,0x48,0x1b,0x5b,0x32,0x4a,0x1b,0x5b,0x33,0x4a,0
};


// small relocateable 6502 routine to print all characters to display
// assembled by hand
const uint8_t printloop[] =
{
   0xa2,0x00,0x8a,0x20,0xef,0xff,0xe8,0x18,0x90,0xf8
};


int apple2output( int c )
{
   c &= 0x7f;
   if( c == 0x0d )
   {
      // don't modify return below
   }
   else if( c <= 0x1f )
   {
      // bytes below space are not printed
      // (except for return), but still cause a delay
      c = 1;
   }
   else if( c >= 0x60 )
   {
      // bytes above underscore will be trimmed down
      c &= 0x5f;
   }
   return c;
}


int input2apple( int c )
{
   // handle special cases
   if( (c == 0x08) || (c == 0x7f) )
   {
      // backspace
      return 0xdf;
   }
   else if( (c == 0x60) || (c >= 0x7b) )
   {
      // "`{|}~" are meta keys
      return c;
   }
   // Apple 1 only has upper charset
   if( (c >= 'a') && (c <= 'z') )
   {
      c &= 0xdf;
   }
   return c | 0x80;
}


void run_console()
{
   int in = PICO_ERROR_TIMEOUT, out;
   int col = 0;
   uint64_t next_write = time_us_64();

   for(;;)
   {
      if( in == PICO_ERROR_TIMEOUT )
      {
         in = getchar_timeout_us(1000);
      }
      if( in != PICO_ERROR_TIMEOUT )
      {
         in = input2apple( in );
         if( in >= 0x80 )
         {
            // standard key, hand over to Apple 1
            if( queue_try_add( &keyboard_queue, &in ) )
            {
               // only get next key once this is processed
               in = PICO_ERROR_TIMEOUT;

               // problem: a never processed key can prevent from
               // handling the reset key. this can be only delayed
               // by expanding the input queue
            }
         }
         else
         {
            // meta key: print an move cursor over
            // -> output visible, but does not interfere
            putchar( in );
            putchar( '\b' );
            switch( in )
            {
               case '`':
                  cycles_left_reset = 8;
                  enable_print = false;
                  break;
               case '{':
                  write_delay_us = 0;
                  break;
               case '}':
                  write_delay_us = WRITE_DELAY_US;
                  break;
               case '~':
                  printf( "%s", clear_screen_sequence );
                  break;
               default:
                  break;
            }
            in = PICO_ERROR_TIMEOUT;
         }
      }

      if( queue_try_remove( &display_queue, &out ) )
      {
         out = apple2output( out );
         if( out >= 0x20 )
         {
            col++;
         }
         if( out == 0x0d )
         {
            putchar( '\n' );
            col = 0;
         }
         if( col > 40 )
         {
            putchar( '\n' );
            col = 1;
         }

         if( out > 0 )
         {
            while( time_us_64() < next_write )
            {
               tight_loop_contents();
            }
            if( out > 1 )
            {
               // 1 is an indicator of delay, but not print
               putchar( out );
            }
            next_write = time_us_64() + write_delay_us;
         }
      }

      tight_loop_contents();
   }
}


static inline void handle_ram()
{
   // assume that data bus direction is already set
   if( state & bus_config.mask_rw )
   {
      // read from memory and write to bus
      gpio_put_masked( bus_config.mask_data, ((uint32_t)memory[address]) << bus_config.shift_data );
   }
   else
   {
      // read from bus and write to memory write
      // WozMon (and Krusader) is in ROM, so only accept writes below romstart
      if( address < ROM_START )
      {
         memory[address] = (gpio_get_all() >> bus_config.shift_data); // truncate is intended
      }
   }
}


static inline void handle_pia()
{
   int c;
   switch( address )
   {
      case 0xD010: // PIA.A: keyboard
         if( state & bus_config.mask_rw )
         {
            // CPU reads register
            if( queue_try_remove( &keyboard_queue, &c ) )
            {
               memory[address] = input2apple( c );
            }
            gpio_put_masked( bus_config.mask_data, ((uint32_t)memory[address]) << bus_config.shift_data );
         }
         else
         {
            // CPU writes register
            memory[address] = (gpio_get_all() >> bus_config.shift_data);
         }
         break;
      case 0xD011: // PIA.A: control register
         if( state & bus_config.mask_rw )
         {
            // CPU reads register
            memory[address] &= 0x7f;
            memory[address] |= queue_is_empty( &keyboard_queue ) ? 0 : 0x80;
            gpio_put_masked( bus_config.mask_data, ((uint32_t)memory[address]) << bus_config.shift_data );
         }
         else
         {
            // CPU writes register
            memory[address] = (gpio_get_all() >> bus_config.shift_data);
         }
         break;
      case 0xD012: // PIA.B: display
         if( state & bus_config.mask_rw )
         {
            // CPU reads register
            memory[address] &= 0x7f;
            memory[address] |= queue_is_empty( &display_queue ) ? 0 : 0x80;
            gpio_put_masked( bus_config.mask_data, ((uint32_t)memory[address]) << bus_config.shift_data );
         }
         else
         {
            // CPU writes register
            memory[address] = (gpio_get_all() >> bus_config.shift_data);
            c = memory[address];
            if( enable_print )
            {
               queue_try_add( &display_queue, &c );
            }
         }
         break;
      case 0xD013: // PIA.B: control register
         if( state & bus_config.mask_rw )
         {
            // CPU reads register
            gpio_put_masked( bus_config.mask_data, ((uint32_t)memory[address]) << bus_config.shift_data );
            memory[address] &= 0x7f;
         }
         else
         {
            // CPU writes register
            memory[address] = (gpio_get_all() >> bus_config.shift_data);
            enable_print = true;
         }
         break;
      default:
         break;
   }
}


void run_bus()
{
#if SPEED_TEST
   uint64_t time_start, time_end;
   double time_exec;
   double time_hz;
   uint32_t cyc;

   time_start = time_us_64();
   for(cyc = 0; cyc < 5000000; ++cyc)
#else
   // when not running as speed test run main loop forever
   for(;;)
#endif
   {
      if( cycles_left_reset )
      {
         int dummy;
         --cycles_left_reset;
         gpio_clr_mask( bus_config.mask_reset );
         while( queue_try_remove( &keyboard_queue, &dummy ) )
         {
            // just loop until queue is empty
         }
      }
      else
      {
         gpio_set_mask( bus_config.mask_reset );
      }

      if( cycles_left_nmi )
      {
         --cycles_left_nmi;
         gpio_clr_mask( bus_config.mask_nmi );
      }
      else
      {
         gpio_set_mask( bus_config.mask_nmi );
      }

      if( cycles_left_irq )
      {
         --cycles_left_irq;
         gpio_clr_mask( bus_config.mask_irq );
      }
      else
      {
         gpio_set_mask( bus_config.mask_irq );
      }

      // done: set clock to high
      gpio_set_mask( bus_config.mask_clock );

      // bus should be still valid from clock low
      state = gpio_get_all();

      // setup bus direction so I/O can settle
      if( state & bus_config.mask_rw )
      {
         // read from memory and write to bus
         gpio_set_dir_out_masked( bus_config.mask_data );
      }
      else
      {
         // read from bus and write to memory write
         gpio_set_dir_in_masked( bus_config.mask_data );
      }

      address = ((state & bus_config.mask_address) >> bus_config.shift_address);

      // setup data
      if( (address & 0xFFF0) == 0xD010 )
      {
         // handle_io
         handle_pia();
      }
      else
      {
         handle_ram();
      }

      // done: set clock to low
      gpio_clr_mask( bus_config.mask_clock );
   }

#if SPEED_TEST
   time_end = time_us_64();
   time_exec = (double)(time_end - time_start) / CLOCKS_PER_SEC / 10000;
   time_hz = (double)cyc / time_exec;
   for(;;)
   {
      printf( "\rbus has terminated after %d cycles in %.06f seconds: %.0fHz ", cyc, time_exec, time_hz );
      sleep_ms(2000);
   }
#endif
}


int main()
{
   // setup UART
   stdio_init_all();
   uart_set_translate_crlf( uart0, true );

   // setup between UART core and bus core
   queue_init( &keyboard_queue, sizeof(int), 256 );
   queue_init( &display_queue, sizeof(int), 1 );

   // clean out memory
   // yes, this is not original, but more userfriendly and also easier
   // to implement a real DRAM initstate profile
   // also we've got 64k addressable, which is not original as well
   memset( &memory[0x0000], 0x00, sizeof(memory) );

   // let's preload some code
   memcpy( &memory[0x02F0], &printloop[0], sizeof(printloop) );
   memcpy( &memory[0x0280], &cpudetect_0280[0], sizeof(cpudetect_0280) );
   memcpy( &memory[0x0800], &a1hello_0800[0], sizeof(a1hello_0800) );

   // and we need also setup the ROM
   // it's implemented as part of RAM with write disabled
   memcpy( &memory[0xE000], &krusader_e000[0], sizeof(krusader_e000) );

   // setup the bus and run the bus core
   bus_init();
   multicore_launch_core1( run_bus );

   // run interactive console -> should never return
   run_console();

   return 0;
}

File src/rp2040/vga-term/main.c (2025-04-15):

/*
 * Terminal software for Pi Pico
 * USB keyboard input, VGA video output, communication with RC2014 via UART on GPIO20 &21
 * Shiela Dixon, https://peacockmedia.software
 *
 * much of what's in this main file is taken from the VGA textmode example
 * from pico-playground/scanvideo which has the licence as follows:
 *
 *
 * Copyright (c) 2020 Raspberry Pi (Trading) Ltd.
 * SPDX-License-Identifier: BSD-3-Clause
 *
 *
 * ... and the TinyUSB hid_app, which has the following licence:
 *
 *
 * The MIT License (MIT)
 *
 * Copyright (c) 2021, Ha Thach (tinyusb.org)
 *
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
 *
 *
 * picoterm.c handles the behaviour of the terminal and storing the text
 *
 *
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
 */

/* MCHobby notes:
   - render on core 1. see #define RENDER_ON_CORE1
*/


#include "main.h"
#include "picoterm_core.h"
#include "picoterm_conio.h"
#include "picoterm_screen.h"
#include "picoterm_config.h"
#include "common/uart_tx.h"
#include "picoterm_cursor.h"
#include "picoterm_stddef.h"
#include "keybd.h"
#include "bsp/board.h"
#include "tusb.h"
#include "hardware/i2c.h"
#include "hardware/uart.h"



/* picoterm_cursor.c */
extern bool is_blinking;

// This is 4 for the font we're using
#define FRAGMENT_WORDS 4

static bool is_menu = false;   // switch between Terminal mode and Menu mode
static uint8_t id_menu = 0x00; // toggle with CTRL+SHIFT+M


//CU_REGISTER_DEBUG_PINS(frame_gen)
//CU_SELECT_DEBUG_PINS(frame_gen)

#define BTN_A 0
#define BTN_B 6
#define BTN_C 11

typedef bool (*render_scanline_func)(struct scanvideo_scanline_buffer *dest, int core);
bool render_scanline_test_pattern(struct scanvideo_scanline_buffer *dest, int core);
bool render_scanline_bg(struct scanvideo_scanline_buffer *dest, int core);


#define vga_mode vga_mode_640x480_60

#define COUNT 80

// for now we want to see second counter on native and don't need both cores

#define RENDER_ON_CORE1


render_scanline_func render_scanline = render_scanline_bg;

#define COORD_SHIFT 3
int vspeed = 1 * 1;
int hspeed = 1 << COORD_SHIFT;
int hpos;
int vpos;


#if 0
static const int input_pin0 = 22;
#endif


// this is how a line of 8 bits is stored

uint32_t block[] = {
                    PICO_SCANVIDEO_PIXEL_FROM_RGB5(0,0,0) << 16 |
                    PICO_SCANVIDEO_PIXEL_FROM_RGB5(0,0,0),
                    PICO_SCANVIDEO_PIXEL_FROM_RGB5(0,0,0) << 16 |
                    PICO_SCANVIDEO_PIXEL_FROM_RGB5(0,0,0),
                    PICO_SCANVIDEO_PIXEL_FROM_RGB5(0,0,0) << 16 |
                    PICO_SCANVIDEO_PIXEL_FROM_RGB5(0,0,0),
                    PICO_SCANVIDEO_PIXEL_FROM_RGB5(0,0,0) << 16 |
                    PICO_SCANVIDEO_PIXEL_FROM_RGB5(0,0,0)
};



extern picoterm_config_t config; // Issue #13, awesome contribution of Spock64

extern const lv_font_t nupetscii_mono8; // Declare the available fonts
extern const lv_font_t cp437_mono8;
extern const lv_font_t nupetscii_olivetti_thin; // Declare the available fonts
extern const lv_font_t cp437_olivetti_thin;

const lv_font_t *font = &nupetscii_mono8;


// to make sure only one core updates the state when the frame number changes
// todo note we should actually make sure here that the other core isn't still rendering (i.e. all must arrive before either can proceed - a la barrier)
//auto_init_mutex(frame_logic_mutex);
struct mutex frame_logic_mutex;

#if 0
static int left = 0;
static int top = 0;
static int x_sprites = 1;
#endif

void init_render_state(int core);

void render_loop() {
    /* Multithreaded execution */
#if 0
    static uint8_t last_input = 0;
#endif
    static uint32_t last_frame_num = 0;
    int core_num = get_core_num();
    assert(core_num >= 0 && core_num < 2);
    //printf("Rendering on core %d\n", core_num);

    while (true) {
    scanvideo_scanline_buffer_t *scanline_buffer = scanvideo_begin_scanline_generation(true);
        // do any frame related logic
        // todo probably a race condition here ... thread dealing with last line of a frame may end
        // todo up waiting on the next frame...

        mutex_enter_blocking(&frame_logic_mutex);
        uint32_t frame_num = scanvideo_frame_number(scanline_buffer->scanline_id);
        // note that with multiple cores we may have got here not for the first scanline, however one of the cores will do this logic first before either does the actual generation
        if (frame_num != last_frame_num) {
            // this could should be during vblank as we try to create the next line
            // todo should we ignore if we aren't attempting the next line
            last_frame_num = frame_num;
            hpos += hspeed;
        }
        mutex_exit(&frame_logic_mutex);
        //DEBUG_PINS_SET(frame_gen, core_num ? 2 : 4);
        render_scanline(scanline_buffer, core_num);
        //DEBUG_PINS_CLR(frame_gen, core_num ? 2 : 4);
#if PICO_SCANVIDEO_PLANE_COUNT > 2
        assert(false);
#endif
        // release the scanline into the wild
        scanvideo_end_scanline_generation(scanline_buffer);
        // do this outside mutex and scanline generation
    } // end while(true) loop
}

struct semaphore video_setup_complete;

void setup_video() {
    scanvideo_setup(&vga_mode);
    scanvideo_timing_enable(true);
    sem_release(&video_setup_complete);
}

#define TEST_WAIT_FOR_SCANLINE

#ifdef TEST_WAIT_FOR_SCANLINE
  volatile uint32_t scanline_color = 0;
#endif

uint8_t pad[65536]; // to check!!!

#define FONT_MAX_HEIGHT 15
#define FONT_WIDTH_WORDS FRAGMENT_WORDS
#define FONT_HEIGHT (font->line_height) // Should be identical accross all fonts.
#define FONT_MAX_SIZE_WORDS (FONT_MAX_HEIGHT * FONT_WIDTH_WORDS)
#define FONT_SIZE_WORDS (FONT_HEIGHT * FONT_WIDTH_WORDS)

uint32_t *font_raw_pixels = NULL;

void select_graphic_font( uint8_t font_id ){
  /* Assign GRAPHICAL font (nupetscii, cp437) by reassigning the `font` pointer */
  if(font_id == FONT_ASCII) // ignore for ANSI
    return;
  if(font_id == FONT_NUPETSCII_MONO8){
    font = &nupetscii_mono8;
    return;
  }
  if(font_id == FONT_CP437_MONO8){
    font = &cp437_mono8;
    return;
  }
	if(font_id == FONT_NUPETSCII_OLIVETTITHIN ){
		font = &nupetscii_olivetti_thin;
		return;
	}
	if(font_id == FONT_CP437_OLIVETTITHIN ){
		font = &cp437_olivetti_thin;
		return;
	}
}
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

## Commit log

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2023-07-17 Apple-1: small improvements - added some comments - write protection for ROM area - fixed missing delay on non-printable characters - improved handling of meta keys - improved output of speed test - 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
2023-07-17 fixing minor mistakes: - 6502 does not have the BRA OpCode, replaced with JMP - typo in Apple-1 doc - added note about Pico-SDK dependencies
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2023-08-05 couple of small updates - MCP can now handle banking of 65816 - script to download docs fixed - docs updated - improved build process for building releases on github
    [cpu_detect.c]
2023-08-10 non-functional new feature: "pin info"
    picotool info -a <name>.uf2
    now shows correct fixed pin information
    [bus_rp2040_purple.c, rp2040_purple.h]
2023-08-11 a couple of handy changes - binaries now show "Fixed Pin Information" in picotool - removed unused wozmon header file MCP: - added flash size detection - fixed problems in CPU detection - "cpu" comma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
    [bus_rp2040_purple.c, cpu_detect.c, rp2040_purple.h]
2023-08-13 updated PCB design - added decoupling capacitor to 65C02 board - replaced simple connectors with real RP2040 Purple component - also updated gerber file and PDF exports from PCB changes - fixed probl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
    [Pico.skp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]
2023-08-14 couple of small changes - fixed Makefile for specific usecase - fixed typo in gpio_oc.h - moved blink_test to another project, as it is obsolete here now
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2023-08-27 Native core small improvements - start of a menu system (not working yet) - WozMon not prints backspace correctly - removed unnecessary function PCB: RP2040 purple footprint now also has USB connecto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
2023-11-25 Native core is moving from test to alpha state
    common:
    - fake_eeprom removed, because it'll interfere with native internal drive
    and was also not multicore safe
    - this required a small change in MCP
    native only:
    - added flash wear level code "dhara"
    - added API for accessing new internal drive
    - updated documentation with new I/O registers
    - event queue guarded with mutex
    - ROM will be also loaded from raw flash
    - all flash addresses can be displayed using "picotool info"
    - added host tool from FUZIX fork to create dhara image from binary image
    and finally:
    - fixed problem SDK was built using wrong board config
2023-11-26 rework dhara related tool
    - removed all parameters, take config from rp2040 code
    - renamed a few defines
    - renamed to dharatool
    - dharatool can now also take dumped image to convert it to raw binary
    - native ROM got print string routine
    - Makefile now explicitly states a successful build
    - added script to run clean test build
2023-12-04 added missing ccp.sys for CP/M-65
    also switched documentation from VT52 to VT100, which will be more
    compatible
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2023-12-06 native: added switch for locating "SBC23" in boot track
    - either at $E000 (sector $00, offset $00) or $FFF5 (sec. $3f, off. $75)
    - watchdog re-triggering did not work as expected
    - added VSCode C++ configs
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2023-12-07 native: a couple of fixes and workaround
    - changed bootsignature to be searched at $E003
    - update cpm_rom.bin
    - forced rebuild of cpmfs
    - reading bank register did always return 0, not current bank
    - mkcpmfsimage.sh not also sets correct attributes of ccp.sys
    - upload was assembling the UF2 to upload before building
    ...but still, CP/M-65 does not boot from plain internal drive
2023-12-12 native: quite some clean up
    - the usage of mutex for event queue cut performance down to half
    - mutex removed and replaced by design decisions to ensure thread safety
    - core 0 (console) is only one allowed to set RDY line
    - core 0 is not allowed to use event queue
    - mutex is changed to #define, just in case
    - a few changes to native_rom
2023-12-13 native: getting towards release
    - CP/M-65 bootloader gets not linked using cl65
    - timers are now handled correctly
    - DEL character ($7f) is properly handled during output and WozMon input
    - rp2040 console knows type of invokation: key, trap, watchdog
    - menu stub removed
2023-12-13 native: some small reworks
    - added convenience function in the kernel
    - print 16 bit hex value
    - wait for key from UART and make it uppercase
    - small changes to monitors to use new functions
    - fixed typo in doc/native.md
2023-12-16 native: few minor changes and fixes
    - added memory check to figure out bad soldering
    - fixed NMOS 6502 detection in kernel
    - fixed stupid bug in native_writeboot
    - CP/M: dinfo.com replaced with fixed version
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2023-12-25 native: updates workaround for building CP/M stuff
    - also added non-functional vt100 tty driver
    - long due reorder of zero page addresses used
    - fixed usage of BIOS print address
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2024-01-03 native: several minor updates
    - fixed bug in software interrupts: operand was fetched from kernel bank
    - cpmfs: load/directory set $030E/F with end address
    - removed unnecessary parameter from building CPM code
    - docs updated
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2024-01-09 native: fix and improvement to build CP/M 65
    The build now checks for the CP/M 65 build in external-build and enables
    building of CP/M 65 tools if available. Also fixed path to cpmemu required
    for assembling.
    Also added precompiled Tali Forth 2 and updated CP/M 65 binaries.
2024-01-11 65c02-toolchain: generate labels files
    - kernel software interrupt handler did not handle interrupts >=$80
    correctly
    - non functional clean-ups
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2024-01-17 native: CP/M-fs now sets filesize correctly in filesystem entry
    However, still a full sector is saved and loaded, so partial sector use
    will destroy up to 127 bytes of RAM after the loaded file!
    [rp2040_purple.h]
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2024-09-13 more work on disassemble code
    - tables for other 65xx cpus added (still incomplete)
    - reworked cpu detect code to also detect 65CE02
    [opcodes6502.csv, opcodes65816.csv, opcodes65ce02.csv]
2024-09-15 kernel update
    - when detecting NMOS 6502, display error message and drop to WozMon
    - WozMon also put back to plain NMOS 6502 code
    - small updates to CPU detect code in MCP
    [cpu_detect.c]
2024-09-17 another round of bug fixes
    - disassembler: fixed enum masking
    - core1: added forth byte for disassembly of 65CE02's AUG opcode
    - mcp: retry CPU detection on fail
    - 6502 opcode table: added some extra clock cycles
    [opcodes6502.csv]
2024-09-18 couple of updates
    - doc about how 65CE02 does wrong calculations in BCD mode
    - fixed bugs in opcode tables
    - nicer printout of CPU in debug speed info
    - disassembler got 65816 and macros for picking parts of opcode variants
    [opcodes6502.csv, opcodes65816.csv, opcodes65c02.csv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]
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2024-10-01 another round of tying up loose ends
    - cc65-sdk is now in top level and will be included in a release
    - doc/cpu_detect.md got a major update with a flowchart
    - also cpu detection now has support for 6502 Rev.A (without ROR)
    - fixed warnings in wozmon.c
    [sorbus.cfg]
2024-10-02 still trying to get things a bit more smooth
    - better integration of SDK during full build
    - removed redundant code out of crt0.s
    - updated doc/cpu_detect.md (not for the last time)
    - removed workaround for CPU detection, now there's a bugfix
    - fixed a few annoying typos
    [cpu_detect.c]
2024-10-03 Updating documentation on CPU detection
    - found an error in the opcodes: RTI takes only 6 cycles, not 7
    - CPU detection debug now has better line numbering
    [opcodes6502.csv, opcodes65816.csv, opcodes65c02.csv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]
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2024-10-05 final chunk of deadline partycoding
    - Makefile utilizes llvm-mos-sdk built by shell script
    - removed trailing spaces
    - small bug fixes
    [cpu_detect.c]
2024-10-07 addition of instant assembler by Alan Cashin
    Instant 6502 Assembler was originally written for the KIM-1 and
    reconstructed using the acme assembler. This is a port to the ca65 as
    assembler and Sorbus as platform. The port is elegant in a way that the
    routines called by instant assembler in the KIM-1 have been reimplemented
    for the Sorbus.
    So by flipping a switch in the source code, the KIM-1 version can still
    be assembled. (Theoretically, since it was not tried.)
2024-10-09 housekeeping for next release
    - port of Microsoft OSI BASIC now more compatible to the original
    - changed text input to kernel routine
    - USR() now uses original addresses
    - A,X,Y are now passed to and from SYS using memory $0D,$0E,$0F
    - DIR now is LOAD"$"
    - updated basic files, since token order was changed
    - write to $DF04 for timestamping
    - fixed bug in upstream TaliForth2
    - link to the review of Hans Otten
    - fixed some minor typos
    [opcodes6502.csv, opcodes65c02.csv, opcodes65ce02.csv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]
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2024-10-12 OSI BASIC removed unnecessary features
    - since output is on VT100, changed character in line counting code
    - will not work when writing to printer of a file (unimplemented anyway)
    - also removed unused zero page variables
    - now 5 bytes in zero page and more than 200 bytes of ROM are available
2024-10-14 another round of improvements and bug fixes
    - OSI BASIC was having problems accessing variables and running RND(0)
    - wozmon is now using $08-$0f for storage, as zero page usage was
    originally recommended starting at $10
    - added few details to Native Code doc
    - added small VT100 test: terminal size
    - added 65c02 code for counting cycles for later use
    - improved hexdump function (split in two for more fitting use)
    - hexdump of memory now also available in meta menu
    [cpu_detect.c]
2024-10-16 preparing release for VCFB
    - better naming of directory for sx4 code
    - improved "10print.bas" example
    - added new C programs
    - minimal code cleanup
    - fixed OSI BASIC's INPUT command with empty input and ctrl+c
    - ported PEEK_SAVE_LINENUM fix from later versions to OSI BASIC
    - added BASIC program "hunt the wumpus"
    - added "10print" variants written in BASIC, C, and assembler
    - updated CPU detection document
    [opcodes65ce02.csv]
2024-10-17 preparing VCFB release
    - another update to documentation: cpu detect, native, 65SC02 opcodes
    - another test for int-test.sx4: generate sine
    - short script to dump filesystem
    [opcodes65sc02.csv]
2024-10-22 couple of fixes and inspirations brought from VCFB
    - TIM has gotten a workaround to support same input (LH) as output (WH)
    (why is the output prefixed with ";", but the input requires ":"?)
    - inst-ass got a few things ironed out, now also runs on NMOS 6502
    - new tool "historian" to run disassemble_historian on host system
    - new hidden function in meta menu: "!" will dump the trace in format
    for offline testing disassemble_historian
    - disassemble_historian improved
    - new tool "timcat" to upload to Sorbus memory from command line using TIM
    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
    [opcodes6502.csv, opcodes65816.csv, opcodes65c02.csv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]
2024-10-25 work on historian
    - historian test suite set up and verified
    - further improvements on historian
    - instant assembler minor cleanup
    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
    [opcodes6502.csv, opcodes65816.csv, opcodes65c02.csv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]
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2024-11-03 WozMon of Apple //c ported
    - right now as SX4, intended to be moved to ROM when stable
    - cpmfs and vt100 interrupts now buffer page $0200 before using
    - WozMon1 got an alias "G" for "R" to be compatible with WozMon2c
    - meta submenus also can be canceled with Ctrl+]
    - historian got another rule for handling JMP() when sure
    - fixed two typos in cpu_detect.md (thanks Peter!)
2024-11-03 a couple new features
    - disassemblies in meta menu now work as expected
    - added convenience function for VT100 getting screen size
    - int-test now uses VT100_SCRN_SIZ as well
    - bootblock loading should now be working with NMOS 6502
    - when loading bootblock fails, drop to WozMon
    (this is for a later change when an NMOS 6502 bootblock will be available)
    - WozMon2c got a couple of todos ticked off
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2024-11-10 continuing rewrite of line input call
    - INCOMPATIBLE CHANGES:
    - input: Y bit7 no longer defines uppercase conversion
    - input: Y bit7 now reserved for expanded input routine
    - output: Z=1 (instead of C=0) if input was completed by pressing return
    - output: A: key pressed to leave (Ctrl-C, ESC, CRSR-up/down, etc)
    - all software has been adjusted
    - line input also move to own source code file
    - expanded int-test for new line input features
    - OSI BASIC: compile switch for turning tokens to lowercase when LISTed
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2024-11-20 System Monitor update: assemble
    - rest of System Monitor code also got updates
    - cosmetic changes in WozMon2c
    - line input bug fix: 2x home jumped to start of line, not input
    - line input feature: CTRL-D/DELETE key now deletes char under cursor
2024-11-26 another couple of small fixes
    - assembler now does not fail on ZP addresses followed by ',' or ')'
    - VT100 now has convenience function CLR/HOME
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2024-12-08 another set of smaller changes
    - bugfix in gensine: offset was not recognized
    - int-test got a test for System Monitor
    - OSI BASIC can now set case for LIST
    - moved write bootblock tool to SX4
2024-12-09 Completing some leftovers
    - System Monitor updates
    - new memory related commands: compare, fill, hunt, transfer
    - bug fix in calculating area to hexdump
    - moved documentation to own file
    - tools bank now got dedicated trampoline code
    - workaround added for system locking up when writing to internal drive
    that was fixed with Pico-SDK 2.1.0
2024-12-13 reorganizing filesystem structure
    - easier recognition of what belongs together
    - renamed "Native Core" to "JAM Core" (Just Another Machine)
    - removed some workarounds in build system
    - fixed a few problems in helper script
    - added script to build everything from scratch including dependencies
    [sorbus.cfg]
2024-12-14 Non functional changes: update from "native" to "JAM" in texts
    [main.c]
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2024-12-19 fixes for compile warnings and CMake problems
    - CMake wrappers needed to be macros because of "PARENT_SCOPE"
    - fixed compiler warnings not seen before last commit
    [main.c]
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2024-12-31 JAM: speeding up 65c02 clock by 7.5%
    When doing comparisons on ARM it's always better to work with 8bit values
    especially in tight loops.
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2025-01-24 cc65-sdk fixed
    - cc65-sdk now works with fb32x32
    - cc65-sdk separated out setting of variables for extern projects
    - fb32x32 bugfix in dmacopy with transparency
    [Makefile.cfg]
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2025-02-07 bug fixed in fb32x32
    - finally found that annoying bug in fb32x32 PIO code
    - switched chipset bus description to single source for bitmasks
    - disabled LED of rp2040_purple.h for not showing up in picotool info -a
    - added uart_tx for printf-debugging over single wire (for later use)
    [bus_rp2040_purple.c, rp2040_purple.h, uart_tx.c]
2025-02-09 added BOM & prices list
    - fixed some formatting and comments
    - fb32x32 LEDs is now also buffering the colortab
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2025-04-15 implemented sound io-test, but does not work so far
    - clean up of PIO and C code
    [main.c]
2025-04-15 Fixed gpio on sound-mod, fixed timing on sidkick, common gpio-init
    [sound_gpio_config.c]
2025-04-15 some work on PIO for debugging
    - sound-iotest doesn't work as expected
    - renamed fb32x32bus for consistency
    [main.c, vga_bus.c]
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2025-04-15 Fixed Makefile
    - removed workaround for VS Code build
    - added dependency for pico-extras
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2025-08-18 couple of small updates piled up
    - creation of debug output in cc65-sdk
    - add fb32x32 program for Conway's game of life
    - clean up of system includes
    - bugfix in kernel FB32X32 clear screen now works
    - removed unused code and local labels
    - added linker output of memory usage
    [Makefile.cfg]
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2025-11-05 rework of disassembler in meta-mode
    - moved CPU variant specific config to the end
    - switched mnemonic from string pointers to enum
    - removed prefetch assumption, which only is valid for NMOS 6502
    [opcodes6502.csv, opcodes65816.csv, opcodes65c02.csv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]
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2025-11-22 rework on couple of mcurses functions
    - title logo(!)
    - renamed functions from screen_* to mcurses_* when mcurses is used
    - more consistant naming of types/structs
    - few comments added
2025-11-22 JAM new feature: automated UTF-8 conversion for characters > $80
    [main.c]
2025-11-24 a couple of small fixes and non-functional changes
    - docs updates, most are just formatting
    - some comments in 65c02 code
    - removed CRs from source code
2025-11-26 fixed a couple of problems with disassembler
    - errors in opcode table of 65CE02
    - not wrapping relative addressing
    - broken disassembler on wraparound
    - host toolchain now compiles for debugging always
    [opcodes65ce02.csv]
2025-11-27 added some incomplete optional static code analysis
    - also fixed some findings like 34 missing 'l' in printfs
    [rp2040_purple.h]
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2025-12-09 Improving upscrolling in mc_disass
    also adding a couple of dangling changes
    - docs for meta-mode
    - bug in disassembler comparison
    - meta-mode now shows version on 'V'
    - out-of-bounds write in mc_disass
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2025-12-28 some changes fresh from 39C3
    - fix in cycles for 65CE02
    - added 50% CPU boost flag by clocking 200MHz instead of 133MHz
    - adjusted comments in JAM 65C02 kernel
    - updated opcode docs for 65CE02
    [opcodes65ce02.csv]
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2026-06-07 doc: major update for opcode tables and disass traces
    - doc/traces/*.ref have become obsolete with new disass
    - corrected some details in opcode table for 65ce02
    - added page for observed behavior of 65816
    - stripped off leading stray samples from trace, so no every trace starts
    at an opcode or reset
    - update mkdocs.sh to include jump for opcode tables
    - fixed few minor bugs
    [opcodes65ce02.csv]
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2026-06-09 tools: another rework session in trace test programs
    - updated testcases with cpu variant information -> no need for "-c" option
    - reorganized host sorbus runtime environment
2026-06-10 src/rp2040+tools housekeeping
    a couple of smaller tasks
    - switched 65816 internal flags to lowercase to differentiate from RNIS
    - fixed bug in fullinfo.dataused, which was always 3
    - removed obsolete opcode pointer in da_trace_t
    - removed long defunct mcurses test tool
    - fixed help messages in host test tools for new disassember
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2026-06-17 reworked bankswitching functions
    Now five different variants for bankswitching are provided:
    - BRK
    - bankstart
    - bankjsr
    - bankjmp
    - bootblock
    Each custom implemented for a specific use case.
    Documentation got it's own chapter for bankswitching
2026-06-18 housekeeping again and a bugfix
    - forgot a part when adding a new bank for forth
    - another BASIC demo added: mandelbrot
    - TaliForth2 rolled back a version since the current one didn't work
    - small improvements in disassembler cycle counter for 65816
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2026-06-29 fixed three minor bugs
    - trace viewer couldn't handle traces < screenheight
    - disassemble memory couldn't display $7F as text
    - terminal window resize in meta-mode breaks output until leave and reenter
    -> mitigation: output only broken until going back to menu
2026-07-01 fixed a couple of minor problems detected by clang-tidy
    [cpu_detect.c]
2026-08-24 doc: updates to current state and note about being unstable right now
2026-08-24 jam: new interrupt routine ASCEND256
    calling BRK #$13 now writes an ascending number to a memory page X
    Why? Because than you can do bitwise operation with index registers:
    ldx #$cf
    int ASCEND256
    [...]
    and $cf00,x
    now works like and "and with X register". Good tip from Atari Age forums,
    but I can't find the posting anymore.
2026-09-06 JAM: major rewrite of communication of internal components
    This is the first step of a major rewrite. It compiles, but is untested.
    See documentation JAM -> Internal Core Messaging for details.
    This also results in a few API changes, e.g. freezing the cycle counter is
    now triggered by write instead of read. The documentation JAM -> Memory
    Map & I/O Registers has been updated accordingly. Also JAM -> Kernel
    Routines has been split out.
    [cpu_detect.c]
2026-09-06 cleaning up after rewrite
    - still problem with new fifo256 functions
    [main.c]
2026-09-08 JAM: fixes on dhara and UART
    [main.c]
2026-10-13 major rewrite, most internal I/O is now asynchronous
    - all internal I/O except for banking is asynchronous now
    - some additional handshaking might be required
    - hammering on I/O will lead to fifo overflow
    - not everything is ported yet
    - clock cycle based event handler has been removed
    - functions more modularized
    - internal errors now trigger meta menu with item to display details
    - UART queues replaced with minimal fifo implementations
    - noticeable performance boost: ~1.2MHz -> ~1.8MHz
    - clock should also be more stable now
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2026-10-14 fixed quite a bunch of timer issues
    Rewrite of ms based timers left quite some bugs. At least most of them
    should be fixed now.
    Also:
    - fixed race condition in clock example caused by switch to asynchronous
    - watchdog re-implemented as time-based (with small test program)
    - freeze/unfreeze of (time-based) timers/watchdog when entering meta-menu
    - added forgotten short to sizeof.c example
    - added watchdog info to timer info in meta-menu
2026-10-18 JAM/RP2040: trying to improve I/O IRQ handler performance
    Because when polling for a register to wait for an action causes the
    multicore fifo to overflow, trying to find some counter measures for the
    IRQ handler to return as fast as possible.
    Best choice would be to have read triggers only in the range $DF00-$DF0F,
    so any reads >=$DF10 would not need to be processed. However, this needs
    to be solved in the future, after bus_run() was ported to assembly.
    For now try some other counter meastures:
    - splitting reads and writes into different handlers
    - parameter for the handlers is now raw uint32_t data
    - trying to rely on alarms for the heavy work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
2026-10-19 JAM/RP2040: uart queue sizes will be updated regularly
    - this prevents overwriting
    - also fixed typo
2026-10-19 JAM/RP2040: reset bank number on overflow
    An overflow of the bank id is handled already correctly: switch to bank 1.
    However the wrong number still stayed in the register. This will be now
    corrected.
2026-10-19 JAM/RP2040: code cleanup
    removed manual reset of UART registers on reset, as the whole internal
    I/O area will be cleared
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2026-10-20 JAM/RP2040: new meta-menu option: show screen
    Switches to saved screen, waits for keystroke and then switches back
2026-10-20 JAM/RP2040: get a slight performance boost for internal drive
    Now the check if there's something that needs to be done for the internal
    drive is now outside the function being called. This speeds up the loop
    with also UART a bit, so the UART is also a bit more stable.
2026-10-21 jam/rp2040: moved some UTF-8 glyphs around
    Now "10 print" from Commodore VIC-20/C-64 handbook should work, once
    the default 8-bit output was changed from "native UTF-8" to "codepage1"
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2026-11-03 rp2040/jam: adding assembly functions
    in the longer term, two important functions will be ported from C to
    RP2040/Cortex-M0+/ARMv6-M assembly:
    - the tight bus loop
    - the IRQ handler dispatching C function calls as sent by the bus core
    this is the first step: add untested and partially implemented to the
    build process, so it can be at least checked that it compiles/assembles
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

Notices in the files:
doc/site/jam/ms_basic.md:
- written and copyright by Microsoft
